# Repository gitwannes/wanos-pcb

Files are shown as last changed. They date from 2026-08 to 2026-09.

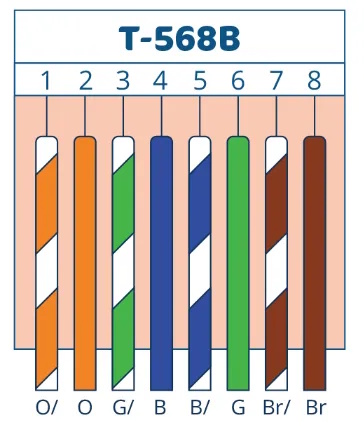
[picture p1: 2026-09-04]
docs/reference/datasheets/rj45-t568b-wiring-colors.jpg

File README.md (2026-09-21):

# wanos-pcb



KiCad design and JLCPCB fabrication for **wanos-pcb-v1** — first-generation WanOS Pi carrier.

**Today:** WanOS runs on **WISC** boards (legacy reference in-repo). **Target:** **wanos-pcb-v1** + updated **wanos**. Code → [gitwannes/wanos](https://github.com/gitwannes/wanos).

---

## Repository layout

```text
wanos-pcb/
├── docs/
│   ├── board-spec.md            # wanos-pcb-v1 electrical spec (canonical)
│   ├── remotepcb.md             # wanos-remote plant module
│   ├── field-wiring.md          # JST pinouts + Cat5
│   ├── gpio-interface.md        # Pi BCM map (R2)
│   ├── external-plant.md        # Off-board SSR + 12 V
│   ├── grounding.md
│   ├── reference/
│   │   ├── datasheets/          # PDF pack (gitignored binaries)
│   │   ├── silkscreen/
│   │   └── wisc-board/
│   └── todo/
├── projects/wanos-board/        # Main Pi carrier
│   ├── wanos-board.kicad_pro
│   ├── components.xlsx          # BOM: column board = main | remote
│   └── …
├── projects/wanos-remote/       # Plant remote (pulse + 1-Wire)
│   ├── wanos-remote.kicad_pro
│   ├── wanos-remote.kicad_sch
│   └── design.yaml
└── README.md
```

---

## Pipeline (summary)

| Step | Id | What |
|---|---|---|
| ~~…~~ | ~~**R / Ops1 / S / Gate-S1**~~ | ~~Requirements + main schematic~~ **Done** **2026-09-21** |
| **1** | **Ops-Remote1** | Operator: clean + check **wanos-remote** schematic |
| **2** | **L1** | Main carrier PCB layout |
| **3** | **Gate-L1** | Layout sign-off |
| **4–5** | **Ops2, J1** | Fab readiness + JLCPCB order |
| **6** | **Ops3** | Receiving inspection |
| **7–8** | **V1a, V1b** | Bring-up / extended software |

Full backlog → [`docs/todo/pipeline.md`](docs/todo/pipeline.md).

---

## Quick links

| Doc | Purpose |
|---|---|
| [`docs/board-spec.md`](docs/board-spec.md) | **wanos-pcb-v1** specification |
| [`docs/remotepcb.md`](docs/remotepcb.md) | **wanos-remote** plant module |
| [`docs/gpio-interface.md`](docs/gpio-interface.md) | Pi BCM + software strategy (**wanos-pcb-v1**) |
| [`docs/gpio-map.md`](docs/gpio-map.md) | WISC production BCM inventory |
| [`docs/external-plant.md`](docs/external-plant.md) | DIN SSR + 12 V plant |
| [`docs/field-wiring.md`](docs/field-wiring.md) | Connector pinouts |
| [`docs/schematic-signoff.md`](docs/schematic-signoff.md) | Gate-S1 record (Done) |
| [`docs/reference/datasheets/README.md`](docs/reference/datasheets/README.md) | Datasheet pack |
| [`docs/kicad-setup.md`](docs/kicad-setup.md) | Konnect + KiCad 10 (**Ops1** Done) |
| [`projects/wanos-board/components.xlsx`](projects/wanos-board/components.xlsx) | BOM / LCSC seed |

---

## Workflow

1. ~~**`kickoff` / S1 / Gate-S1**~~ — **Done** (schematic signed **2026-09-21**).
2. **Ops-Remote1** — operator cleans + checks [`projects/wanos-remote/`](projects/wanos-remote/).
3. **`implement` L1** — main carrier layout (after Gate-S1).
4. **`V1a`** — board + updated **wanos**; cutover from WISC.

**DoD (every phase):** audit all `docs/**/*.md` + this README.

---

## Related repos

| Repo | Role |
|---|---|
| [gitwannes/wanos](https://github.com/gitwannes/wanos) | Runtime (WISC today; wanos-pcb-v1 at **V1a**) |
| [Konnect](https://github.com/mixelpixx/Konnect) | KiCad MCP automation |

---

## License

Source available — personal use OK, no redistribution. See [LICENSE](LICENSE).

Copyright (c) 2026 [Johan Wannes Hofmans](https://github.com/gitwannes). All rights reserved.

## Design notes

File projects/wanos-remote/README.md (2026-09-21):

<!-- --- file: projects/wanos-remote/README.md --- -->

# wanos-remote

Universal plant remote PCB: **4×** opto pulse + **4×** DS18B20 (DS2482-800), Cat5 to main **TCA9548A**.

| Doc | Role |
|---|---|
| [`docs/remotepcb.md`](../../docs/remotepcb.md) | Canonical design locks |
| [`design.yaml`](design.yaml) | Project intent |
| [`components.xlsx`](../wanos-board/components.xlsx) | BOM — filter **`board=remote`** |

## KiCad

- Project: `wanos-remote.kicad_pro`
- Schematic: `wanos-remote.kicad_sch` (A3)
- Symbols: `wanos-remote.kicad_sym` (DS2482-800, TLP281-4)
- Regenerate schematic: `python projects/wanos-remote/_regen_schematic.py`

## Instances

| Board | Mux | Use |
|---|---|---|
| #1 | U5 ch 5 | 4× water YF + 2× pipe temp |
| #2 | U5 ch 6 | 2× kWh S0 + 1× temp |

Same PCB / same I²C straps (`MCP 0x22`, `DS2482 0x18`). Never enable ch 5 and 6 together.

## Status

Schematic **v0.1** — **Ops-Remote1** (operator): clean in KiCad, run ERC, check vs [`docs/remotepcb.md`](../../docs/remotepcb.md). Layout not started (40×60 hold).

Pipeline: [`docs/todo/pipeline.md`](../../docs/todo/pipeline.md) Sequence #1.

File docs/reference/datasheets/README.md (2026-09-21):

<!-- --- file: docs/reference/datasheets/README.md -->

# Datasheet pack — wanos-pcb-v1

Operator reference PDFs for board design, JLCPCB ordering, and external-plant documentation.

**Home:** `docs/reference/datasheets/` (not under `projects/` — PDFs are reference material, not KiCad project outputs).

**Git:** large PDF binaries may be local-only; keep this README as the checklist. Drop PDFs in this folder locally.

**Naming:** all PDF/JPG filenames **lowercase** (ASCII).

---

## Inventory

### On-board ICs and semiconductors

| Done | Part | Filename |
|:---:|---|---|
| [x] | NXP **PCA9554PW** (I/O expander) | `pca9554.pdf` |
| [x] | TI **TCA9548A** (I²C mux) | `tca9548a.pdf` |
| [x] | **PC817A** (12 V opto, U4) | `pc817a.pdf` |
| [x] | **PN2222A** (SSR driver) | `pn2222a.pdf` |
| [x] | **SMBJ12A** (12 V TVS, **D3**) | `smbj12a.pdf` |
| [x] | **PESD5V0S1BA** (water SIG TVS, **D25**–**D28**) | `pesd5v0s1ba.pdf` |
| [x] | **SMBJ5.0A** (water **`+5VA`** TVS, **D29**) | `smbj5.0a.pdf` |
| [x] | **BLM21PG331SN1** (Pi 5 V ferrite) | `blm21pg331sn1.pdf` |

### Connectors

| Done | Part | Filename |
|:---:|---|---|
| [x] | Molex **208658-1052** (HDMI J1, LCSC **C6990958**) | `molex-208658-1052.pdf` |
| [x] | JST **XH** series (B2B/B4B/B5B/B6B-XH-A, 2.50 mm) | `jst-xh-series.pdf` |
| [x] | **KF301** screw terminal (J14 2P) | `kf301.pdf` |
| [x] | 2×20 **40-pin** female header (J40) | `40-female-header.pdf` |
| [x] | Amphenol **54602** RJ45 (KiCad footprint class for **J4**) | `amphenol-54602.pdf` + `amphenol-54602-drawing.pdf` |
| — | TE **5556416-1** (orderable **J4** MPN) | **Not required** — BOM/LCSC is enough; Amphenol **54602** docs are the land-pattern authority for the KiCad fp |

### Field wiring aids

| Done | What | Filename |
|:---:|---|---|
| [x] | T568B colour reference (water Cat5 → **J4**) | `rj45-t568b-wiring-colors.jpg` |

### Plant and external (for `docs/external-plant.md`)

| Done | Part | Filename |
|:---:|---|---|
| [x] | Omron **G3PJ-225B DC12-24** (DIN SSR) | `external/omron-g3pj.pdf` |
| [x] | **SHT3x** (Sensirion — SHT31 plant sensor) | `external/sht3x.pdf` |
| [x] | **YF-B6 / YF-B10** water flow sensor | `external/YF-B6 B10 waterflow-sensor.pdf` |
| [x] | Eastron **SDM72D-M** (kWh pulse meter) | `external/sdm72d-m.pdf` |
| [x] | Sibratec **DDS-1Y-18L** (1-ph kWh, S0-style pulse) | `external/dds-1y-18l.pdf` |
| [x] | Finder **7E.12.8.230.0002** (1-ph kWh, SO DIN 43864) | `external/finder-7e.12.8.230.0002.pdf` |

### Pi power (R2 lock — J41 DNP v1)

| Done | Part | Filename |
|:---:|---|---|
| [x] | **BZX85C5V6** family / **BZT52C5V6** (5 V zener, **D1**) | `bzx85c.pdf` |
| [x] | **1N400x** family (legacy reference; reverse block replaced by **Q6** ideal diode on wanos v1) | `1n400x.pdf` |
| [ ] | USB-C receptacle **J41** (LCSC part from `components.xlsx`) | `usb-c-j41.pdf` — **deferred** (J41 DNP v1) |

---

## Relevance notes (water / J4)

| File | Relevant? | Role |
|---|---|---|
| `pesd5v0s1ba.pdf` | **Yes** | SIG TVS **D25**–**D28** on `water_meters.kicad_sch` |
| `smbj5.0a.pdf` | **Yes** | **`+5VA`** TVS **D29** at **J4** |
| `amphenol-54602.pdf` / `-drawing.pdf` | **Yes** | Land-pattern / outline for KiCad fp `Connector_RJ:RJ45_Amphenol_54602-x08_Horizontal` (proxy for TE **5556416-1**) |
| `rj45-t568b-wiring-colors.jpg` | **Yes** | Operator colour aid for [`field-wiring.md`](../../field-wiring.md) § 2a |
| TE **5556416-1** PDF | **Not needed** | Orderable MPN is locked in BOM/LCSC; Amphenol **54602** already covers the footprint you are using |

---

## Status

**On disk:** water TVS pair (**PESD** + **SMBJ5.0A**), Amphenol **54602** fp refs, T568B colour jpg, and plant kWh PDFs (**SDM72D-M**, **DDS-1Y-18L**, Finder **7E.12**) present. Deferred only: **`usb-c-j41.pdf`** (J41 DNP v1).

---

## Related

- BOM seed: [`projects/wanos-board/components.xlsx`](../../projects/wanos-board/components.xlsx)
- HDMI / e-ink: [`hdmi-spi-eink.md`](../../hdmi-spi-eink.md)
- Components: [`component-selection.md`](../../component-selection.md)
- R2 tracking: [`todo/_archive/phaseR-requirements.md`](../../todo/_archive/phaseR-requirements.md) § R2

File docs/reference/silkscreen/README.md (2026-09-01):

<!-- --- file: docs/reference/silkscreen/README.md -->

# wanos-pcb-v1 — silkscreen reference

Silkscreen typography and artwork for **wanos-pcb-v1**, matching legacy **WISC** boards.

---

## PCB font (same as WISC)

Use **Printed Circuit Board 7** on silkscreen labels (connector names, revision text, short field hints).

| Resource | Link |
|---|---|
| **Font (FontSpace)** | [Printed Circuit Board 7](https://www.fontspace.com/printed-circuit-board-7-font-f15777) |
| Shortcut (Windows) | [`PCBfont.url`](PCBfont.url) |

Install the font on the KiCad workstation so PCB Editor can render the same face as WISC production boards.

**KiCad:** set default silkscreen font to this typeface where practical; minimum text height per [`board-spec.md`](../../board-spec.md) § 8.2 (**≥ 1.0 mm**).

---

## Logo artwork (wanos-pcb-v1)

| File | wanos-pcb-v1 |
|---|---|
| [`Wannes-PCB-logo.png`](Wannes-PCB-logo.png) | **Use** — front silk (from WISC library) |
| [`Wisclogo_small`](../wisc-board/211201%20wisc2-5-3/Wannes-library.pretty/Wisclogo_small.kicad_mod) | **Use** — front + back (WISC parity) |
| `W annes illiams.jpg` / inverted variant | Optional author mark |
| [`Cc-by-nc-sa_icon.svg.png`](Cc-by-nc-sa_icon.svg.png) | **Not used** on wanos-pcb-v1 (WISC reference only; repo [`LICENSE`](../../../LICENSE) is not CC) |

Footprint sources live under [`../wisc-board/211201 wisc2-5-3/Wannes-library.pretty/`](../wisc-board/211201%20wisc2-5-3/Wannes-library.pretty/) — copy **Wannes-PCB-logo** and **Wisclogo_small** into `projects/wanos-board/` at **L1 implement**, do not edit reference KiCad trees.

---

## Related

- [`board-spec.md`](../../board-spec.md) § 8 — fab + silk rules
- [`kicad-setup.md`](../../kicad-setup.md) — tooling
- WISC 2.5.3 production summary → [`../wisc-board/wisc-v5-2-5-3-production.md`](../wisc-board/wisc-v5-2-5-3-production.md)

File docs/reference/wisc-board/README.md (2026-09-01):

<!-- --- file: docs/reference/wisc-board/README.md -->

# WISC board reference

Structured notes and **read-only KiCad** projects for legacy **WISC** hardware. **Current WanOS** runs on WISC in the field — mainly the **2.5.3 I/O carrier** plus the **2.6.4 HDMI board** on the Pi that drives **LCD screens**.

**Read-only rule:** Do not edit KiCad sources here — see [`.cursor/rules/wisc-boards-readonly.mdc`](../../../.cursor/rules/wisc-boards-readonly.mdc). New design work lives in `projects/wanos-board/` (wanos-pcb-v1).

**Target spec:** [`board-spec.md`](../../board-spec.md) · **GPIO:** [`gpio-interface.md`](../../gpio-interface.md) · **Field wiring (wanos):** [`field-wiring.md`](../../field-wiring.md)

---

## Reference boards

| Summary | KiCad tree | Role |
|---|---|---|
| [**wisc-v5-2-5-3-production.md**](wisc-v5-2-5-3-production.md) | [`211201 wisc2-5-3/`](211201%20wisc2-5-3/) | **Main I/O carrier** — SSR, doors, meters, SHT11 |
| [**wisc-v2-6-4-hdmi.md**](wisc-v2-6-4-hdmi.md) | [`220313 wisc2-6-4-HDMI/`](220313%20wisc2-6-4-HDMI/) | **LCD Pi** node (85×56); **4-pin I²C J7** pinout reference for wanos |

Fab exports, cache, history, backups → [`_donotcommit/`](_donotcommit/) (gitignored).

---

## How to use

1. **R2 / V1a** — confirm harness parity vs [`field-wiring.md`](../../field-wiring.md).
2. **S1 / L1 implement** — copy **patterns** (SSR 5-pin, JST silk, debounce), not whole schematics, into `projects/wanos-board/`.
3. **4-pin I²C pinout** — use **2.6.4 J7** only (not 2.5.3 SHT11 DATA/CLOCK headers).

Silkscreen font (WISC + wanos) → [`../silkscreen/README.md`](../silkscreen/README.md).

Migration narrative (planned R2): `docs/cutover-wisc-to-wanos-pcb-v1.md`.

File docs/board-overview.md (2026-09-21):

<!-- --- file: docs/board-overview.md -->

# WanOS PCB — overview

**wanos-pcb-v1** is the first-generation WanOS Raspberry Pi carrier board designed in this repo (KiCad + JLCPCB).

| Hardware | Role |
|---|---|
| **WISC 2.5.3** | Main **field-I/O** carrier — SSR, doors, meters, SHT11 ([`reference/wisc-board/`](reference/wisc-board/)) |
| **WISC 2.6.4 HDMI** | **LCD Pi** node — **powers Pi only** today; legacy e-ink **broken** (HDMI not connected) |
| **wanos-pcb-v1** | **New** integrated carrier — replaces split WISC setup + failed HDMI/e-ink path |

Application logic stays in [gitwannes/wanos](https://github.com/gitwannes/wanos). Operator continues on **WISC** until **wanos** is updated for this board (**V1a**). **R1** + **R2** closed **2026-09-01**.

---

## What wanos-pcb-v1 provides

- Digital inputs (doors, water meters, 2× kWh, buttons) via **PCA9554** expanders
- **SHT31 × 5** via **TCA9548A** mux and Cat5 plant cables (~4–5 m); **J16** LCD on root I²C
- SSR drives (3-phase sauna + IR) via Pi GPIO
- **12 V** rail monitoring (optocoupler → Expander B P6)
- **1×** I²C LCD header (two displays paralleled on **J16**)
- WISC e-ink via HDMI→SPI — legacy path failed in the field; see [`hdmi-spi-eink.md`](hdmi-spi-eink.md)
- Status and activity LEDs

Canonical electrical spec → [`board-spec.md`](board-spec.md).

---

## Documentation map

| Doc | Content |
|---|---|
| [`board-spec.md`](board-spec.md) | Full wanos-pcb-v1 electrical / mechanical spec |
| [`field-wiring.md`](field-wiring.md) | JST pinouts, Cat5, mux channels (**R1**) |
| [`component-selection.md`](component-selection.md) | JLCPCB parts and footprints |
| [`hdmi-spi-eink.md`](hdmi-spi-eink.md) | WISC e-ink HDMI→SPI |
| [`io-expander-map.md`](io-expander-map.md) | PCA9554 + TCA9548 map |
| [`gpio-interface.md`](gpio-interface.md) | Pi BCM map + software strategy (**R2**) — **wanos-pcb-v1** |
| [`gpio-map.md`](gpio-map.md) | WISC production BCM inventory (claimed / free / 1-wire) |
| [`remotepcb.md`](remotepcb.md) | **wanos-remote** — plant pulse + 1-Wire module (Cat5 / U5) |
| [`external-plant.md`](external-plant.md) | Off-board SSR + 12 V plant + kWh inventory |
| [`grounding.md`](grounding.md) | Ground / return scheme |
| [`reference/datasheets/README.md`](reference/datasheets/README.md) | Datasheet pack |
| [`reference/silkscreen/README.md`](reference/silkscreen/README.md) | Silkscreen font + artwork |
| [`reference/wisc-board/`](reference/wisc-board/) | WISC summaries + read-only KiCad |
| [`jlcpcb-ordering.md`](jlcpcb-ordering.md) | Fab export checklist |
| [`kicad-setup.md`](kicad-setup.md) | KiCad 10, Konnect, Cursor MCP |
| [`todo/pipeline.md`](todo/pipeline.md) | Delivery pipeline (**Ops-Remote1** → **L1** → …) |

**V1a close-out (planned):** `docs/installer-one-pager.md`, `docs/cutover-wisc-to-wanos-pcb-v1.md`.

---

| Artifact | Location |
|---|---|
| KiCad project (main carrier) | `projects/wanos-board/` |
| KiCad project (**remote**) | `projects/wanos-remote/` |
| BOM seed (`board` = main \| remote) | `projects/wanos-board/components.xlsx` |
| Fabrication outputs | `projects/wanos-board/fabrication/` |

---

## Out of scope (this repo)

- WanOS Python / YAML (main repo)
- WISC legacy PCB **edits** (read-only under [`reference/wisc-board/`](reference/wisc-board/); see [`.cursor/rules/wisc-boards-readonly.mdc`](../.cursor/rules/wisc-boards-readonly.mdc))
- Enclosure mechanical design (no constraint locked at R2)

---

## License

Source available — personal use OK, no redistribution. See [LICENSE](../LICENSE) and [wanos](https://github.com/gitwannes/wanos).

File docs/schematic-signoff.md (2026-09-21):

<!-- --- file: docs/schematic-signoff.md -->

# Schematic sign-off checklist (Gate-S1)

Operator review of **`projects/wanos-board/`** hierarchical sheets before **L1** layout.

**How:** open each `.kicad_sch` in KiCad (or export PDF), check connectivity, refs, and nets vs [`field-wiring.md`](field-wiring.md) / [`board-spec.md`](board-spec.md). ERC: [`projects/wanos-board/wanos-board-erc.rpt`](../projects/wanos-board/wanos-board-erc.rpt).

| Done | Sheet file | What |
|:---:|---|---|
| [x] | [`pi_power.kicad_sch`](../projects/wanos-board/pi_power.kicad_sch) | **J17** + **J14** screw terminals; 5 V conditioning (**F1** / **Q6** / **D1**), **FB1**, **J40**; **D3** TVS; status **D23** / **D24**; 12 V monitor **U4** → Exp B P6 |
| [x] | [`ssr_drivers.kicad_sch`](../projects/wanos-board/ssr_drivers.kicad_sch) | **Q1–Q5**, **R14–R16**, **C8–C12**, **`SAFETY_BUS`** / **J13**; SSR activity **D19–D22** / **R25–R28** (see [`board-spec.md`](board-spec.md) § 4.1, § 5.3) |
| [x] | [`io_expanders.kicad_sch`](../projects/wanos-board/io_expanders.kicad_sch) | **U1**/**U2**, water **J4**, buttons **J8**; legacy door/kWh stubs pending retire |
| [x] | [`pulse_inputs.kicad_sch`](../projects/wanos-board/pulse_inputs.kicad_sch) | Greenfield **J2**/**J3** reed + **J6**/**J7** SDM72 front-ends |
| [x] | [`hdmi_spi.kicad_sch`](../projects/wanos-board/hdmi_spi.kicad_sch) | **J1** HDMI / e-ink SPI |
| [x] | [`i2c_plant.kicad_sch`](../projects/wanos-board/i2c_plant.kicad_sch) | **U5** TCA9548A, **C6**, **R11** RESET pull-up, **J9–J12**/**J18** SHT31, **J16** LCD (root bus) |
| [x] | [`wanos-board.kicad_sch`](../projects/wanos-board/wanos-board.kicad_sch) | Root hierarchy (no separate **Connectors** / **LEDs** sheets) |

**Signed off:** **2026-09-21** / **Wannes** — Gate-S1 closed; S track archived.

**Note:** After sign-off, retire duplicate **J2/J3/J6/J7** stubs on [`io_expanders.kicad_sch`](../projects/wanos-board/io_expanders.kicad_sch) when cutting over to [`pulse_inputs.kicad_sch`](../projects/wanos-board/pulse_inputs.kicad_sch) (operator tidy — not blocking Gate-S1).

Pipeline: [`docs/todo/_archive/phaseS-schematic.md`](todo/_archive/phaseS-schematic.md) (Done) · next Sequence **Ops-Remote1** → [`docs/todo/pipeline.md`](todo/pipeline.md)

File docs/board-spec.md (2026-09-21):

<!-- --- file: docs/board-spec.md -->

# WanOS PCB — board specification

**Revision:** **wanos-pcb-v1** (first-generation WanOS carrier; replaces ad-hoc / **WISC**-era wiring on a new board — not a spin of the old WISC PCB).

Structured specification for KiCad 10 + Konnect, manufactured via JLCPCB. **Target:** **Raspberry Pi 4** on **85 × 56 mm** outline (WISC 2.6.4 mechanical reference).

**Related:** Overview → [`board-overview.md`](board-overview.md) · Components → [`component-selection.md`](component-selection.md) · Field wiring → [`field-wiring.md`](field-wiring.md) · HDMI→SPI → [`hdmi-spi-eink.md`](hdmi-spi-eink.md) · I/O map → [`io-expander-map.md`](io-expander-map.md) · GPIO contracts → [`gpio-interface.md`](gpio-interface.md) · Silkscreen → [`reference/silkscreen/README.md`](reference/silkscreen/README.md)

**R1 locks:** 2026-09-01 · **R2 locks:** 2026-09-01 — [`todo/_archive/phaseR-requirements.md`](todo/_archive/phaseR-requirements.md) § R2 shipped summary.

---

## 1. System overview

WanOS is a Raspberry-Pi-based home-automation controller for sauna, bathroom, cinema, and water systems.

**wanos-pcb-v1** provides:

- Digital inputs (doors, water meters, kWh meters, buttons) via **PCA9554** expanders
- **SHT31** temperature/humidity (5×) via **TCA9548A** mux + Cat5 plant cables
- SSR control outputs (3-phase sauna + IR)
- **12 V** sauna rail monitoring (optocoupler hard-lock)
- **1×** I²C LCD header (two displays paralleled)
- E-ink display via repurposed HDMI connector (WISC SPI)
- Status and activity LEDs

**Board size:** **85 × 56 mm** (Pi-compatible outline; **not** a HAT stack).

**Software note:** Operator continues **WanOS on WISC** until **wanos** is updated for this board. **One Pi** replaces the former two-Pi WISC split. GPIO / I²C map → [`gpio-interface.md`](gpio-interface.md).

---

## 2. Power architecture

### 2.1 Rails

#### 5 V (stable, independent)

- Powers Raspberry Pi
- Powers logic (PCA9554PW, TCA9548A, LEDs, I²C sensors on local bus)
- Must **remain powered** when sauna safety triggers
- External **5 V** via **J17** screw terminal → input conditioning → **`+5VA`**
- **Pi** fed via **J40** header pins **2 & 4** (header injection; **J41** USB-C **DNP** v1)

#### 12 V (sauna SSR rail)

- Powers SSR opto-inputs
- Cut by external temperature safety
- Must be **monitored** by the PCB
- Loss of 12 V → Pi stays alive → WanOS logs critical event + stops sauna
- Sauna remains **hard-locked** until manual reset via UI/software

### 2.2 12 V monitoring (R1 lock)

Optocoupler (**U4**) on **`pi_power.kicad_sch`** → **Expander B P6** (`EXP_B_P6_12V_MON`).

- 12 V (**`+12V`** at **J14**) → **R32 1k5** → optocoupler LED
- Transistor → pull-up to 3.3 V → **Expander B pin P6**
- Optional RC: 10 kΩ + 100 nF
- Part: **PC817A** class (see [`reference/datasheets/pc817a.pdf`](reference/datasheets/pc817a.pdf))

**Logic:** LOW = 12 V present; HIGH = 12 V missing → hard-lock.

---

## 3. Inputs

### 3.1 Door sensors

- **2×** 2-pin JST (**J2** sauna, **J3** bathroom) — pin 1 GND, pin 2 signal
- Reed switches, 100 nF debounce, **Expander A** P1/P0

### 3.2 Water meters — bathroom 1 and 2

- **Sensor:** **YF-B6 / YF-B10** hall flow meter — OD pulse, supply **5–15 V** ([datasheet](reference/datasheets/external/YF-B6%20B10%20waterflow-sensor.pdf))
- **J4** — TE **5556416-1** RJ45 (LCSC **C86492**); **one Cat5 ~10 m** for all four meters — pinout / colours [`field-wiring.md`](field-wiring.md) § 2a
- **Front-end** on **`water_meters.kicad_sch`**: per channel **PESD5V0S1BA** TVS ([`pesd5v0s1ba.pdf`](reference/datasheets/pesd5v0s1ba.pdf)), **10 kΩ** pull-up to **`+3V3`**, **330 Ω** series, **100 nF** debounce, activity LED **1k0** — **no MOSFET**; **SMBJ5.0A** on **`+5VA`** at **J4**
- **Expander A** P2–P5 (`EXP_A_P2`…`P5`)
- **J5** unused v1

### 3.3 kWh counters (main + aux)

- **PCB:** **2** pulse inputs only — **J6** (main), **J7** (aux); ~**10 m Cat5** each → Expander A **P6** / **P7**
- **Plant inventory** (may include meters **not** wired to wanos): SDM72D-M, DDS-1Y-18L, Finder **7E.12.8.230.0002** — [`external-plant.md`](external-plant.md) § 5a
- **Front-end design reference:** Eastron **SDM72D-M** S0 / passive opto — [`sdm72d-m.pdf`](reference/datasheets/external/sdm72d-m.pdf); needs external DC (**5–27 V** class) — board pull-up on **`+5VA`**, not `+3V3` alone
- **Target front-end (drawn on `pulse_inputs.kicad_sch`):** 10 kΩ pull-up to **`+5VA`**, 330 Ω series, 100 nF debounce, PESD TVS, activity LED **1k0** from **`+5VA`** — [`field-wiring.md`](field-wiring.md) § 2b
- **Other plant meters:** same SO class may be usable on **J6/J7**, but check voltage band and imp/kWh (DDS published **10–30 V** — not a drop-in on **`+5VA`**)
- Retire incomplete **J6**/**J7** stubs on **`io_expanders`** when cutting over

### 3.3a Doors (reed)

- **J2** / **J3** — reed to GND; front-end on **`pulse_inputs.kicad_sch`**: 10 kΩ to **`+3V3`**, 330 Ω, 100 nF, PESD, activity LED — [`field-wiring.md`](field-wiring.md) § 2c

### 3.4 Buttons (sauna LCD)

- **J8** — 4-pin JST (3 buttons + GND); Cat5 UTP harness
- **Expander B** P0–P2; pinout → [`field-wiring.md`](field-wiring.md) § 5

### 3.5 SHT31 sensors (5×)

- Bathroom, cinema, sauna mid, sauna high, spare (**J18** location TBD)
- **TCA9548A** (**U5**) @ **`0x70`** — 8-ch mux; ch **0–4** used, ch **5–7** NC
- **J9–J12**, **J18** — 5× 4-pin JST, WISC **2.6.4 J7** I²C pinout
- **J16** LCD stays on root Pi I²C (not behind the mux)
- **~4–5 m Cat5** per sensor; all modules at I²C **`0x44`**
- **100 kHz** Standard mode; **no PCA9615** on v1
- Detail → [`field-wiring.md`](field-wiring.md) § 7

---

## 4. Outputs

### 4.1 SSR channels (4× field + on-board safety gate)

**External:** 4× **Omron G3PJ-225B** DIN SSRs — coil **+** common **`+12V`**, coil **−** per channel via **J13** pins 2–5 ([`external-plant.md`](external-plant.md)). **No** fifth external SSR.

**On-board drivers** (`ssr_drivers.kicad_sch`):

| Ref | Role | BCM |
|---|---|---:|
| **Q5** | Safety gate — arms field drivers when on | **4** |
| **Q4** | IR coil return | **14** |
| **Q3** | Sauna phase U | **15** |
| **Q2** | Sauna phase V | **17** |
| **Q1** | Sauna phase W | **18** |

**Hardware safety interlock** (not a fifth SSR coil):

- **Q5** (**PN2222A**): emitter **GND**, collector **`SAFETY_BUS`** (shared with **Q1–Q4** emitters).
- **Q1–Q4**: emitters on **`SAFETY_BUS`**; collectors on **`SSR_*`** → **J13** pins 2–5.
- **BCM 4** high → **Q5** on → **`SAFETY_BUS`** pulled toward GND → field GPIOs can sink coil current.
- **BCM 4** low → **`SAFETY_BUS`** floats high via **R16** (10 kΩ to **`+5VA`**) → field drivers cannot energize coils even if GPIO 14/15/17/18 are high.
- **R14** 470 Ω (**GPIO_SSR_SAFETY** → **Q5** base), **R15** 10 kΩ base pulldown to **GND**.
- **No** on-board activity LED on the safety path (§ 5).

**Field channels:** **Pi GPIO** → **R1–R4** 470 Ω → **Q1–Q4** bases; **R5–R8** 10 kΩ base–emitter on each channel.

**J13** — **5-pin** JST vertical (**B5B-XH-A**); pin **1** = **GND** — [`field-wiring.md`](field-wiring.md) § 6.

**Decoupling:** **C8–C12** 100 nF collector–emitter per **Q1–Q5**.

**SSR activity LEDs:** **D19–D22** / **R25–R28** on this sheet (§ 5.3).

12 V SSR opto supply; software PWM ~1–5 Hz on sauna phases.

### 4.2 E-ink (HDMI → SPI)

See [`hdmi-spi-eink.md`](hdmi-spi-eink.md). Panel **+5 V** (HDMI pin **18**) via **F2** 500 mA polyfuse from **`+5VA`**.

### 4.3 LCD (2× modules, 1× header)

- **J16** — single **4-pin** I²C JST; both LCD tails wired in parallel (deployed practice)
- WISC **2.6.4 J7** pinout; distinct backpack I²C addresses required
- **No second LCD header on v1**

### 4.4 Pi power

- **J17** — **KF301-2P** screw terminal: external **5 V** in (+ / GND)
- Conditioning: **F1** 2 A polyfuse (SMD 1206, resettable), **Q6** `AO3401A` ideal diode (reverse block, ~mΩ drop), **D1** `BZT52C5V6` (overvoltage shunt), **C1** 100 µF bulk, **FB1** ferrite → **`+5VA`** / **`+5V-PI`** at **J40**
- **J40** 40-pin header — **`+5V-PI`** on pins **2 & 4** powers Pi (post-**FB1**); remaining pins = GPIO / I²C / SSR / e-ink
- **J41** USB-C — **DNP** v1 (not populated)

---

## 5. Indicator LEDs

**14** visible indicators (2 status + 12 activity). **No** activity LED on the **BCM 4** / **Q5** safety path. **Four** SSR activity LEDs (**IR** + phases **U/V/W**) on **J13** channels.

### 5.1 Status (dim)

On **`pi_power.kicad_sch`**. Resistors: **R29** = **2k0** (**+5VA**); **R30** = **6k8** (**+12V** — matched brightness).

| LED | Indicates |
|---|---|
| 5 V in | **`+5VA`** post-**F1** (PSU + polyfuse OK; self-resets after overcurrent) |
| 12 V | **`+12V`** at **J14** (external PSU input, after field temp safety) |

**D25** dropped — was a duplicate **`+5VA`** indicator (same rail as **D23**).

### 5.2 Field input activity

**Eight** LEDs total, resistors **1k0**, anode on **`+3V3`**, cathode on the logic/input net (lights when input is low).

| Group | Count | LEDs / R | Sheet | Signals |
|---|---:|---|---|---|
| Doors | 2 | D11–D12 / R17–R18 | `io_expanders.kicad_sch` | J2 sauna, J3 bathroom |
| Water B1 / B2 | 4 | D13–D16 / R19–R22 | `water_meters.kicad_sch` | **J4** RJ45 cold + hot ×2 |
| kWh | 2 | D17–D18 / R23–R24 | `io_expanders.kicad_sch` | J6 main, J7 aux |

### 5.3 SSR activity (`ssr_drivers.kicad_sch`)

**Four** LEDs (**D19–D22**), resistors **R25–R28** = **1k0** (target **2k0** when all indicators move to **`+5VA`** — see § 5.1), anode on **`+5VA`**, cathode on **`SSR_*`** (12 V coil-return domain).

| LED | R | Net | Driver |
|---|---|---|---|
| D22 | R28 | `SSR_IR` | **Q4** |
| D21 | R27 | `SSR_PHASE_U` | **Q3** |
| D20 | R26 | `SSR_PHASE_V` | **Q2** |
| D19 | R25 | `SSR_PHASE_W` | **Q1** |

When the driver is off, the LED can see **~7 V reverse** (12 V net vs 5 V rail). Typical 0805 indicators are specced under **5 V** reverse — field risk is **indicator failure only**, not SSR switching.

**Further revisions (optional):** add a **series reverse-blocking diode** (e.g. 1N4148 class, SOD-123) in each SSR activity string **only if** bring-up or field use shows LED degradation or failures. **Not required for v1.**

---

## 6. Electrical design rules

### 6.1 I²C

- **PCA9554PW × 2**, **TCA9548A**, **J16** LCD tap on **local bus**
- Pull-ups: **2k2** on **SCL** and **SDA** only (**R9**, **R10** on **`io_expanders.kicad_sch`**)
- VCC decoupling: **C3**/**C4** (PCA9554 **U1**/**U2**), **C6** (**U5** mux); **R11** 10 kΩ **`~RESET`** pull-up on **U5** — [`io-expander-map.md`](io-expander-map.md) § 6
- **100 kHz**; keep I²C away from SSR/12 V zone

### 6.2 SSR area

- **C8–C12:** 100 nF across collector–emitter of each **Q1–Q5**
- **R16:** 10 kΩ **`+5VA`** → **`SAFETY_BUS`** (field-driver emitter rail)
- Ferrite on Pi 5 V; **SMBJ12A** on 12 V input

### 6.3 Safety

- EN 60335-2-53 context; no mains on PCB
- 12 V monitor fail-safe; hard-lock until manual reset

---

## 7. Functional placement (85 × 56 mm)

| Zone | Content |
|---|---|
| **Left** | Pi **J40**, HDMI **J1**, **J17** 5 V screw |
| **Top** | U1, U2, U5, I²C pull-ups, **J16**, **J9–J12**, **J18**, decoupling |
| **Right** | **J2–J4**, **J6–J8** field inputs, activity LEDs |
| **Bottom** | **J14** 12 V (**pi_power**), **J13** SSR, **Q1–Q5**, SSR activity **D19–D22**, **U4** opto, **D3** TVS |
| **Center** | Routing keep-out; lock HDMI before Freerouting |

Silkscreen font → [`reference/silkscreen/README.md`](reference/silkscreen/README.md).

---

## 8. Manufacturing (JLCPCB)

| Parameter | Value |
|---|---|
| Layers | 2 |
| Size | 85 × 56 mm |
| Thickness | 1.6 mm |
| Finish | ENIG |
| Soldermask | Green |
| Silkscreen | White; **`wanos-pcb-v1.0`** + Wannes logos — [`reference/silkscreen/README.md`](reference/silkscreen/README.md) |
| Min text height | ≥ 1.0 mm |

DRC → [`projects/wanos-board/constraints.md`](../projects/wanos-board/constraints.md).

**JLCPCB assembly (R2):** full **PCBA** — SMD + through-hole (**J40**, JST, **J14**, HDMI **J1**) unless revised at **Ops2/J1**.

---

## 9. Summary

| Doc | Content |
|---|---|
| [`field-wiring.md`](field-wiring.md) | JST pinouts, Cat5, mux channels |
| [`component-selection.md`](component-selection.md) | Parts and footprints |
| [`external-plant.md`](external-plant.md) | Off-board SSR + 12 V plant + kWh inventory |
| [`grounding.md`](grounding.md) | Ground / return scheme |
| [`gpio-interface.md`](gpio-interface.md) | Pi BCM + software strategy |
| [`io-expander-map.md`](io-expander-map.md) | Expander + mux map |
| [`components.xlsx`](../projects/wanos-board/components.xlsx) | BOM seed |

Konnect + KiCad 10 for schematic, layout, DRC, and fab export.

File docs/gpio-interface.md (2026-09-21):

<!-- --- file: docs/gpio-interface.md -->

# wanos-pcb-v1 — GPIO and field interface

**R2 lock (2026-09-01):** full-board **BCM** map for **wanos-pcb-v1** schematic and future WanOS on this PCB.

Field connectors → [`field-wiring.md`](field-wiring.md) · Expander pins → [`io-expander-map.md`](io-expander-map.md) · E-ink HDMI pins → [`hdmi-spi-eink.md`](hdmi-spi-eink.md)

---

## Software strategy

| Phase | WanOS hardware | Notes |
|---|---|---|
| **Today** | **WISC** boards | [wanos `config_hardware.yaml`](https://github.com/gitwannes/wanos/blob/main/config_hardware.yaml) — direct GPIO / SHT11 |
| **Cutover** | **wanos-pcb-v1** | Operator updates **wanos** for expanders, SHT31, HDMI SPI — **all** board functions (**V1a** / main repo) |
| **No adapter** | — | No shim to preserve WISC GPIO map on this PCB |

Historical WISC pin map (reference only) → [`gpio-map.md`](gpio-map.md) (full BCM inventory) · short tables [§ WISC legacy](#wisc-legacy-reference-only).

---

## Pi BCM — wanos-pcb-v1 (locked)

### I²C bus (local)

| Signal | BCM | Device |
|---|---:|---|
| SDA | **2** | U1, U2, U5, **J16** LCD |
| SCL | **3** | |

**Addresses:** U1 **PCA9554** `0x20` · U2 **PCA9554** `0x21` · U5 **TCA9548A** `0x70`

### SSR outputs (Pi GPIO)

| Signal | BCM | Field / notes |
|---|---:|---|
| Safety gate (arms **J13** drivers) | **4** | On-board **Q5** / **`SAFETY_BUS`** — **not** J13 |
| IR relay | **14** | J13 pin **5** |
| Sauna phase U | **15** | J13 pin **4** |
| Sauna phase V | **17** | J13 pin **3** |
| Sauna phase W | **18** | J13 pin **2** |

Software PWM ~1–5 Hz on sauna phases.

### E-ink — HDMI J1 → SPI

HDMI **physical pin** → signal per [`hdmi-spi-eink.md`](hdmi-spi-eink.md). **BCM:**

| SPI function | BCM | HDMI pin | Dir |
|---|---:|---:|---|
| DC | **7** | 4 | out |
| CS | **8** | 1 | out |
| MOSI | **10** | 7 | out |
| SCK | **11** | 10 | out |
| BUSY | **24** | 3 | in |
| RST | **25** | 6 | out |
| HPD | — | 19 | tied **GND** on PCB |

### Expander interrupts

**PCA9554 INT** (U1, U2): **NC** on v1 — poll I²C only.

**U2 unused GPIO (P3, P4, P5, P7):** hardware **NC** on v1. At init, configure these pins as **outputs driven LOW** so they do not float.

---

## Logical I/O (not direct GPIO)

| Function | Implementation |
|---|---|
| Doors, water, 2× kWh | **PCA9554** U1 + **J2–J4**, **J6–J7** (water via **`water_meters`** / **J4** RJ45) |
| Sauna LCD buttons | **PCA9554** U2 **P0–P2** + **J8** |
| 12 V presence / hard-lock | Opto **U4** → **U2 P6** |
| SHT31 × 5 | **TCA9548A** U5 + **J9–J12**, **J18** (ch 0–4, sensor @ `0x44`; ch 5–7 NC) |
| LCD × 2 (paralleled) | **J16** I²C (root bus, not muxed) |

---

## WISC legacy (reference only)

Direct **BCM** on production **WISC** — for migration context, **not** wanos-pcb-v1 wiring.  
**Full claimed / free / 1-wire inventory:** [`gpio-map.md`](gpio-map.md).

### Pulse / digital inputs

| Signal | BCM | WanOS idx |
|---|---:|---:|
| kWh meter | 12 | 11001 |
| Cold water | 6 | 11002 |
| Hot water | 5 | 11003 |
| Sauna door | 27 | 10001 |
| Bathroom door | 22 | 10002 |

### SSR (WISC)

| Signal | BCM |
|---|---:|
| Master safety | 4 |
| IR relay | 14 |
| Sauna phase U | 15 |
| Sauna phase V | 17 |
| Sauna phase W | 18 |

### SHT11 (bit-banged on WISC)

| Location | idx | D | C |
|---|---:|---:|---:|
| Sauna high | 20001 | 11 | 25 |
| Sauna low | 20002 | 7 | 8 |
| Cinema | 20003 | 9 | 10 |
| Bathroom | 20004 | 24 | 23 |

---

## Related

- [`gpio-map.md`](gpio-map.md) — WISC production BCM map (canonical)
- [`external-plant.md`](external-plant.md)
- [`board-spec.md`](board-spec.md)
- Delivery: [`todo/phaseV-verify.md`](todo/phaseV-verify.md) § V1a

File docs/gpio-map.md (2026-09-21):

<!-- --- file: docs/gpio-map.md -->

# WanOS GPIO map (current production — WISC)

**Board:** WISC v5 rev **2.5.3** (main I/O carrier).  
**Software SoT:** [wanos](https://github.com/gitwannes/wanos) root [`config_hardware.yaml`](https://github.com/gitwannes/wanos/blob/main/config_hardware.yaml).  
**This file:** canonical **BCM inventory** (claimed / free / 1-wire notes) for production WanOS on WISC — lived in the wanos repo; home is now **wanos-pcb**.  
**wanos-pcb-v1 (new carrier):** [`gpio-interface.md`](gpio-interface.md) — do not treat this map as the v1 pinout.

BCM numbers below are **Raspberry Pi BCM** (same as `config_hardware.yaml` `pin:` / relay keys).  
Header pin = physical 40-pin header position.

WanOS has **no** 1-wire / DS18B20 driver today. Free-pin notes are for **hardware wiring + dtoverlay** only.

---

## All BCM GPIOs — current usage

```
BCM  Header  Status    Usage                          Notes
---  ------  --------  -----------------------------  ------------------------------------------
  0     27   reserved  -                              do not use (ID_SD HAT EEPROM)
  1     28   reserved  -                              do not use (ID_SC HAT EEPROM)
  2      3   free      -                              unused by WanOS; I2C SDA; header only
  3      5   free      -                              unused by WanOS; I2C SCL; header only
  4      7   used      safety_gpio                    master safety contactor
  5     29   used      water_hot                      idx 11003
  6     31   used      water_cold                     idx 11002
  7     26   used      sht11 sauna_low pin_c          idx 20002
  8     24   used      sht11 sauna_low pin_d          idx 20002
  9     21   used      sht11 cinema pin_d             idx 20003
 10     19   used      sht11 cinema pin_c             idx 20003
 11     23   used      sht11 sauna_high pin_d         idx 20001
 12     32   used      kwh_meter                      idx 11001
 13     33   free      -                              candidate 1wire; header pin 33 only (no JST)
 14      8   used      ir_relais                      -
 15     10   used      sauna_relais_phase_U           3500 W
 16     36   free      -                              candidate 1wire; J3 e-ink D0+ (if J3 free)
 17     11   used      sauna_relais_phase_V           3500 W
 18     12   used      sauna_relais_phase_W           2000 W
 19     35   free      -                              candidate 1wire; header pin 35 only (no JST)
 20     38   free      -                              candidate 1wire; J3 e-ink CEC (if J3 free)
 21     40   free      -                              candidate 1wire; J3 e-ink D1+ (if J3 free)
 22     15   used      door_bathroom1                 idx 10002
 23     16   used      sht11 bathroom1 pin_c          idx 20004
 24     18   used      sht11 bathroom1 pin_d          idx 20004
 25     22   used      sht11 sauna_high pin_c         idx 20001
 26     37   free      -                              candidate 1wire; J3 e-ink SDA (if J3 free)
 27     13   used      door_sauna                     idx 10001
```

---

## Free GPIOs (summary)

```
BCM  Access on WISC 2.5.3              Notes
---  --------------------------------  ------------------------------------------
  2  Pi header pin 3                   unused by WanOS; I2C SDA — keep free if I2C planned
  3  Pi header pin 5                   unused by WanOS; I2C SCL — keep free if I2C planned
 13  Pi header pin 33 only             candidate 1wire; no field connector
 16  J3 e-ink D0+ (or header pin 36)   candidate 1wire; prefer if e-ink cable unused
 19  Pi header pin 35 only             candidate 1wire; no field connector
 20  J3 e-ink CEC (or header pin 38)   candidate 1wire; prefer if e-ink cable unused
 21  J3 e-ink D1+ (or header pin 40)   candidate 1wire; prefer if e-ink cable unused
 26  J3 e-ink SDA (or header pin 37)   candidate 1wire; prefer if e-ink cable unused
```

**Not free:** BCM **4** (safety). Linux default `w1-gpio` uses GPIO **4** — **do not** use the default overlay on this Pi.

---

## 1-wire (DS18B20 etc.)

| Item | Guidance |
|---|---|
| **Default overlay pin** | BCM **4** — **blocked** (safety_gpio) |
| **Recommended** | Pick one free pin above; set overlay explicitly, e.g. `dtoverlay=w1-gpio,gpiopin=16` |
| **Easiest field access** | BCM **16 / 20 / 21 / 26** via **J3** when e-ink is disconnected |
| **Header-only** | BCM **13** or **19** (solder / tap Pi header) |
| **I2C pins** | BCM **2 / 3** work electrically but conflict with any future I2C on this bus — avoid unless intentional |
| **WanOS software** | No 1-wire reader / entity path yet — kernel/`w1` only until a ship adds it |

---

## Related

- Runtime pins: [wanos `config_hardware.yaml`](https://github.com/gitwannes/wanos/blob/main/config_hardware.yaml)
- wanos-pcb-v1 board map: [`gpio-interface.md`](gpio-interface.md)
- WISC KiCad (read-only): [`reference/wisc-board/`](reference/wisc-board/)
- Sauna / IR (software): [wanos `docs/sauna-ir.md`](https://github.com/gitwannes/wanos/blob/main/docs/sauna-ir.md)

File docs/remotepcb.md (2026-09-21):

<!-- --- file: docs/remotepcb.md --- -->

# Remote plant PCB — universal pulse + 1-Wire

**Status:** schematic **v0.1** in [`projects/wanos-remote/`](../projects/wanos-remote/). **Next (operator):** clean schematic pin attachments + run ERC + check vs this doc — pipeline **Ops-Remote1**. **No layout yet.** Main carrier layout (**L1**) follows remote schematic check; main PCB *cutover* changes still after remote bring-up.  
**Role:** universal remote module — **4×** opto pulse inputs + **4×** DS18B20 (1-Wire). Same PCB for water and kWh instances.

Today’s main-board water / kWh wiring → [`field-wiring.md`](field-wiring.md), [`io-expander-map.md`](io-expander-map.md).

---

## 1. Intent

| Item | Spec |
|---|---|
| Channels (PCB) | **4×** universal pulse + **4×** DS18B20 footprints (4 of 8 DS2482 channels brought out) |
| Instances | **2×** identical remotes |
| Remote **#1** | **4×** water flow + **2×** pipe temp (2× temp JST unused) |
| Remote **#2** | **2×** kWh S0 + **1×** temp (2× pulse + 3× temp JST unused) |
| Link | **Cat5 UTP ~6 m** → main **RJ45** (#1 reuses **J4**; #2 = second RJ45 on main later) |
| I²C | **U5** TCA9548A — #1 on **ch 5**, #2 on **ch 6** @ **100 kHz** |
| Power | Main **`+12V`** → Cat5 → remote **VIN** → **AP2204K-3.3** → **3V3**; filtered **`S0_RAIL`** for opto + power LED |
| VIN at remote | Target ≈ **12 V**; **minimum 11.5 V** after cable / PPTC (plant supply may be raised to achieve this) |
| 12 V loss | Remote offline when plant 12 V is down (Pi may still run on 5 V) |
| Field connectors | **4× JST 3-pin** pulse + **4× JST 3-pin** temp; uplink **RJ45** |
| Activity LEDs | **4×** + **1×** SMD button (LEDs lit only while pressed) |
| Power LED | Always on from **`S0_RAIL`** |
| MCP INT | **Not used** — no INT wire; WanOS **polls** when mux channel selected |
| MCP GPIO | **GPA0–GPA3** = pulse ch 1–4; remaining GPIO **no nets** (firmware: outputs LOW) |
| DS2482 IO | **IO0–IO3** → temp J6–J9; **IO4–IO7** **NC** (do not tie to GND) |
| VIN TVS | **SMBJ12A** on remote **VIN→GND** at RJ45 (in addition to main port TVS) |
| KiCad project | [`projects/wanos-remote/`](../projects/wanos-remote/) (create on implement) |
| Bring-up | Remote first on **12 V lab supply**; main PCB changes after |

---

## 2. System block

```
  Pi root I²C (R9/R10 2k2)
       |
       +-- U1 PCA9554 0x20  (doors; water/kWh removed after remotes cut over)
       +-- U2 PCA9554 0x21  (buttons / 12 V mon)
       +-- U5 TCA9548A 0x70
       |      ch 0–4 : SHT31 plant (unchanged)
       |      ch 5   : remote #1 (water)  ---- Cat5 ---- RJ45
       |      ch 6   : remote #2 (kWh)    ---- Cat5 ---- RJ45
       |      ch 7   : NC / spare
       +-- J16 LCD (root, not muxed)

  Main per uplink: +12V (plant) -- PPTC -- SMBJ12A -- Cat5 ---- remote VIN

  Remote PCB (identical hardware both instances):
       VIN (≥11.5 V, nom ~12 V) -- input filter
            |-- AP2204K-3.3 --> +3V3 --> DS2482-800 + MCP23017A + logic
            |-- R_S0 / C_S0 --> S0_RAIL --> R_LED ×4 --> TLP281-4
            |                              --> power LED + series R
       Field JST 3-pin ×4 pulse --> S0_RAIL / SIG / GND
       Field JST 3-pin ×4 temp  --> +3V3 / 1-Wire / GND
       (MCP INT pin: NC on board / no Cat5 pair — poll only)
```

---

## 3. Main PCB changes (after remote)

### 3.1 Connectors

| Jack | Role |
|---|---|
| **J4** (redefined) | Uplink remote **#1** → **U5 SD5/SC5** + **`+12V`** + GND |
| Second RJ45 (designator TBD) | Uplink remote **#2** → **U5 SD6/SC6** + **`+12V`** + GND |

Remove today’s water-meter **J4** function (four SIG + `+5VA` into **U1**).  
Jack class: TE **5556416-1** / Amphenol **54602**-class RJ45 TH, no magnetics, no jack LEDs.  
Do **not** put **`+5VA`** on these uplinks. Pair map → § 5 (no INT).

### 3.2 Remove on-main front-ends (cutover)

- Water: drop `water_meters` parts; **U1** **P2–P5**  
- kWh: drop **J6/J7** front-ends; **U1** **P6/P7** when remote #2 is live  
- Doors (**J2/J3**) stay on main for now unless later remapped  

### 3.3 Port protection (locked)

Per remote RJ45 on main:

| Part | Role | Spec |
|---|---|---|
| **PPTC** | Overcurrent | TECHFUSE **`nSMD050-33V`** (LCSC **C70077**) — **500 mA** hold, **1 A** trip, **33 V** max, 1206, R≈150 mΩ |
| **SMBJ12A** | Port **TVS** | **`+12V`** → GND at jack |

Order: plant **`+12V`** → **PPTC** → jack (TVS at connector).

Remote load ≪ 150 mA; **500 mA** hold avoids nuisance trips; **33 V** rating has margin on 12 V (do **not** reuse typical 6–8 V 1206 PPTCs). Drop ≈ **15 mV** at 100 mA.

### 3.4 No INT landing

MCP23017 **INT** not brought to main. No GPIO / pull-up reserved for remote IRQ.

### 3.5 Rail clamps

Port **SMBJ12A** on each uplink **`+12V`**. Do not conflate with Pi **5 V** clamp (**D1**).

---

## 4. Remote PCB — electrical

### 4.1 I/O

| Direction | Count | Path |
|---|---:|---|
| In | 4 | Universal pulse → **TLP281-4** → **MCP23017A** |
| In | 4 | DS18B20 → **DS2482-800** (4 of 8 ch brought out; populate as needed) |
| Uplink | 1 | I²C + **`+12V`** + GND over Cat5 (**no INT**) |

### 4.2 Power

**Cable:** **`VIN` ≥ 11.5 V**, nominal ~**12 V** = main **`+12V`** after PPTC + Cat5 (raise plant PSU if needed).

**VIN clamp (remote):** **SMBJ12A** **VIN → GND** at RJ45 entry (same class as main port TVS). Does not replace main PPTC/SMBJ; local protection for lab bring-up and cable ESD.

#### 4.2.1 **3V3** — **AP2204K-3.3**

```
VIN (11.5–13 V class) → AP2204K-3.3 → +3V3
```

| Item | Spec |
|---|---|
| Part | **AP2204K-3.3** (SOT-23-5), e.g. **AP2204K-3.3TRG1** |
| Vin | **2.3–24 V** (11.5 V min is fine) |
| Iout | **150 mA** |
| EN | Tie to **VIN** (always on) |
| Cin | **47–100 µF** electrolytic + **100 nF** ceramic |
| Cout | Per datasheet (≥ **2.2 µF** ceramic) + **22–47 µF** bulk; **100 nF** at each IC |

Dissipation at ~50 mA ≈ **0.44 W** — copper under SOT-23-5. Activity LEDs gated so continuous load stays low.

#### 4.2.2 **`S0_RAIL`**

```
VIN → R_S0 (10 Ω) → S0_RAIL →|| C_S0 (10 µF + 100 nF) → GND
                              └→ R_LED ×4 → TLP281-4 anodes
                              └→ power LED + series R
```

| Ref | Value | Role |
|---|---|---|
| **R_S0** | **10 Ω**, 1%, 0.125 W | Soft RC with **C_S0**; limits HF dump into rail |
| **C_S0** | **10 µF** + **100 nF** | Bulk + HF at opto / power LED |

Drop at 4× ~2.3 mA ≈ **0.1 V** across **10 Ω** — fine. Keep **C_S0** and LED returns close to the TLP281-4; star field GND away from digital return.

Used for **R_LED**, pulse JST pin 1 (**VDD** / loop supply), and **power LED**.

#### 4.2.3 No remote 5 V rail

YF-B6 VDD (**5–15 V**) = **`S0_RAIL`** on the pulse JST.

#### 4.2.4 Power LED (always on)

From **`S0_RAIL`** — shows plant loop supply present (tracks opto / meter domain).

| Item | Spec |
|---|---|
| Series R | **4.7 kΩ**–**6.8 kΩ** (brightness class vs main **R30** on `+12V`) |
| Gating | **Not** gated by test button |

### 4.3 ICs and addresses (**locked**)

| IC | Role | I²C addr |
|---|---|---|
| **TLP281-4** | Quad optocoupler | — |
| **DS2482-800** | 1-Wire master | **`0x18`** (AD2/AD1/AD0 = 0) |
| **MCP23017A** | I/O expander | **`0x22`** (A2/A1/A0 strapped; avoid `0x20`/`0x21`) |
| **AP2204K-3.3** | 12 V → **3V3** | — |

Same straps on **both** remotes. Safe because only one of **U5 ch 5 / ch 6** is enabled at a time.  
**Never** enable ch 5 and ch 6 together (same addresses → bus fight).

**MCP23017A:** order **A** die (SOIC-28); avoid unmarked legacy **MCP23017**.  
**INTA/INTB:** **NC**.  
**Address straps for `0x22`:** A2=0, A1=1, A0=0 (hard-tie).  
**GPIO:** **GPA0–GPA3** → `PULSE_CH1`–`PULSE_CH4`; other GPA/GPB pins **no copper nets** (init as outputs LOW in firmware).

**DS2482-800:** AD2/AD1/AD0 = 0 → **`0x18`**. **IO0–IO3** → temp JST data; **IO4–IO7** leave **unconnected** (1-Wire open-drain ports — do **not** tie to GND).

Address formulas (reference): DS2482 `0001 1 [11][10][9]` → `0x18`–`0x1F`; MCP `0100 [17][16][15]` → `0x20`–`0x27`.

### 4.4 I²C

| Item | Spec |
|---|---|
| Speed | **100 kHz** |
| Pull-ups | **2k2** on main **R9/R10** only; **none** on remote |
| Series | **22 Ω** on SDA/SCL at remote |
| Mux | #1 visible on **ch 5**; #2 on **ch 6** |

### 4.5 1-Wire

| Item | Spec |
|---|---|
| Active IO | **IO0–IO3** → J6–J9 data |
| Pull-up | **2k2** to **`+3V3`** on IO0–IO3 at DS2482 |
| Unused IO | **IO4–IO7** **NC** (unconnected — not GND) |
| Power | Powered probes via temp JST **`+3V3`** (not parasite by default) |

### 4.6 Universal pulse (4× around one **TLP281-4**)

Same PCB channel for S0 kWh, YF-B6 / hall OD, and dry contacts. Idle **HIGH**, active **LOW** at MCP. WanOS **polls** GPIO (no INT).

#### 4.6.1 Logic side (per channel)

| Ref | Value | Role |
|---|---|---|
| Opto | **TLP281-4** one ch | Isolation |
| **R_IN** | **470 Ω**, 1%, 0.125 W | Series to MCP |
| **R_PU** | **10 kΩ**, 1%, 0.125 W | Pull-up to **`+3V3`** |
| **C_RC** | **100 nF**, X7R, 50 V | Debounce (optional 220 nF) |
| **D_ESD** | **ESD5B5.0ST5G** (or equiv.) | `PULSE_CHx` → GND |

- Emitter → GND  
- Collector → **R_IN** → **`PULSE_CHx`** → MCP GPIO  
- **`PULSE_CHx`** → **R_PU** → **`+3V3`**; → **C_RC** → GND; → **D_ESD** → GND  

#### 4.6.2 Field side (12 V LED)

| Ref | Value |
|---|---|
| **R_LED** | **4.7 kΩ**, 1%, **0.25 W** from **`S0_RAIL`** to opto LED anode |

≈ **2.3 mA** at 12 V (Vf ≈ 1.2 V); still OK at **11.5 V** VIN / `S0_RAIL`.

| Source | Wiring |
|---|---|
| **S0 kWh** | Cathode → meter S0 out; other terminal → GND / loop return per meter |
| **YF-B6** | JST VDD = **`S0_RAIL`**; cathode → SIG; sensor OD → GND |
| **Dry contact** | Cathode → contact → GND |

#### 4.6.3 Activity LEDs + test button

| Item | Spec |
|---|---|
| LEDs | **4×** SMD activity — sense **`PULSE_CHx`** (active LOW) |
| Button | **1×** SMD tactile — enables activity-LED supply only |
| Series R | **1 kΩ** per activity LED |
| Power LED | From **`S0_RAIL`** — § 4.2.4 |

**Topology:** button closes a shared **anode rail** (`+3V3` → button → LED anodes). Each cathode → **1 kΩ** → **`PULSE_CHx`**. While button open, no activity-LED current.

### 4.7 Connection map

**Pulse JST — 3-pin:**

| Pin | Net |
|---|---|
| 1 | **`S0_RAIL`** (VDD / loop supply) |
| 2 | **SIG** (opto LED cathode) |
| 3 | **GND** |

**Temp JST — 3-pin:**

| Pin | Net |
|---|---|
| 1 | **`+3V3`** |
| 2 | **1-Wire data** |
| 3 | **GND** |

**TLP281-4 (SO16):**

| Ch | LED A / C | Collector / Emitter |
|---|---|---|
| 1 | 1 / 2 | 10 / 9 |
| 2 | 3 / 4 | 12 / 11 |
| 3 | 5 / 6 | 14 / 13 |
| 4 | 7 / 8 | 16 / 15 |

### 4.8 Decoupling / misc

- **100 nF** at each IC VCC; bulk on **3V3** near DS2482 / MCP  
- MCP **INTA/INTB**: **NC** (unused)

---

## 5. Cat5 UTP (~6 m) — pair map (**locked**)

| Pair | Colors (T568B-oriented) | Signal |
|---|---|---|
| **1** | White/Green + Green | **SDA + GND** |
| **2** | White/Orange + Orange | **SCL + GND** |
| **3** | White/Blue + Blue | **`+12V` (VIN) + GND** |
| **4** | White/Brown + Brown | **GND + GND** (ex-INT pair — both to GND; improves return) |

Same map both remotes. **Logical** assignment is colour/pair above; **numeric** RJ45 pin 1–8 depends on the jack footprint’s pad numbering (KiCad `RJ45_Amphenol_54602-x08_Horizontal` / TE **5556416-1**) — lock pad↔net in schematic when the footprint is placed, not before.

---

## 6. Channel map (**locked**)

### 6.1 U5 mux

| U5 ch | Use |
|---|---|
| 0–4 | SHT31 plant |
| **5** | Remote **#1** (water) |
| **6** | Remote **#2** (kWh) |
| 7 | NC / spare |

### 6.2 Remote #1 — water

| Pulse JST | Function | Temp JST | Function |
|---|---|---|---|
| 1 | Bath 1 cold (YF) | 1 | Pipe temp A |
| 2 | Bath 1 hot (YF) | 2 | Pipe temp B |
| 3 | Bath 2 cold (YF) | 3 | **Unused** |
| 4 | Bath 2 hot (YF) | 4 | **Unused** |

### 6.3 Remote #2 — kWh

| Pulse JST | Function | Temp JST | Function |
|---|---|---|---|
| 1 | kWh main (S0) | 1 | Temp probe |
| 2 | kWh aux (S0) | 2 | **Unused** |
| 3 | **Unused** | 3 | **Unused** |
| 4 | **Unused** | 4 | **Unused** |

---

## 7. Physical

| Item | Spec |
|---|---|
| Size | **40 × 60 mm** (**hold** — fit check later) |
| Connectors | **1× RJ45**; **8× JST 3-pin** (4 pulse + 4 temp) |
| Placement | RJ45 short edge; JST opposite / long edge; ICs center |
| Layout | Star / split GND for S0 returns; short I²C; ESD at connectors |

---

## 8. DS18B20 mounting

- Paste between probe and copper sleeve; firm spring contact; clean pipe surface  
- Insulate sleeve + pipe; strain-relieve ~2 m leads  
- Stable flow section — avoid mixing, pumps, tight bends  

---

## 9. Software / WanOS

| Topic | Spec |
|---|---|
| Remote #1 | **U5 ch 5** → MCP **`0x22`** (water) + DS2482 **`0x18`** (2 temps) |
| Remote #2 | **U5 ch 6** → same addresses (kWh + 1 temp) |
| Mux | **Exclusive** select — never ch 5+6 together |
| Counting | **Poll** MCP GPIO; software edges only |
| Schedule | Prefer water poll cadence for edge capture; kWh slow; temps/SHT31 lower priority |
| Idxs | Keep legacy idxs; change hardware backend |

---

## 9a. KiCad / BOM

| Item | Path |
|---|---|
| KiCad project | [`projects/wanos-remote/`](../projects/wanos-remote/) |
| BOM | [`components.xlsx`](../projects/wanos-board/components.xlsx) — `board=remote` |
| Regenerate sch | `python projects/wanos-remote/_regen_schematic.py` |

## 10. Open items

1. **Hold** — **40×60** mechanical fit / layout.  
2. KiCad **ERC cleanup** — attach global labels to IC pins (generator places labels nearby).  
3. RJ45 **pad↔net** verify vs footprint when laying out.  
4. Power LED brightness on bench (R18 **6k8**).  
5. Verify / fill **LCSC** for **DS2482-800** and JST **B3B-XH-A**.  
6. Product docs on main cutover (`field-wiring`, `board-spec`, `io-expander-map`, `gpio-interface`).  
7. Main: second RJ45 + per-port **PPTC/SMBJ12A** when main work starts.  
8. Pipeline: `triage` when scheduled.

---

## 11. Design notes / VIN check

- **11.5 V min at remote VIN:** OK for **AP2204K-3.3**, YF (**5–15 V** on `S0_RAIL`), S0 (**5–27 V**), and opto LED current with **4.7 kΩ**. Raising plant 12 V to compensate Cat5/PPTC drop is fine; keep remote VIN **≤ ~15 V** practical headroom for YF on `S0_RAIL` (YF abs max 15 V — do not crank plant so high that `S0_RAIL` exceeds sensor rating).  
- Opto + single **4.7 kΩ** from **`S0_RAIL`** covers S0, hall OD, and dry contact.  
- Port: **PPTC** + **SMBJ12A**. **`S0_RAIL`:** **10 Ω + 10 µF ‖ 100 nF**.  
- I²C: 100 kHz, pair-with-GND, root 2k2, 22 Ω series; **no INT**.  
- Bring-up: **12 V lab PSU** into remote VIN pins / RJ45 before main respin.

---

## 12. Verbatim locks

**2026-09-21**

- UTP pair map = § 5; remove INT altogether; PPTC **nSMD050-33V** + **SMBJ12A** OK.  
- VIN at remote close to 12 V, **≥ 11.5 V** OK (raise plant 12 V as needed).  
- Addresses **`0x18` + `0x22`** locked both remotes.  
- Mux ch 5 / 6; #1 = 4 water + 2 temp; #2 = 2 kWh + 1 temp.  
- Power LED from **`S0_RAIL`**; bench on **12 V lab supply**; remote board before main PCB.

**2026-09-21 (schematic readiness)**

- MCP **GPA0–GPA3** = pulses; other GPIO no nets / firmware LOW.  
- DS2482 **IO0–IO3** → temps; **IO4–IO7** unconnected (not GND).  
- Project path **`projects/wanos-remote/`**.  
- **SMBJ12A** TVS on remote VIN as well as main.

---

## Related

- [`field-wiring.md`](field-wiring.md)  
- [`io-expander-map.md`](io-expander-map.md)  
- [`gpio-interface.md`](gpio-interface.md)  
- [`board-spec.md`](board-spec.md)  
- [`todo/pipeline.md`](todo/pipeline.md)

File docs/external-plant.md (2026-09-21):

<!-- --- file: docs/external-plant.md -->

# wanos-pcb-v1 — external plant (off-board)

Off-board wiring for sauna **12 V DC plant**, **DIN SSRs**, and independent **temperature safety**. Locked at **R2** (2026-09-01).

**On-board connectors:** [`field-wiring.md`](field-wiring.md) · **Ground returns:** [`grounding.md`](grounding.md) · **Board spec:** [`board-spec.md`](board-spec.md)

**Datasheets:** SSR → [`reference/datasheets/external/omron-g3pj.pdf`](reference/datasheets/external/omron-g3pj.pdf) · kWh meters → § 5a · pack index → [`reference/datasheets/README.md`](reference/datasheets/README.md)

---

## 1. Overview

| Item | Role |
|---|---|
| **12 V PSU** | Sauna SSR **coil** supply (not Pi logic) |
| **Temp safety** | Independent hardware — **cuts 12 V** on overtemperature; **not** controlled by WanOS |
| **wanos PCB** | Monitors 12 V (opto **U4**); drives **4×** SSR coil returns via **J13**; **BCM 4** on-board safety gate (**Q5**) |
| **4× DIN SSR** | Switch **mains** heater / IR loads — **not** on PCB |

---

## 2. External SSR modules

**Part (locked):** **Omron G3PJ-225B DC12-24** × **4** on DIN rail.

| wanos channel | J13 pin | Typical load |
|---|---:|---|
| Sauna phase **W** | 2 | Heater phase W |
| Sauna phase **V** | 3 | Heater phase V |
| Sauna phase **U** | 4 | Heater phase U |
| **IR** relay | 5 | IR / auxiliary heater |

**J13 pin 1** = **GND** (control return). Pinout → [`field-wiring.md`](field-wiring.md) § 6.

### Coil wiring (DC 12 V)

- **Coil +** (all four modules): common **`+12V`** from PCB (same rail as **J14** after field safety).
- **Coil −** (each module): individual return via **J13** pins 2–5 — PCB sinks current through **PN2222A** when the matching Pi GPIO is active.
- Coil rating **12–24 V DC** — site uses **12 V** plant.

### AC load

- Mains connections **only** at SSR **load** terminals — qualified installer; **no mains** on wanos PCB.

### On-board safety gate (BCM 4)

WanOS **arms** the four field SSR drivers by asserting **BCM 4** high. That turns **Q5** on and pulls the shared **`SAFETY_BUS`** (emitters of **Q1–Q4**) toward **GND**, so the field GPIOs can sink coil current when active.

- **R16** (10 kΩ **`+5VA`** → **`SAFETY_BUS`**) holds the bus high when **Q5** is off.
- There is **no** fifth G3PJ module and **no** safety coil net on **J13**.
- Independent **12 V** hard-lock: external temp safety + opto **U4** on **`pi_power`** (§ 3) — separate from **BCM 4** / **Q5**.

---

## 3. 12 V plant — J14

**J14** — **KF301-2P** screw terminal on **`pi_power.kicad_sch`** (with **D3** TVS at entry).

| Pin | Signal |
|----:|---|
| **1** | **`+12V`** — 12 V **after** external temp safety |
| **2** | **GND** — 12 V return |

### Field wiring

```text
PSU (+) ---> [external temp safety - NC] ---> J14-1 (+12V)
PSU (-)  -----------------------------------> J14-2 (GND)
```

When safety opens, **`+12V`** at **J14** falls to **0 V** → opto **U4** on **`pi_power`** → **EXP_B_P6** → WanOS **hard-lock** (Pi / 5 V stay up).

---

## 4. Temperature safety (independent)

- **Not** implemented on wanos PCB.
- Site **over-temperature** device breaks the **12 V positive** path **before** **J14** (series insert).
- WanOS **does not** control this interlock; it only **detects** loss of 12 V.

---

## 5. Harness reuse (migration from WISC)

| Harness | Reuse |
|---|---|
| **SSR J1 → J13** | Reuse if 5-pin JST tail fits (same pinout) |
| **Doors, water, kWh** | Reuse where pinout matches; water is **YF-B6/B10** on **one Cat5** → **J4** RJ45 — [`field-wiring.md`](field-wiring.md) § 2a (not legacy dual 6-pin JST) |
| **SHT11 plant → SHT31** | Re-terminate or replace tails (**SDA/SCL** vs DATA/CLOCK) — [`field-wiring.md`](field-wiring.md) § 7 |
| **Two-Pi WISC** | **One Pi** on wanos-pcb-v1 (I/O + e-ink integrated) |

---

## 5a. kWh meters (plant inventory)

Site may have **more than two** energy meters. **Not all need a pulse run to wanos.** PCB has **two** pulse inputs (**J6** main, **J7** aux) — wiring and software map → [`field-wiring.md`](field-wiring.md) § 2b · [`board-spec.md`](board-spec.md) § 3.3.

This section is **plant reference** (which devices exist / how their S0 ports behave). It does **not** lock which meter is on which JST.

| Part | Role (typical) | Datasheet | Pulse / S0 (from datasheet) | Notes vs wanos **J6/J7** (`+5VA` pull-up) |
|---|---|---|---|---|
| **Eastron SDM72D-M** | 3-ph / multi-param DIN meter (also RS485 Modbus) | [`sdm72d-m.pdf`](reference/datasheets/external/sdm72d-m.pdf) | Configurable pulse; default **1000 imp/kWh**; passive opto needs external DC | **Design reference** for the drawn front-end (docs historically used **5–27 V**, ~**27 mA**, ~**35 ms**). Compatible with **`+5VA`** rail class. |
| **Sibratec DDS-1Y-18L** | 1-ph DIN, LCD, pulse for PLC | [`dds-1y-18l.pdf`](reference/datasheets/external/dds-1y-18l.pdf) | Specs: **2000 /kWh**, width **~90 ms**; PLC use **10–30 V DC**, **~27 mA** (limits also cite max **60 V DC** / **50 mA**); terminals **20/21**; ≤**20 m** without amp | **Do not assume** drop-in on **`+5VA`**: published operating band starts at **10 V**. Faceplate text shows **1000 imp/kWh** while body text says **2000** — confirm on the physical unit before software constants. |
| **Finder 7E.12.8.230.0002** | 1-ph 10(25) A, 2-module, SO open-collector (DIN **43864**) | [`finder-7e.12.8.230.0002.pdf`](reference/datasheets/external/finder-7e.12.8.230.0002.pdf) | External **5–30 V DC**, max **20 mA**; SO **2000 imp/kWh**, pulse **~100 ms** (7E.12 row); cable up to **1000 m** at 30 V / 20 mA | Voltage class **OK** with **`+5VA`**. Imp/kWh and pulse width differ from SDM72 defaults — software must match the wired meter. |

**wanos pulse class:** passive / SO open-collector, polarity-aware, idle open, pulse closes to return — same electrical story as § 2b. **Modbus** on the SDM72 is plant-side only on v1 (no RS485 on the carrier).

---

## 6. Safety assumptions (EN 60335-2-53 context)

Informal hardware assumptions only — **not** a compliance sign-off.

| Topic | Assumption |
|---|---|
| Heater power | External **DIN SSRs**; no mains on wanos PCB |
| Over-temperature | **Independent** device cuts **12 V** off-board |
| WanOS | Logic + monitoring; **hard-lock** when 12 V missing; manual reset via UI |
| Formal CE / product marking | **Operator responsibility** — out of scope for this repo |

---

## 7. Cabinet environment

PCB in **low-voltage control cabinet** (not in hot steam zone). **No** conformal coat on v1. External thermal cutoff remains off-board (§ 4).

---

## Related

- [`grounding.md`](grounding.md)
- [`gpio-interface.md`](gpio-interface.md)
- Legacy production reference → [`reference/wisc-board/`](reference/wisc-board/) (intent / migration only)

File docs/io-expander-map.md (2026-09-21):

<!-- --- file: docs/io-expander-map.md -->

# wanos-pcb-v1 — I/O expander schematic block

Two **PCA9554PW** expanders plus **TCA9548A** I²C mux on the Pi local bus. Ready for KiCad sheet **IO_EXPANDERS** (R1 locked **2026-09-01**).

Field pinouts → [`field-wiring.md`](field-wiring.md).

---

## 1. Common I²C bus (local)

- Nets: `I2C_SCL`, `I2C_SDA` (from Raspberry Pi 40-pin header, BCM3/BCM2)
- Pull-ups: **2k2** to 3.3 V on SCL and SDA (**R9**, **R10**) — sized for 4–5 m Cat5 on mux channels @ 100 kHz
- Devices on local bus:
  - PCA9554PW Expander A (**U1**)
  - PCA9554PW Expander B (**U2**)
  - **TCA9548A** mux (**U5**, address **`0x70`**)
  - **J16** LCD I²C (both modules paralleled on one 4-pin header; root bus, not muxed)

**Not on v1:** PCA9615 differential driver (**U3** omitted).

**KiCad sheet:** [`io_expanders.kicad_sch`](../projects/wanos-board/io_expanders.kicad_sch) — **U1**, **U2**, **J4** water, **J8** buttons, **R9**/**R10**, **C3**/**C4**. Door/kWh **greenfield** front-ends → [`pulse_inputs.kicad_sch`](../projects/wanos-board/pulse_inputs.kicad_sch) (remove legacy **J2/J3/J6/J7** stubs here when adopting). **TCA9548A** (**U5**) + **C6** + **R11** + **J9–J12**/**J18**/**J16** on [`i2c_plant.kicad_sch`](../projects/wanos-board/i2c_plant.kicad_sch).

### PCA9554 address straps (hardware pins — not GPIO)

Address = `0x20 + (A2<<2) + (A1<<1) + A0`. **Direct tie** to **`+3V3`** or **GND** — no address pull resistors on v1.

| IC | I²C addr | Pin 1 (A0) | Pin 2 (A1) | Pin 3 (A2) |
|---|---|---|---|---|
| **U1** | `0x20` | GND | GND | GND |
| **U2** | `0x21` | **`+3V3`** | GND | GND |

| Pin | Both ICs |
|---|---|
| **8** | GND |
| **9** (INT) | **NC** v1 — polled I²C only |
| **16** (VCC) | **`+3V3`** + **100 nF** to GND (**C3** @ U1, **C4** @ U2) |

---

## 2. PCA9554PW — Expander A (meters + doors + kWh)

**Part:** `U1` — PCA9554PW (TSSOP-16) on **`io_expanders.kicad_sch`**  
**Power:** pin **16** → **`+3V3`** (**C3** 100 nF); pin **8** → GND  
**I²C address:** `0x20` (A0–A2 = low — § 1)

| Pin | Net | Field |
|---|---|---|
| P0 | `EXP_A_P0_DOOR_BATH` | Bathroom door (**J3**) |
| P1 | `EXP_A_P1_DOOR_SAUNA` | Sauna door (**J2**) |
| P2 | `EXP_A_P2_WM_B1_COLD` | Bathroom 1 cold (**J4** RJ45) |
| P3 | `EXP_A_P3_WM_B1_HOT` | Bathroom 1 hot (**J4**) |
| P4 | `EXP_A_P4_WM_B2_COLD` | Bathroom 2 cold (**J4**) |
| P5 | `EXP_A_P5_WM_B2_HOT` | Bathroom 2 hot (**J4**) |
| P6 | `EXP_A_P6_KWH_MAIN` | kWh main (**J6**) — S0 pulse (design ref SDM72D-M; plant inventory → [`external-plant.md`](external-plant.md) § 5a); front-end → [`field-wiring.md`](field-wiring.md) § 2b |
| P7 | `EXP_A_P7_KWH_AUX` | kWh aux (**J7**) — same |

**Doors / kWh activity LEDs:** **D11**–**D12**, **D17**–**D18** / **R17**–**R18**, **R23**–**R24**. **kWh target:** full RC + TVS + **`+5VA`** pull-up (§ 2b) — not yet on schematic (today only LED path).

### Water meters (YF-B6/B10)

Canonical: [`field-wiring.md`](field-wiring.md) § 2a.

| Field net | Series | Pull-up | Debounce | TVS | Activity | Expander net |
|---|---|---|---|---|---|---|
| `WM_B1_COLD` | **R41** 330 Ω | **R37** 10k → **`+3V3`** | **C18** 100 nF | **D25** | **D13** / **R19** | `EXP_A_P2_WM_B1_COLD` |
| `WM_B1_HOT` | **R42** 330 Ω | **R38** 10k | **C19** 100 nF | **D26** | **D14** / **R20** | `EXP_A_P3_WM_B1_HOT` |
| `WM_B2_COLD` | **R43** 330 Ω | **R39** 10k | **C20** 100 nF | **D27** | **D15** / **R21** | `EXP_A_P4_WM_B2_COLD` |
| `WM_B2_HOT` | **R44** 330 Ω | **R40** 10k | **C21** 100 nF | **D28** | **D16** / **R22** | `EXP_A_P5_WM_B2_HOT` |

Sensor **VDD** = **`+5VA`** on **J4** (RJ45 pin **4**); **D29** **SMBJ5.0A** clamps **`+5VA`** at the jack. Output is **open-drain** — **no MOSFET**. Idle HIGH, pulse LOW. Cat5 map → [`field-wiring.md`](field-wiring.md) § 2a.

### Door / kWh activity LEDs (this sheet)

| Refs | Value | Nets |
|---|---|---|
| **D11**–**D12**, **R17**–**R18** | 1k0 | **J2** sauna door, **J3** bathroom door |
| **D17**–**D18**, **R23**–**R24** | 1k0 | **J6** kWh main, **J7** kWh aux |

Status LEDs (**D23**/**D24**) on **`pi_power.kicad_sch`**; SSR activity (**D19**–**D22**) on **`ssr_drivers.kicad_sch`**.

---

## 3. PCA9554PW — Expander B (buttons + 12 V monitor)

**Part:** `U2` — PCA9554PW (TSSOP-16) on **`io_expanders.kicad_sch`**  
**Power:** pin **16** → **`+3V3`** (**C4** 100 nF); pin **8** → GND  
**I²C address:** `0x21` (A0 = high, A1–A2 = low — § 1)

| Pin | Net | Field |
|---|---|---|
| P0 | `EXP_B_P0_BTN1` | Sauna LCD button 1 (**J8**) |
| P1 | `EXP_B_P1_BTN2` | Sauna LCD button 2 (**J8**) |
| P2 | `EXP_B_P2_BTN3` | Sauna LCD button 3 (**J8**) |
| P3 | — | **NC** v1 |
| P4 | — | **NC** v1 |
| P5 | — | **NC** v1 |
| P6 | `EXP_B_P6_12V_MON` | **12 V opto monitor (U4)** — safety-critical |
| P7 | — | **NC** v1 |

**Buttons:** Active-low to **GND** when pressed (**J8**). Pull-up **R34**–**R36** (10 kΩ → **`+3V3`**) on **P0**–**P2**.

**Unused GPIO (P3, P4, P5, P7):** hardware **NC** — no nets, no pull resistors. Firmware: configure as **output LOW** at PCA9554 init (see [`gpio-interface.md`](gpio-interface.md)).

### 3.1 Pull-up strategy (why not every pin?)

| Pin group | Pull bias | Why |
|---|---|---|
| **I²C** SCL/SDA | **R9**/**R10** 2k2 | Bus requirement — not GPIO |
| **Exp A** doors / kWh | **Target:** 10k pull-up + RC (§ [`field-wiring.md`](field-wiring.md) 2b for kWh on **`+5VA`**) | Today: LED path only — incomplete for ~10 m Cat5 |
| **Exp A** water P2–P5 | **R37**–**R40** 10k | YF OD → pull to **`+3V3`** (not 5 V) |
| **Exp B** P0–P2 (buttons) | **R34**–**R36** 10 kΩ | Switch shorts to **GND** when pressed |
| **Exp B** P6 (12 V mon) | **R33** on **`pi_power.kicad_sch`** | Opto open-collector output |
| **Exp B** P3–P5, P7 | **NC** — no hardware bias | Unused; firmware drives **LOW** as output |
| Address **A0–A2** | Direct **GND** / **`+3V3`** tie | Strap, not pull resistor |

Do **not** pull YF signal lines to **`+5VA`** into the PCA9554. Do **not** use a MOSFET for YF-B6/B10 (OD already level-safe with 3.3 V pull-up).

---

## 4. 12 V monitor (safety-critical)

**R1 lock:** optocoupler output → **`EXP_B_P6_12V_MON`** only.

- 12 V → **R32** **1k5** → optocoupler LED (**U4** PC817) on **`pi_power.kicad_sch`**
- Transistor → pull-up to 3.3 V → Expander B P6
- Optional RC: 10 kΩ + 100 nF

Logic: **LOW** = 12 V present; **HIGH** = 12 V missing → hard-lock.

---

## 5. SHT31 plant — TCA9548A mux

Five SHT31 modules share I²C address **`0x44`**. **U5** (**TCA9548A**, 8-ch) selects one channel at a time. Channels **5–7** are NC. **J16** LCD stays on the root Pi I²C bus. **`~RESET`** pulled to **`+3V3`** via **R11** 10 kΩ.

| Mux ch | JST | Sensor |
|---:|---|---|
| 0 | **J9** | Bathroom |
| 1 | **J10** | Cinema |
| 2 | **J11** | Sauna mid |
| 3 | **J12** | Sauna high |
| 4 | **J18** | Spare (location TBD) |
| 5–7 | — | NC |

Each used channel: **4-pin JST**, WISC **2.6.4 J7** pinout (GND, SDA, SCL, 3V3) over **~4–5 m Cat5**.

Software: write mux channel select byte to **`0x70`**, then read SHT31 at **`0x44`**.

---

## 6. Decoupling and layout

| Ref | Value | IC | Sheet |
|---|---|---|---|
| **C3** | 100 nF | **U1** VCC | `io_expanders.kicad_sch` |
| **C4** | 100 nF | **U2** VCC | `io_expanders.kicad_sch` |
| **C6** | 100 nF | **U5** VCC | `i2c_plant.kicad_sch` |
| **R11** | 10 kΩ | **U5** `~RESET` → **`+3V3`** | `i2c_plant.kicad_sch` |

One **100 nF** ceramic per digital IC VCC is sufficient; **C5** (duplicate) and **C7** (optional bulk) were dropped. **R11** holds mux RESET inactive (not driven from the Pi on v1).

**Layout:** U1 near **right-edge** field JST inputs; U2 near button + LCD zone; U5 near I²C cluster; SHT31 JSTs grouped on top/right edge.

---

## 7. Net naming (KiCad)

Use the `EXP_A_*` / `EXP_B_*` names in § 2–3. Do not use legacy `EXP_A_P7_KWH_AUX_OR_12V_MON`.

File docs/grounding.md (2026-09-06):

<!-- --- file: docs/grounding.md -->

# wanos-pcb-v1 — grounding and returns

Ground and return scheme for field install. Locked at **R2** (2026-09-01).

**Connectors:** [`field-wiring.md`](field-wiring.md) · **12 V / SSR plant:** [`external-plant.md`](external-plant.md)

---

## 1. Single PCB ground

All of the following tie to **one PCB ground plane** (common **GND**):

- Raspberry Pi **J40** ground pins
- Every field JST **pin 1 GND** (**J2–J3**, **J6–J8**, **J9–J12**, **J18**, **J13** pin 1, **J16**)
- Water **J4** RJ45 GND on pins **2**, **5**, **6** (unshielded jack)
- **J14** pin 2 (12 V return)
- HDMI **J1** shields and repurposed GND pins per [`hdmi-spi-eink.md`](hdmi-spi-eink.md)
- **Q5** emitter (safety gate), opto **U4** return
- **Q1–Q4** emitters on **`SAFETY_BUS`** (not direct **GND** — see § 3)

There is **no** separate “signal ground” vs “power ground” on the PCB for v1.

---

## 2. 12 V DC return

- **J14-2** is the **12 V PSU negative** and PCB **GND**.
- **`+12V`** at **J14-1** is **after** the external temp-safety series insert ([`external-plant.md`](external-plant.md) § 3).
- SSR **coil +** common connects to **`+12V`** on-board; coil **−** returns per channel through **J13** to PCB drivers.

---

## 3. SSR control return

- **J13 pin 1** = **GND** for the 5-pin SSR field harness.
- **J13 pins 2–5** = coil **−** returns; each net is sunk by **Q1–Q4** collectors when the matching Pi GPIO is active **and** the safety gate is armed.
- **`+12V`** (common coil **+**) is on-board from **J14** / plant distribution — not on **J13**.

### Safety bus (`SAFETY_BUS`)

On **`ssr_drivers.kicad_sch`**:

| Node | Connection |
|---|---|
| **Q5** emitter | **GND** |
| **Q5** collector | **`SAFETY_BUS`** |
| **Q1–Q4** emitters | **`SAFETY_BUS`** |
| **R16** | **`+5VA`** → **`SAFETY_BUS`** (10 kΩ pull-up) |

**BCM 4** drives **Q5** (**R14** / **R15** on base). When **Q5** is off, **`SAFETY_BUS`** is high and field drivers cannot pull coil returns low. **BCM 4** is on-board only — not routed to **J13**.

Detail → [`board-spec.md`](board-spec.md) § 4.1 · [`external-plant.md`](external-plant.md) § 2.

---

## 4. Pi and 5 V logic

- Pi powered via **J17** external 5 V → on-board **`+5VA`** → **J40** header pins **2 & 4** (**J41** USB-C **DNP** v1).
- **5 V** and **3.3 V** logic return through Pi header **GND** to PCB plane.
- When **12 V** is cut by temp safety, **5 V** to Pi must **remain** (USB / board supply independent of **`+12V`**).

---

## 5. Field cables

| Cable | Ground practice |
|---|---|
| **JST** doors, kWh, buttons | Pin **1** = GND at PCB |
| **Cat5** water (**J4** RJ45) | GND on pins **2** / **5** / **6**; optional foil → enclosure PE (jack unshielded) |
| **Cat5** SHT31 / buttons | Use designated GND pair; do **not** float shield at both ends |
| **Cat5 shield** (if present) | Bond **board end only** to GND unless install standard says otherwise |

---

## 6. Mains and protective earth

- **AC mains** only at **G3PJ load** terminals — off PCB.
- If the **metal enclosure** is tied to **protective earth (PE)**, bond **PE to PCB GND at one point** near **J14** power entry (installer). WanOS does not sense PE.

---

## 7. Layout / noise

- Keep **J14 / J13 / SSR** zone away from **I²C** ([`board-spec.md`](board-spec.md) § 7).
- **FB1** ferrite on Pi **5 V** path ([`component-selection.md`](component-selection.md)).

---

## Related

- [`external-plant.md`](external-plant.md)
- [`board-spec.md`](board-spec.md) § 2

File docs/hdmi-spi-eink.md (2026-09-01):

<!-- --- file: docs/hdmi-spi-eink.md -->

# wanos-pcb-v1 — HDMI to SPI (WISC e-ink)

The HDMI Type-A connector on **wanos-pcb-v1** is repurposed as a proprietary SPI header for the **WISC** e-ink display (not TMDS video).

**Board context:** [`board-spec.md`](board-spec.md) § 4.2 · **Part:** Molex 208658-1052 (LCSC **C6990958**) → [`component-selection.md`](component-selection.md)

**Pi GPIO (R2 lock):** [`gpio-interface.md`](gpio-interface.md) § E-ink — BCM **7, 8, 10, 11, 24, 25**; HPD (pin 19) → **GND**.

**Legacy WISC reference:** [`reference/wisc-board/wisc-v2-6-4-hdmi.md`](reference/wisc-board/wisc-v2-6-4-hdmi.md)

---

## Legacy WISC / motivation to redesign

**Deployed today (operator, 2026-09-01):** the [**WISC 2.6.4 HDMI board**](reference/wisc-board/wisc-v2-6-4-hdmi.md) is in use on the **Raspberry Pi connected to the LCD screens**. The **HDMI cable is not connected** — the board **only powers that Pi**. **E-ink over HDMI worked in the past** but **does not work any more**; replacing this **HDMI / e-ink** arrangement is **one of the drivers** for **wanos-pcb-v1**.

**wanos-pcb-v1** should treat the legacy HDMI-cable + repurposed-TMDS approach as **failed field history**, not a silent copy target. Lock connector, wiring, and software against verification on the **new** integrated carrier ([`board-spec.md`](board-spec.md) § 4.2).

---

## HDMI to SPI pin mapping

| HDMI pin | Standard HDMI function | Repurposed signal | Engineering rationale |
|---:|---|---|---|
| 10 | TMDS Clock+ | **SCK** | Best-coupled pair → clean edges for SPI clock |
| 12 | TMDS Clock− | **GND (SCK return)** | Tight return path |
| 11 | TMDS Clock Shield | **GND** | Extra ground |
| 7 | TMDS Data0+ | **MOSI (SDI)** | Second-best pair → ideal for MOSI |
| 9 | TMDS Data0− | **GND (MOSI return)** | Tight return path |
| 8 | TMDS Data0 Shield | **GND** | Extra ground |
| 4 | TMDS Data1+ | **DC** | Low-speed |
| 6 | TMDS Data1− | **RST** | Low-speed |
| 5 | TMDS Data1 Shield | **GND** | Ground reference |
| 1 | TMDS Data2+ | **CS** | Low-speed |
| 3 | TMDS Data2− | **BUSY** | Panel status input |
| 2 | TMDS Data2 Shield | **GND** | Ground reference |
| 18 | +5V Power | **VCC (5V)** | Safe for power input |
| 17 | DDC/CEC Ground | **GND** | Power-adjacent ground |
| 13 | CEC | **spare** | Not used v1 |
| 15 | SCL | **spare** | Not used v1 |
| 16 | SDA | **spare** | Not used v1 |
| 14 | Reserved | **spare** | Free |
| 19 | Hot Plug Detect | **GND** | Tied to GND on PCB (R2) |

---

## Engineering notes

- Place **SCK** and **MOSI** on the best TMDS differential pairs for minimal crosstalk and clean edges.
- Convert all “minus” and shield pins to **GND** for stable return paths and reduced EMI.
- DC, RST, CS, BUSY are low-speed control/status signals on lower-quality pairs.
- Use HDMI pin 18 (+5 V) as panel 5 V input only after verifying the WISC board regulator and that the cable has no AC-coupling.
- Keep spare pins for future expansion.

---

## Pi BCM assignment (R2 lock)

| SPI function | BCM GPIO | HDMI pin |
|---|---:|---:|
| **SCK** | 11 | 10 |
| **MOSI** | 10 | 7 |
| **CS** | 8 | 1 |
| **BUSY** | 24 | 3 |
| **RST** | 25 | 6 |
| **DC** | 7 | 4 |

Full table → [`gpio-interface.md`](gpio-interface.md).

---

## Verification requirements (before final release)

1. **Check HDMI cable continuity** — ensure the installed HDMI cable does not include AC-coupling capacitors on TMDS pairs.
2. **Check WISC board conditioning** — ensure the e-ink panel board does not expect TMDS signalling or include series AC coupling.
3. **Confirm voltage domains** — verify WISC logic levels (3.3 V) and that powering via HDMI pin 18 is acceptable.

**Layout:** Lock HDMI/SPI nets before Freerouting ([`board-spec.md`](board-spec.md) § 7.1, § 7.5).

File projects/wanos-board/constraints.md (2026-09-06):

<!-- --- file: projects/wanos-board/constraints.md -->

# PCB / schematic constraints — wanos-pcb-v1

Applies to `projects/wanos-board/`. Canonical spec → [`docs/board-spec.md`](../../docs/board-spec.md). R1 + **R2** locks → [`field-wiring.md`](../../docs/field-wiring.md), [`gpio-interface.md`](../../docs/gpio-interface.md).

---

## Board

- **Revision:** **wanos-pcb-v1.0** (silk)
- **Target Pi:** Raspberry Pi **4** (re-use production unit)
- **2-layer**, **85 × 56 mm**, **1.6 mm**, **ENIG** — outline / **M2.5** holes per WISC **2.6.4** reference
- Pi carrier (not a HAT); mounting **MH1–MH4**

---

## Schematic

- Net names: `EXP_A_*`, `EXP_B_*`, `I2C_SCL`, `I2C_SDA`, `GPIO_SSR_*`, `GPIO_EINK_*` — see [`io-expander-map.md`](../../docs/io-expander-map.md), [`gpio-interface.md`](../../docs/gpio-interface.md)
- SSR outputs: **Pi GPIO** → 470 Ω → PN2222A — **not** expander PWM
- 12 V monitor: **`EXP_B_P6_12V_MON`** (locked)
- PCA9554: **`0x20`** (U1), **`0x21`** (U2); **INT pins NC**
- TCA9548A @ **`0x70`**; five SHT31 plant ports **J9–J12**, **J18** (ch 0–4); **J16** LCD on root I²C
- I²C pull-ups: **2k2** on SCL/SDA only (**R9**, **R10**)
- **No PCA9615** on v1
- **J14** only for 12 V (**J15** dropped)
- **J17** KF301 **5 V** screw in; **J41** USB-C **DNP** v1
- **J40** **+5VA** on pins **2 & 4** (header injection)
- Decoupling: 100 nF per IC; 1 µF bulk near expanders/mux

---

## Footprints

- From [`component-selection.md`](../../docs/component-selection.md) and [`components.xlsx`](components.xlsx)
- SSR **J13**: `JST_XH_B5B-XH-A_1x05_P2.50mm_Vertical` (WISC parity)
- HDMI **J1**: Molex **208658-1052** (LCSC **C6990958**)
- Silkscreen: Wannes logos — **no** CC BY-NC-SA icon ([`reference/silkscreen/README.md`](../../docs/reference/silkscreen/README.md))

---

## Layout zones

[`board-spec.md`](../../docs/board-spec.md) § 7 — Pi left, logic top, field right, SSR/12V bottom.

- Lock HDMI/SPI before Freerouting
- Separate SSR/12V from I²C
- **L2 (pi_power):** **Q6** ideal diode carries **full Pi 5 V current** — wide/short traces **F1 → Q6 → +5VA → FB1** (manual check: [`phaseL-layout.md`](../../docs/todo/phaseL-layout.md) § L2)

---

## Manufacturing

- **JLCPCB:** full **PCBA** including **J40** (R2) — confirm BOM/CPL at **Ops2/J1**

---

## Verification

```powershell
& "C:/Program Files/KiCad/10.0/bin/kicad-cli.exe" sch erc projects/wanos-board/wanos-board.kicad_sch
& "C:/Program Files/KiCad/10.0/bin/kicad-cli.exe" pcb drc projects/wanos-board/wanos-board.kicad_pcb
```

Konnect DRC/ERC also acceptable when documented in phase file.

---

## Safety

- Sauna/IR SSR + 12 V hard-lock nets are **critical**
- No mains on PCB
- Fail-safe 12 V loss detection ([`board-spec.md`](../../docs/board-spec.md) § 2.2)

---

## Tooling

[`docs/kicad-setup.md`](../../docs/kicad-setup.md) — KiCad 10 + Konnect.

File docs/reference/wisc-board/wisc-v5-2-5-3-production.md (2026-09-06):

<!-- --- file: docs/reference/wisc-board/wisc-v5-2-5-3-production.md -->

# WISC v5 — rev 2.5.3 (production)

Summary of the **production WISC** board WanOS runs on today. KiCad sources are **read-only reference** in the repo.

| | |
|---|---|
| **Folder** | [`211201 wisc2-5-3/`](211201%20wisc2-5-3/) |
| **Project** | `wisc-v5.kicad_pro` |
| **Silk revision** | `wv5.0-pv3-d211201` |
| **Date in tree** | 2021-12-01 upload folder name; PCB title block 2012 (legacy) |
| **Status** | **Production** — current WanOS hardware |

**Related:** [`gpio-interface.md`](../../gpio-interface.md) (software pin map) · [`board-spec.md`](../../board-spec.md) (wanos-pcb-v1 target) · Index → [`README.md`](README.md)

---

## 1. Role

- Carrier for Raspberry Pi 4/5-style **40-pin header** (`P1`) — **main WanOS field-I/O** node (SSR, sensors, pulse inputs).
- **Direct Pi GPIO** for pulse inputs, SSR outputs, and **SHT11** bit-banged sensors — no I²C expanders, no SHT31 plant bus, no on-board 12 V opto monitor.
- **E-ink** via dedicated **Molex panel connector** (J3), not HDMI repurposing (see [§ 6 vs wanos-pcb-v1](#6-vs-wanos-pcb-v1)).

**Other Pi in production:** the [**2.6.4 HDMI WISC board**](wisc-v2-6-4-hdmi.md) sits on the **Pi where LCD screens are connected** — today it **only powers that Pi** (HDMI **disconnected**; e-ink **no longer works**). See that summary for deployed context.

Use this board to validate **what WanOS expects today** on the **I/O carrier** (V1a subset). Use [`wisc-v2-6-4-hdmi.md`](wisc-v2-6-4-hdmi.md) for **85×56 mm** outline and historical **HDMI→SPI** wiring.

---

## 2. Mechanical

| Item | Value |
|---|---|
| **Outline (approx.)** | **~74 × 105 mm** (from `Edge.Cuts` in `wisc-v5.kicad_pcb`) |
| **Thickness** | 1.6 mm |
| **Layers** | 2 (F.Cu / B.Cu) |
| **Pi mounting** | 2×20 vertical pin header — board sits as Pi carrier (not HAT stack) |

wanos-pcb-v1 targets **85 × 56 mm** — do **not** assume identical mechanicals.

---

## 3. Power

| Rail / block | Notes |
|---|---|
| **+5 V / +3.3 V** | Pi and logic |
| **+5VA** | Auxiliary 5 V domain (Pi power path) |
| **External 5 V** | J4 (`5V EXT`), 2-pin JST XH |
| **Fuses** | F1 2.5 A, F2 2 A (5×20 mm holders) |
| **Protection** | D3 `1N4002` |
| **Indicators** | Multiple `pwr_Raspi` and `5V_ext` LEDs |

**Not present:** isolated **12 V sauna rail monitor** / optocoupler hard-lock (wanos-pcb-v1 adds this).

---

## 4. Outputs — SSR (Pi GPIO → transistors)

Drive path matches wanos-pcb-v1 intent: **BCM → PN2222A / 2N7000 → external SSR opto inputs**.

| Channel | Schematic label | Driver | Activity LED |
|---|---|---|---|
| Safety | `SSR_safety` | PN2222A (Q7) | D4 |
| IR | `SSR_IR` | PN2222A | D5 |
| Sauna phase 1 | `SSR_S1` | PN2222A | D6 |
| Sauna phase 2 | `SSR_S2` | PN2222A | D7 |
| Sauna phase 3 | `SSR_S3` | PN2222A | D8 |

- Field header **J1** — 5-pin JST XH, silk **SSR**.
- Base resistors **2k2** to SSR nets; status LEDs with **220 Ω** class resistors.

**Software map:** [`gpio-interface.md`](../../gpio-interface.md) — BCM 4 (safety), 14 (IR), 15/17/18 (phases U/V/W).

---

## 5. Inputs and field connectors

### Digital / pulse (direct GPIO)

| JST | Silk / value | Pins | Function |
|---|---|---:|---|
| **J11** | `deur_sauna` | 2 | Sauna door reed |
| **J12** | `deur_badk` | 2 | Bathroom door reed |
| **J5** | `waterflow` | 4 | Bathroom cold + hot pulse meters |
| **J2** | `kWh` | 2 | Main kWh pulse |

- Pull-ups **10k**, debounce **100 nF** (`.1u`) on inputs.
- Pulse activity LEDs **220–330 Ω** (e.g. cold/hot/kWh indicators).

**Software map:** BCM 27/22 (doors), 6/5 (water), 12 (kWh) — [`gpio-interface.md`](../../gpio-interface.md).

**R1 note:** Two **separate** door connectors (J11/J12) — supports fixing wanos BOM vs single-door contradiction.

### SHT11 plant headers (4× 4-pin JST XH)

Bit-banged **SHT11**, not SHT31 / PCA9615.

| JST | Silk | WanOS location (idx) | Typical D/C BCM |
|---|---|---|---:|
| **J10** | `sens-sauna-high` | Sauna high 20001 | 11 / 25 |
| **J9** | `sens-sauna-mid` | Sauna low 20002 | 7 / 8 |
| **J8** | `sens-cinema` | Cinema 20003 | 9 / 10 |
| **J7** | `sens-badk` | Bathroom 20004 | 24 / 23 |

Each header: **4-pin XH** (data, clock, 3V3, GND style plant cable).

---

## 6. vs wanos-pcb-v1

| Feature | This board (2.5.3 prod) | wanos-pcb-v1 target |
|---|---|---|
| Digital inputs | Direct GPIO | **PCA9554** expander A + more channels |
| Doors | 2× 2-pin (J11/J12) | Same count, expander-backed |
| Water meters | 1× bathroom (J5) | **2× bathrooms** + extra pulses |
| kWh | 1× (J2) | **2×** kWh |
| Sauna LCD buttons | None | Expander B + 4-pin JST |
| Temperature | SHT11 × 4 | **SHT31 × 5** + **TCA9548A** mux (no PCA9615 v1); LCD on root I²C |
| 12 V monitor | None | **Optocoupler** → Expander B P6 |
| LCD | None | **2× I²C LCD** JST |
| E-ink | **J3** Molex `1746679-1` | **HDMI Type-A → SPI** ([`hdmi-spi-eink.md`](../../hdmi-spi-eink.md)) |
| USB | **J6** USB-A on board | Not in wanos spec |
| Outline | ~74×105 mm | **85×56 mm** |

---

## 7. Reuse for wanos-pcb-v1 design

**High value**

- BCM / WanOS GPIO map ([`gpio-interface.md`](../../gpio-interface.md)) — verified against schematic net labels.
- SSR transistor + LED indicator blocks and **J1** 5-pin SSR header pattern.
- JST XH field connector choices and **Dutch/short silk labels** (`deuren`, `water`, `kWh`, `sauna 3-2-1`).
- Input conditioning: **10k** pull-up, **100 nF** debounce, **220 Ω** activity LEDs.

**Copy assets (on implement)**

- [`Wannes-library.kicad_sym`](211201%20wisc2-5-3/Wannes-library.kicad_sym) — logos, custom symbols.
- [`Wannes-library.pretty/`](211201%20wisc2-5-3/Wannes-library.pretty/) — logos, **HCPL3700** footprint (unused here but relevant for 12 V monitor), Molex e-ink footprint.

**Use other reference**

- **HDMI e-ink + 85×56 mm** → [`wisc-v2-6-4-hdmi.md`](wisc-v2-6-4-hdmi.md)

---

## 8. Artifacts in repo tree

| Path | Purpose |
|---|---|
| `wisc-v5.kicad_sch` / `.kicad_pcb` / `.kicad_pro` | KiCad sources (read-only) |
| `Wannes-library*` | Custom symbols / footprints |
| `BOM 211206.xlsx`, schema PDF, PCB photos, `water-mosfet-circuit.png` | Supporting reference |
| `gerbers/`, cache, `.history/` | Moved to [`../_donotcommit/`](../_donotcommit/) (not in git) |

---

## 9. Konnect / Cursor

Safe **read-only** operations against this path: `get_project_info`, `open_project`, file-mode `get_board_info`. Do not edit KiCad sources here — see [`.cursor/rules/wisc-boards-readonly.mdc`](../../../.cursor/rules/wisc-boards-readonly.mdc).

Setup: [`kicad-setup.md`](../../kicad-setup.md).

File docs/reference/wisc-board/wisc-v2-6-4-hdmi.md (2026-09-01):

<!-- --- file: docs/reference/wisc-board/wisc-v2-6-4-hdmi.md -->

# WISC v2.6.4 — HDMI e-ink interface board

Summary of the **85 × 56 mm WISC HDMI / e-ink interface** KiCad project. Sources are **read-only reference** in the repo.

| | |
|---|---|
| **Folder** | [`220313 wisc2-6-4-HDMI/`](220313%20wisc2-6-4-HDMI/) |
| **Project** | `wisc2-6-4.kicad_pro` |
| **Title block** | Wisc · rev **2.6.4** · 2022-03-13 · Hofmans |
| **Silk ID** | `220313_wisc2-6-4` |
| **Status** | **In production use** — Pi node with LCD screens (see [§ 1](#1-role-and-deployed-use-today)) |

**Related:** [`hdmi-spi-eink.md`](../../hdmi-spi-eink.md) (wanos-pcb-v1 target) · [`board-spec.md`](../../board-spec.md) · Index → [`README.md`](README.md)

**Verified open in KiCad (2026-09-01):** `open_project` → `ipc_available: true`, board `wisc2-6-4.kicad_pcb` loaded.

---

## 1. Role and deployed use today

### KiCad design role

This is a **compact Pi carrier / interface board** (~**85 × 56 mm**), **not** the full field-I/O WISC in [`wisc-v5-2-5-3-production.md`](wisc-v5-2-5-3-production.md).

It concentrates on:

- **Raspberry Pi 40-pin header** (`P1`)
- **E-ink display** interconnect using an **HDMI symbol** and **Molex `17466791` footprint** (HDMI pin names on pads — cable to WISC e-ink panel)
- **External power** (5 V / 12 V) and **temp-safety** interlock wiring
- **I²C** breakout (`J7`)
- **4-pin link to “board 2”** (`J4` `to-board2`) — power rails to a second board
- **USB-A** (`J6`)

There are **no** SSR drives, door/water/kWh field inputs, or SHT plant headers on this PCB.

### Deployed use (operator, 2026-09-01)

> This **2.6.4 HDMI** board **is used for WanOS today**, on the **Raspberry Pi where the LCD screens are connected**.
>
> The **HDMI cable is not connected** — in current operation this board **only powers the Pi**.
>
> **HDMI was connected in the past** and **e-ink worked**; it **does not work any more**. That failure is **one of the reasons** to replace the entire **HDMI / e-ink** approach on **wanos-pcb-v1**.

WanOS today therefore uses **two WISC hardware roles**:

| Board | Deployed role today |
|---|---|
| [**2.5.3 production**](wisc-v5-2-5-3-production.md) | Main field-I/O carrier (SSR, doors, meters, SHT11, …) |
| **This 2.6.4 HDMI board** | Pi + **LCD** node — **power only**; e-ink path **unused / broken** |

Use this KiCad tree for **85×56 mm mechanical**, historical **HDMI→SPI GPIO** wiring, and **power patterns** — not as proof that the legacy e-ink path still works in the field.

See also [`hdmi-spi-eink.md`](../../hdmi-spi-eink.md) § Legacy WISC / motivation to redesign.

---

## 2. Mechanical

| Item | Value |
|---|---|
| **Outline** | **85 × 56 mm** (Edge.Cuts: 78.548–163.548 mm × 60.820–116.820 mm) |
| **Thickness** | 1.6 mm |
| **Layers** | 2 (F.Cu / B.Cu), paste/mask on both sides |
| **Mounting** | Four mounting holes (`H1`–`H4`) |
| **Pi** | 2×20 vertical header (`P1`) |

Matches **wanos-pcb-v1** target size in [`board-spec.md`](../../board-spec.md).

---

## 3. Connectors

| Ref | Silk / value | JST / type | Function |
|---|---|---|---|
| **P1** | Raspi header | 2×20 pin | Pi 40-pin |
| **J5** | e-ink | `Wannes:17466791` (Molex-style, HDMI pin naming) | WISC e-ink panel (HDMI cable) |
| **J7** | I²C | 4-pin XH | GPIO2 (SDA) / GPIO3 (SCL) + power |
| **J4** | to-board2 | 4-pin XH | See [§ 4](#4-power-and-board2-link) |
| **J1** | 12V ext | 2-pin XH | External 12 V in (`+12VA`) |
| **J2** | temp-safety | 2-pin XH | Sauna temperature safety interlock |
| **J3** | 5V ext | 2-pin XH | External 5 V in |
| **J6** | USB_A | Molex horizontal | USB host port |

Schematic notes: **I²C** = GPIO2 data, GPIO3 clock. **Pi pwr connector** annotation: pins 1,3 = 3V3; 2,4 = 5V.

---

## 4. Power and board2 link

### Rails

| Rail | Notes |
|---|---|
| **+5VA** | Fused 5 V path (F1 **2 A**), `D2` `1N4001`, bulk/decoupling caps |
| **+12VA** | From **J1** `12V ext`; routed to **J4** and e-ink **+5V** pin (HDMI pin 18 → `+5VA` on PCB) |
| **+3V3** | Pi / logic |
| **D1** `BZX85C5V6` | Zener in 5 V input conditioning |

### J4 `to-board2` (4-pin XH)

| Pin | Net | Notes |
|---:|---|---|
| 1 | GND | |
| 2 | +5VA | |
| 3 | *(NC)* | Unconnected on this rev |
| 4 | +12VA | |

Likely **power feed** to a second WISC board (main I/O carrier), not a signal harness.

**J2 `temp-safety`:** 2-pin — external sauna over-temperature safety chain (cuts 12 V path off-board).

---

## 5. E-ink — HDMI footprint, SPI on Pi GPIO

Schematic uses symbol **`Connector:HDMI_A`** with footprint **`Wannes:17466791`** (same physical family as production J3 on 2.5.3, but pads are labeled with **HDMI net names**).

### BCM map (annotated on schematic — use for software)

| SPI function | BCM GPIO | HDMI pad function (on footprint) |
|---|---:|---|
| **CLK** | 11 | CK+ (pad 10) |
| **MOSI** | 10 | D2− (pad 3) |
| **CS** | 8 | D0+ (pad 7) |
| **BUSY** | 24 | D1+ (pad 4) |
| **RST** | 17 | CEC (pad 13) |
| **DC** | 25 | SDA (pad 16) |
| **Panel 5 V** | — | +5V (pad 18) → `+5VA` |

Most other HDMI pads/shields tie to **GND**. **HPD** (pad 19) → GND on this layout.

### vs [`hdmi-spi-eink.md`](../../hdmi-spi-eink.md)

The wanos-pcb-v1 doc maps **HDMI pin numbers → signal names** (TMDS-oriented). This WISC board implements a **concrete BCM assignment** on the Molex/HDMI footprint. Before **R2** lock:

- Reconcile wanos **Molex 208658-1052** target part vs **`17466791`** reference footprint.
- Confirm **CEC → RST** and **SDA → DC** match running WanOS e-ink driver expectations (wanos doc currently lists CEC/SDA as spare/future).
- Lock whether wanos-pcb-v1 follows **this BCM map** or the draft HDMI-pin table.

---

## 6. vs production WISC 2.5.3

| Topic | [2.5.3 production](wisc-v5-2-5-3-production.md) | This board (2.6.4 HDMI) |
|---|---|---|
| **Size** | ~74 × 105 mm | **85 × 56 mm** |
| **Production WanOS today** | Main I/O carrier | **Yes** — Pi with **LCDs**; **Pi power only** (HDMI **disconnected**; e-ink **no longer works**) |
| **SSR, doors, water, kWh, SHT11** | Full carrier | **None** |
| **E-ink** | Molex J3 (no HDMI symbol) | **HDMI symbol + same footprint family**, documented SPI GPIO |
| **12 V monitoring opto** | None | None (temp-safety **J2** only) |
| **I²C header** | None | **J7** |
| **Link to other board** | None | **J4** power to “board2” |

---

## 7. vs wanos-pcb-v1

| wanos-pcb-v1 target | This reference |
|---|---|
| 85 × 56 mm outline | **Match** — use for mechanical R2 |
| HDMI Type-A → SPI e-ink | **Closest WISC SPI wiring reference** — verify BCM + connector part |
| Full field I/O on one board | **Not here** — merge with 2.5.3 I/O patterns + expanders per spec |
| PCA9554 / SHT31 / LCDs | **Not on this PCB** |
| 12 V opto hard-lock | **Not on this PCB** (only temp-safety JST) |
| Single integrated carrier | wanos goal — this was a **split** (interface + board2) experiment |

---

## 8. Reuse for wanos-pcb-v1

**High value**

- **Board outline** and mounting hole placement (85×56).
- **E-ink SPI BCM map** (§ 5) and HDMI-pad → GND treatment on unused pairs.
- **J7** I²C header pattern (GPIO2/3) — relevant to on-board LCD headers in spec.
- **J1/J2/J3** external power + **temp-safety** silk (`to temp.safety`, `12V ext`, `5V ext in`).
- **J4** as evidence of **12 V / 5 V distribution** thinking (wanos integrates on one board).

**Low / do not copy blindly**

- **J4 to-board2** split-board architecture (wanos-pcb-v1 is one carrier).
- **J6 USB-A** (not in wanos spec).
- **`17466791`** footprint without confirming [`component-selection.md`](../../component-selection.md) **208658-1052** equivalence.

---

## 9. Artifacts in repo tree

| Path | Purpose |
|---|---|
| `wisc2-6-4.kicad_sch` / `.kicad_pcb` / `.kicad_pro` | KiCad sources (read-only) |
| `wisc2-6-4-schema.pdf` | Schematic PDF |
| `fp-lib-table` / `sym-lib-table` | Library pointers (`Wannes:` footprints — copy from 2.5.3 tree if needed) |
| `gerbers/`, backups, cache, `.history/` | Moved to [`../_donotcommit/`](../_donotcommit/) (not in git) |

---

## 10. Konnect / Cursor

Read-only inspection OK (`get_project_info`, `open_project`, file-mode reads). Do not edit KiCad sources under this folder. Setup: [`kicad-setup.md`](../../kicad-setup.md).

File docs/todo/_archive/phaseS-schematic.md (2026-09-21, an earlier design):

<!-- --- file: docs/todo/_archive/phaseS-schematic.md -->

# WanOS PCB Phase S — Schematic (+ KiCad project) — ARCHIVED

**Status:** **Done** **2026-09-21** (S1 **2026-09-01** + Gate-S1 operator close).

**Shipped:** [`projects/wanos-board/`](../../../projects/wanos-board/) hierarchical KiCad schematic for **wanos-pcb-v1**.

## Shipped summary

| Id | What | Closed |
|---|---|---|
| **S1** | Project + sheets + ERC **0 errors** | **2026-09-01** |
| **Gate-S1** | Operator schematic sign-off (Wannes) | **2026-09-21** |

**Sheets (as closed):** `Pi_Power`, `IO_Expanders`, `Pulse_Inputs`, `SSR_Drivers`, `HDMI_SPI`, `I2C_Plant` — checklist [`schematic-signoff.md`](../../schematic-signoff.md).

**Notable post-S1 schematic work retained in product docs:** TCA9548A + 5× SHT31; water on **J4** in `io_expanders`; greenfield door/kWh front-ends on `pulse_inputs` (retire legacy stubs on cutover); **C7** dropped; **R11** RESET pull-up.

## Product docs (canonical)

| Topic | Doc |
|---|---|
| Spec | [`board-spec.md`](../../board-spec.md) |
| Field / pulse | [`field-wiring.md`](../../field-wiring.md) |
| Expanders / I²C | [`io-expander-map.md`](../../io-expander-map.md) |
| Sign-off record | [`schematic-signoff.md`](../../schematic-signoff.md) |
| Parts | [`component-selection.md`](../../component-selection.md) |

**Next (main carrier):** **L1** layout — [`phaseL-layout.md`](../phaseL-layout.md).  
**Next (operator, near-term):** clean + check **wanos-remote** schematic — [`pipeline.md`](../pipeline.md) Sequence **Ops-Remote1**.

Pipeline: [`pipeline.md`](../pipeline.md).

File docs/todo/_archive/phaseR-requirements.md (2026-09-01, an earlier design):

<!-- --- file: docs/todo/phaseR-requirements.md -->

# WanOS PCB Phase R — Requirements / architecture

**wanos-pcb-v1** — spec locks, external plant, field wiring, migration reference.

**Status:** **R1 Done** (2026-09-01) · **R2 Done** (2026-09-01).

**Related:** [`board-spec.md`](../board-spec.md) · [`field-wiring.md`](../field-wiring.md) · [`gpio-interface.md`](../gpio-interface.md) · [`external-plant.md`](../external-plant.md) · [`grounding.md`](../grounding.md) · Sequence → [`pipeline.md`](../pipeline.md) (archived).

**DoD convention:** Last DoD = audit & update ALL `docs/**/*.md` (and root README) against shipped artifacts.

---

## Subphases

| Id | What | Status |
|---|---|---|
| **R1** | Resolve spec + BOM contradictions | **Done** (2026-09-01) |
| **R2** | Architecture + external plant + field wiring + mechanical | **Done** (2026-09-01) |

---

## R1 — Shipped summary (2026-09-01)

**Canonical detail:** [`board-spec.md`](../board-spec.md) · [`field-wiring.md`](../field-wiring.md) · [`io-expander-map.md`](../io-expander-map.md).

| Topic | Lock |
|---|---|
| 12 V opto | **Expander B P6** (`EXP_B_P6_12V_MON`) |
| kWh aux | **Expander A P7** |
| Doors | **2× 2-pin** J2, J3 |
| kWh | **2× 2-pin** J6, J7 |
| Buttons | **1× 4-pin** J8; Cat5 → [`field-wiring.md`](../field-wiring.md) § 5 |
| LCD | **1× 4-pin** J16; paralleled; **no 2nd header v1** |
| 4-pin I²C pinout | WISC **2.6.4 J7** |
| SHT31 | **TCA9546A** @ **0x70**; **J9–J12**; **`0x44`**; ~4–5 m Cat5 |
| PCA9615 | **Not used v1** |
| I²C pull-ups | **R9, R10 = 2k2** |
| SSR field | **J13** 5-pin (WISC J1 parity) |
| Silkscreen font | [Printed Circuit Board 7](https://www.fontspace.com/printed-circuit-board-7-font-f15777) |

---

## R2 — Shipped summary (2026-09-01)

**Canonical detail:** [`board-spec.md`](../board-spec.md) · [`gpio-interface.md`](../gpio-interface.md) · [`hdmi-spi-eink.md`](../hdmi-spi-eink.md) · [`external-plant.md`](../external-plant.md) · [`grounding.md`](../grounding.md) · [`design.yaml`](../../projects/wanos-board/design.yaml).

| Topic | Lock |
|---|---|
| Pi | **Pi 4** (re-use production unit) |
| Mechanical | **85×56 mm**, **M2.5** holes — WISC **2.6.4** reference |
| Pi power | **J41** USB-C on PCB |
| 12 V | **J14** only (**J15** dropped); post-safety **+12VA** |
| HDMI J1 | Molex **208658-1052** (LCSC **C6990958**); pinout [`hdmi-spi-eink.md`](../hdmi-spi-eink.md) |
| Pi BCM | [`gpio-interface.md`](../gpio-interface.md) — SSR, I²C, e-ink SPI |
| I²C addr | U1 **`0x20`**, U2 **`0x21`**, U5 **`0x70`** |
| PCA9554 INT | **NC** v1 |
| External SSR | **4×** Omron **G3PJ-225B DC12-24** — [`external-plant.md`](../external-plant.md) |
| Temp safety | Independent; cuts **12 V** off-board |
| Grounding | [`grounding.md`](../grounding.md) |
| Software | **No adapter** — operator updates **wanos** when switching from WISC; **one Pi** |
| Silk | **`wanos-pcb-v1.0`** + Wannes logos; **no** CC BY-NC-SA |
| JLC | Full **PCBA** incl. **J40** |
| Datasheets | [`reference/datasheets/`](../reference/datasheets/README.md) — 12/13; `usb-c-j41.pdf` later |
| Harness | Reuse where pinout matches; SHT11→SHT31 tails re-wire |

### R2 DoD

- [x] [`design.yaml`](../../projects/wanos-board/design.yaml) + [`constraints.md`](../../projects/wanos-board/constraints.md) match locks
- [x] [`gpio-interface.md`](../gpio-interface.md) — locked BCM tables
- [x] [`external-plant.md`](../external-plant.md), [`grounding.md`](../grounding.md) published
- [x] Last DoD: all `docs/**/*.md` + README audited

---

## Info — WISC migration reference

**Home:** [`docs/reference/wisc-board/`](../reference/wisc-board/) — read-only KiCad + summaries. Feeds **V1a** cutover ([`phaseV-verify.md`](phaseV-verify.md)).

---

## Operator requests (verbatim)

**2026-08-31** — new repo; KiCad + JLCPCB; docs/todo structure; wanos-pcb-v1 vs WISC; full triage.

**2026-09-01** — R2 kickoff Q&A; drop **J15**; datasheet pack; close R2.

---

## Out of scope (R track)

- WanOS application **implementation** (main repo — **V1a** / **V1b**)
- CE / formal compliance sign-off unless later triaged

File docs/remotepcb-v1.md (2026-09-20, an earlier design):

<!-- --- file: docs/remotepcb.md --- -->

# Remote plant PCB — water meters + pipe temperatures (draft)

**Status:** design draft — not kicked off / not locked for implement.  
**Source:** consolidated from `remote PCB.txt` and architecture review.  
**Replaces:** cold & hot water pulse path on main **J4** → **U1** (YF-B6/B10). Adds four **DS18B20** pipe temperatures.

Canonical shipped water wiring today → [`field-wiring.md`](field-wiring.md) § 2a, [`io-expander-map.md`](io-expander-map.md) § 2. Working design note in `docs/` until behaviour is locked into the usual product homes on ship.

---

## 1. Intent

| Item | Decision |
|---|---|
| Role | One remote board near the bathrooms: **4× YF-B6** pulses + **4× DS18B20** pipe temps |
| Link to main | Single **Cat5 UTP ~6 m** → main **RJ45** (reuse designator **J4**) |
| I²C path | Main **J4** → **U5** TCA9548A channel **5** (`SD5` / `SC5`) @ **100 kHz** |
| Power | Main **`+5VA`** over Cat5 → remote **AP2112-3.3** for logic; YF-B6 VDD from remote **`+5VA`** |
| Interrupt | MCP23017 **INT** over Cat5 pair 4 → main PCB; **destination pin TBD** |
| Main J4 today | Current water RJ45 + `water_meters` front-end **removed**; label **J4** reused for this uplink |
| Expanders | Four water GPIOs leave **U1**; dropping a **PCA9554PW** is a separate ToDo (not automatic — § 9) |

---

## 2. System block

```
  Pi root I²C (R9/R10 2k2)
       |
       +-- U1 PCA9554 0x20  (doors / kWh; water P2–P5 removed after cutover)
       +-- U2 PCA9554 0x21  (buttons / 12 V mon)
       +-- U5 TCA9548A 0x70
       |      ch 0–4 : SHT31 plant (unchanged)
       |      ch 5   : NEW remote uplink (SD5/SC5) ---- Cat5 ~6 m ---- remote RJ45
       |      ch 6–7 : NC (unless reserved later)
       +-- J16 LCD (root, not muxed)

  Remote PCB:
       +5VA (from cable) -- TVS -- polyfuse(main) -- AP2112-3.3 -- DS2482-800 + MCP23017
       YF-B6 ×4  --> MCP23017 GPIOs (+ RC / TVS / activity LED)
       DS18B20 ×4 --> DS2482-800 1-Wire channels
       INT (OD) --> Cat5 pair 4 --> main (2k2 pull-up) --> TBD GPIO
```

---

## 3. Main PCB changes

### 3.1 Connector **J4** (redefined)

Remove today’s water-meter RJ45 function (four SIG + `+5VA` to YF over one Cat5 into **U1**).

New **J4** = uplink to remote PCB only:

| Net / pin group | Connection |
|---|---|
| **SDA** | **U5** channel **5** data (**`SD5`**) |
| **SCL** | **U5** channel **5** clock (**`SC5`**) |
| **`+5VA`** | Through **polyfuse** (new — see § 3.3) to jack |
| **GND** | Board GND (multiple returns on Cat5 — § 5) |
| **INT** | MCP23017 interrupt from remote; **2k2** pull-up to **`+3V3`** on main; **landing pin TBD** |

Jack: same class as current water **J4** preferred — TE **5556416-1** / Amphenol **54602**-class RJ45 TH, no magnetics, no jack LEDs (align with [`field-wiring.md`](../field-wiring.md) § 2a hardware).

**Pinout:** lock T568B table to match remote (§ 5). Do **not** use the old water SIG pin map.

### 3.2 Remove on-main water front-end

Drop with old **J4** water role:

- `water_meters.kicad_sch` channel parts (**R37–R44**, **C18–C21**, **D25–D29**, activity **D13–D16** / **R19–R22**, etc.)
- **U1** nets **P2–P5** water (`WM_B1_*` / `WM_B2_*`)

Doors (**J2/J3**) and kWh (**J6/J7**) stay on main unless a later remap consolidates expanders (§ 8).
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

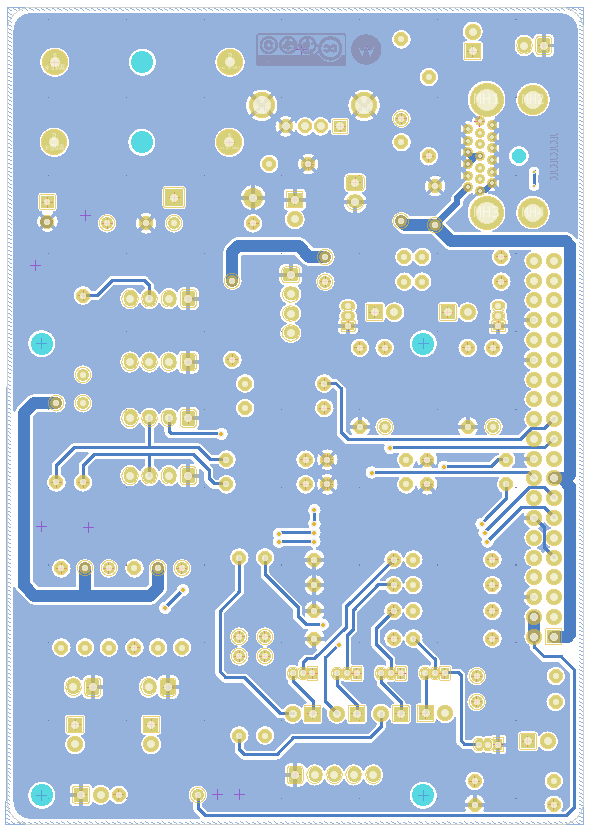
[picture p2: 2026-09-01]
docs/reference/wisc-board/211201 wisc2-5-3/wisc-v5(2-5-3)-211119-PCB-back.png

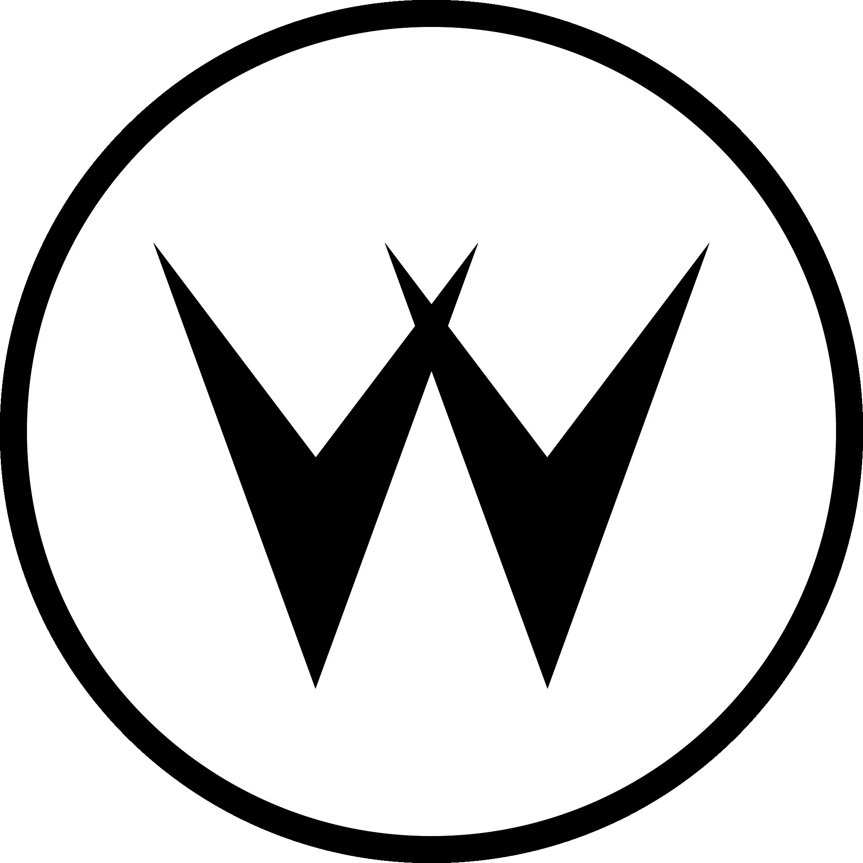
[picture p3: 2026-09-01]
docs/reference/silkscreen/W annes illiams.jpg

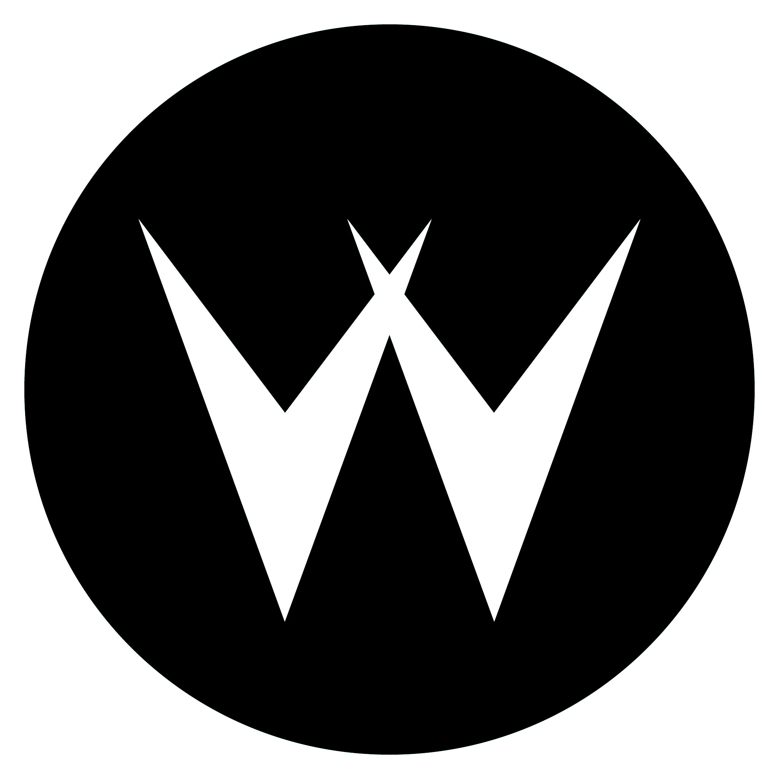
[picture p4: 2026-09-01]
docs/reference/silkscreen/W annes illiams inverted.jpg

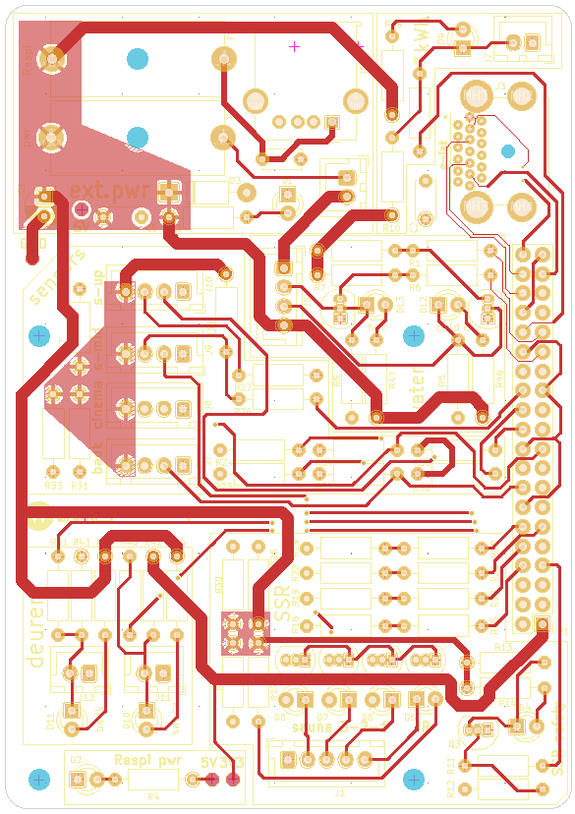
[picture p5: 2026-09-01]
docs/reference/wisc-board/211201 wisc2-5-3/wisc-v5(2-5-3)-211119-PCB-front.png

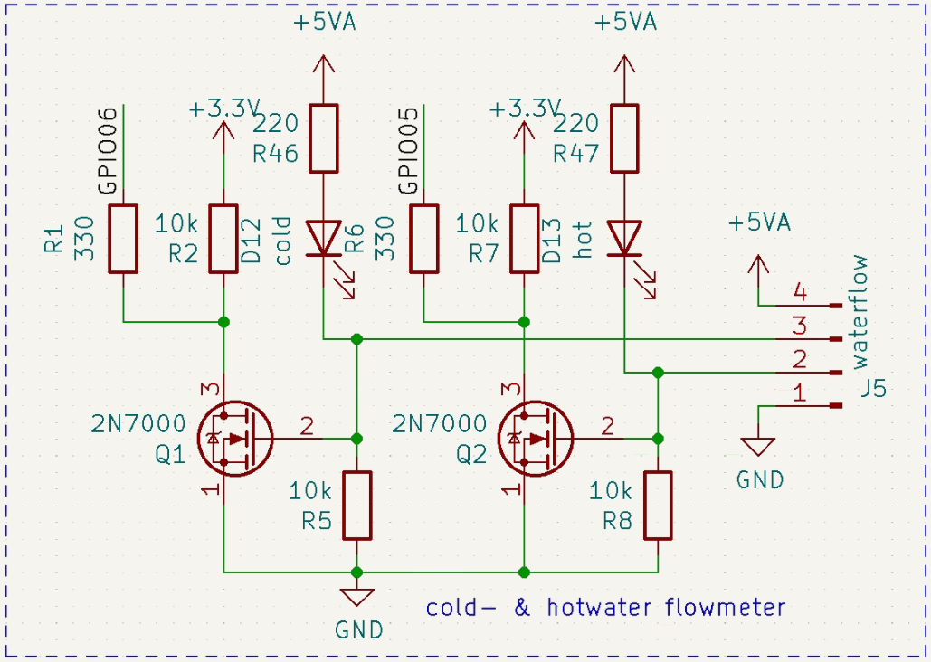
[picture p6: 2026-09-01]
docs/reference/wisc-board/211201 wisc2-5-3/water-mosfet-circuit.png

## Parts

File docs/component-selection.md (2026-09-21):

<!-- --- file: docs/component-selection.md -->

# wanos-pcb-v1 — component selection (JLCPCB-compatible)

Verified JLCPCB-compatible parts for **wanos-pcb-v1**, aligned with [`board-spec.md`](board-spec.md) (R1 locks **2026-09-01**).

**BOM seed:** [`projects/wanos-board/components.xlsx`](../projects/wanos-board/components.xlsx) (LCSC column — validate stock at **J1**).

**Field connectors:** designators and pinouts → [`field-wiring.md`](field-wiring.md).

---

## 1. JST XH connectors (2.50 mm pitch)

| MPN pattern | Pins | wanos use |
|---|---:|---|
| **B2B-XH-A** | 2 | Doors **J2–J3**, kWh **J6–J7** |
| **B4B-XH-A** | 4 | Buttons **J8**, SHT31 **J9–J12**/**J18**, LCD **J16** |
| **B5B-XH-A** | 5 | SSR **J13** (vertical) |
| ~~B6B-XH-A~~ | 6 | **Not used v1** (water was 2×6 JST; now **J4** RJ45) |

**Water field connector:**

| Part | Ref | Notes |
|---|---|---|
| **Amphenol / TE modjack class** | **J4** | TE **5556416-1** (LCSC **C86492**) — TH, **no LED**, no magnetics; footprint `Connector_RJ:RJ45_Amphenol_54602-x08_Horizontal` — fp refs [`amphenol-54602.pdf`](reference/datasheets/amphenol-54602.pdf) / [`amphenol-54602-drawing.pdf`](reference/datasheets/amphenol-54602-drawing.pdf) |

**KiCad footprints (JST vertical):**

```text
Connector_JST:JST_XH_B2B-XH-A_1x02_P2.50mm_Vertical
Connector_JST:JST_XH_B4B-XH-A_1x04_P2.50mm_Vertical
Connector_JST:JST_XH_B5B-XH-A_1x05_P2.50mm_Vertical
```

---

## 2. Screw terminals (12 V)

- **KF301-2P** — **J14** (12 V in) and **J17** (5 V in); both on **`pi_power.kicad_sch`**

Footprint: `TerminalBlock_Phoenix_MKDS-2-5.08_1x02`.

---

## 3. HDMI (e-ink SPI)

- **Molex 208658-1052** — **J1** (LCSC **C6990958**) — `Connector_HDMI:HDMI_Molex_208658-1052`

Pin mapping → [`hdmi-spi-eink.md`](hdmi-spi-eink.md).

---

## 4. I²C ICs

| Part | Ref | Role |
|---|---|---|
| **PCA9554PW** × 2 | U1, U2 | 8-bit expanders |
| **TCA9548A** | U5 | 8-ch I²C mux @ **0x70** (SHT31 @ **0x44** on ch 0–4) |
| ~~PCA9615DP~~ | — | **Not used v1** |

Footprints: `Package_SO:TSSOP-16_4.4x5mm_P0.65mm` (9554); `Package_SO:TSSOP-24_4.4x7.8mm_P0.65mm` (9548).

Net map → [`io-expander-map.md`](io-expander-map.md).

---

## 5. Other active parts

| Part | Ref | Role |
|---|---|---|
| **PN2222A-TA** × 5 | Q1–Q5 | SSR field drivers + safety gate **Q5** (SOT-23) |
| **PC817A** SMD | U4 | 12 V opto |
| **SMBJ12A** | D3 | 12 V TVS (SMD SMB) — [`smbj12a.pdf`](reference/datasheets/smbj12a.pdf) |
| **PESD5V0S1BA** × 4 | D25–D28 | Water SIG TVS SOD-323 (**`water_meters.kicad_sch`**, ~10 m Cat5) — [`pesd5v0s1ba.pdf`](reference/datasheets/pesd5v0s1ba.pdf) |
| **SMBJ5.0A** | D29 | Water **`+5VA`** TVS at **J4** (SMD SMB) — [`smbj5.0a.pdf`](reference/datasheets/smbj5.0a.pdf) |
| **BZT52C5V6** | D1 | 5 V overvoltage clamp (SMD SOD-123, shunt to GND) — family ref [`bzx85c.pdf`](reference/datasheets/bzx85c.pdf) |
| **AO3401A** | Q6 | 5 V ideal diode / reverse block (P-FET SOT-23, gate tied to drain) |
| **RVT1A101M0605** | C1 | +5VA bulk 100 µF 10 V (SMD 6.3×5.4 mm) |
| **BLM21PG331SN1** | FB1 | Pi 5 V ferrite |
| **SMD1206P200TF** | F1 | 5 V input polyfuse 2 A hold (resettable, 1206, LCSC C545216) |
| **500 mA polyfuse** | F2 | HDMI panel 5 V (1206, LCSC C369233) |

---

## 6. Passives (R1 locks)

| Ref | Value | Role |
|---|---|---|
| **R9**, **R10** | **2k2** | I²C SCL/SDA pull-ups on **`io_expanders.kicad_sch`** (4–5 m Cat5 @ 100 kHz) |
| **C3**, **C4** | 100 nF | PCA9554 VCC decoupling (**U1**, **U2** on **`io_expanders.kicad_sch`**) |
| **C6** | 100 nF | TCA9548A VCC decoupling (**U5** on **`i2c_plant.kicad_sch`**) |
| **R11** | 10 kΩ | TCA9548A **`~RESET`** pull-up to **`+3V3`** (**`i2c_plant.kicad_sch`**) |
| **R34**–**R36** | 10 kΩ | Exp B button **P0–P2** pull-ups (**`io_expanders.kicad_sch`**) |
| **R37**–**R40** | 10 kΩ | Water YF OD pull-ups → **`+3V3`** (**`water_meters.kicad_sch`**) |
| **R41**–**R44** | **330 Ω** | Water series field → expander (**`water_meters.kicad_sch`**) |
| **C18**–**C21** | 100 nF | Water debounce (**`water_meters.kicad_sch`**) |
| **D25**–**D28** | PESD5V0S1BA | Water SIG TVS (**`water_meters.kicad_sch`**) |
| **D29** | SMBJ5.0A | Water **`+5VA`** TVS at **J4** |
| R1–R4 | 470 Ω | SSR field base (**Q1–Q4**) |
| R5–R8 | 10 kΩ | SSR field base pulldown (base → emitter / **`SAFETY_BUS`**) |
| **R14** | 470 Ω | **Q5** base (**GPIO_SSR_SAFETY**) |
| **R15** | 10 kΩ | **Q5** base pulldown → **GND** |
| **R16** | 10 kΩ | **`SAFETY_BUS`** pull-up → **`+5VA`** |
| C8–C12 | 100 nF | SSR driver decoupling (C–E per **Q1–Q5**) |
| R17–R18, R23–R24 | **1k0** | Door / kWh activity LEDs (**`io_expanders.kicad_sch`**) |
| R19–R22 | **1k0** | Water activity LEDs (**`water_meters.kicad_sch`**) |
| R25–R28 | **1k0** | SSR activity LEDs (**`ssr_drivers.kicad_sch`**, **`+5VA`** → **`SSR_*`**) |
| R29 | **2k0** | Status LED (**+5VA**) |
| R30 | **6k8** | Status LED (**+12V**) |
| R32 | **1k5** | Opto LED |
| R33 + C17 | 10k + 100 nF | Opto RC (optional) |

**Not populated v1:** **R11–R13** (PCA9615 segment removed).

---

## 7. BOM summary

| Function | Part | Connector / ref |
|---|---|---|
| HDMI / e-ink | Molex 208658-1052 | J1 |
| Doors | JST XH 2-pin × 2 | J2, J3 |
| Water | RJ45 8P8C | **J4** — YF-B6/B10 ×4, Cat5 ~10 m, **`+5VA`** |
| kWh | JST XH 2-pin × 2 | J6, J7 |
| Buttons | JST XH 4-pin | J8 |
| SHT31 plant | JST XH 4-pin × 5 | J9–J12, J18 |
| SSR | JST XH **5-pin** vertical | J13 |
| 12 V | KF301 2P | J14 |
| LCD | JST XH 4-pin × 1 | J16 (root I²C, not muxed) |
| Expanders | PCA9554PW × 2 | U1, U2 |
| I²C mux | TCA9548A | U5 |
| SSR drivers | PN2222A × 5 | Q1–Q5 |
| 12 V monitor | PC817A | U4 |
| Pi header | 2×20 | J40 |
| 5 V in | KF301 2P | **J17** |
| ~~Pi USB-C~~ | — | **J41 DNP v1** |

**External (not assembled):** LCD modules, SHT31 sensor boards, external DIN SSRs.

---

## 7b. wanos-remote (plant module)

Canonical design → [`remotepcb.md`](remotepcb.md). KiCad → [`projects/wanos-remote/`](../projects/wanos-remote/). BOM rows in [`components.xlsx`](../projects/wanos-board/components.xlsx) with **`board=remote`**.

| Part | Role |
|---|---|
| TE **5556416-1** / LCSC **C86492** | Uplink RJ45 (same class as main water jack) |
| **B3B-XH-A** | 3-pin pulse + temp JST |
| **TLP281-4** | Quad opto |
| **MCP23017A** | I/O expander `@ 0x22` |
| **DS2482-800** | 1-Wire master `@ 0x18` (LCSC TBD) |
| **AP2204K-3.3** | VIN → 3V3 |
| **SMBJ12A** | VIN TVS on remote |

**Datasheets:** [`reference/datasheets/README.md`](reference/datasheets/README.md) — water TVS + Amphenol **54602** fp refs on disk; `usb-c-j41.pdf` deferred (J41 DNP v1).

Validate LCSC stock before **J1**.

---

## 8. Silkscreen

Font: [Printed Circuit Board 7](https://www.fontspace.com/printed-circuit-board-7-font-f15777) — see [`reference/silkscreen/README.md`](reference/silkscreen/README.md).

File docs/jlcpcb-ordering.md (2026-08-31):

<!-- --- file: docs/jlcpcb-ordering.md -->

# JLCPCB ordering checklist

How to produce and upload fabrication files for the WanOS board. Exact filenames follow the KiCad project name once **S1/L1** create `wanos-board.kicad_pro`.

**BOM seed:** [`projects/wanos-board/components.xlsx`](../projects/wanos-board/components.xlsx) · **Template:** [`fabrication/JLCPCB_BOM_Template.xls`](../projects/wanos-board/fabrication/JLCPCB_BOM_Template.xls)

---

## Before export

- [ ] Schematic **ERC** clean (or documented waivers in phase file)
- [ ] PCB **DRC** clean (or documented waivers)
- [ ] Board thickness, copper weight, and surface finish locked in phase **J1**
- [ ] All LCSC C-numbers assigned for SMT parts (if using JLC assembly)

---

## Generate from KiCad

Use **Fabrication Outputs** (KiCad 8+) or `kicad-cli`:

```powershell
# Example — adjust paths after project exists
$cli = "C:/Program Files/KiCad/10.0/bin/kicad-cli.exe"
$proj = "projects/wanos-board/wanos-board"

& $cli pcb export gerbers --output "projects/wanos-board/fabrication/" "$proj.kicad_pcb"
& $cli pcb export drill --format gerber --output "projects/wanos-board/fabrication/" "$proj.kicad_pcb"
& $cli pcb export pos --format csv --units mm --side front --output "projects/wanos-board/fabrication/" "$proj.kicad_pcb"
& $cli sch export bom --output "projects/wanos-board/fabrication/bom.csv" "$proj.kicad_sch"
```

Copy outputs into `projects/wanos-board/fabrication/` (see [`fabrication/README.md`](../projects/wanos-board/fabrication/README.md)).

---

## Upload bundle

| JLCPCB step | Files |
|---|---|
| **Gerber** | Zip all `.gbr` / `.gbrjob` + drill (`.drl` or embedded) |
| **PCB order** | Layer count, dimensions, qty, color, surface finish |
| **SMT assembly** (optional) | `bom.csv` + centroid `.csv` / `.pos`; confirm LCSC parts |
| **Stencil** (if hand-soldering SMT) | Paste gerber or order stencil separately |

Recommended zip layout:

```text
wanos-board-gerbers.zip
  wanos-board-F_Cu.gbr
  wanos-board-B_Cu.gbr
  ...
  wanos-board.drl
```

---

## Default fab notes (confirm at J1)

| Parameter | Starter default | Lock at |
|---|---|---|
| Layers | 2 | J1 |
| PCB thickness | 1.6 mm | J1 |
| Copper | 1 oz | J1 |
| Surface finish | HASL (lead-free) or ENIG | J1 |
| Min track / space | Match `constraints.md` | L1 |

---

## After order

- Record JLCPCB order id + date in phase **J1** when shipped
- On receipt, run phase **V1** bring-up before closing **J1**

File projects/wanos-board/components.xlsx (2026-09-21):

Designator | type | Quantity | Value | Footprint | MPN | LCSC | Category | Comment | Voltage | Package | MountType | board
C1 | capacitor | 1 | 100u | Capacitor_SMD:CP_Elec_6.3x5.4mm | RVT1A101M0605 | C72472 | Capacitor | +5VA bulk electrolytic; place at D1/D2/F1 conditioning output | 10V | 6.3x5.4 | SMT | main
C10 | capacitor | 1 | 100n | Capacitor_SMD:C_0805_2012Metric | CL10B104KB8NNNC | C14663 | Capacitor | SSR driver snubber/decouple; place at Q3 (SSR phase U) | 12V | 0805 | SMT | main
C11 | capacitor | 1 | 100n | Capacitor_SMD:C_0805_2012Metric | CL10B104KB8NNNC | C14663 | Capacitor | SSR driver snubber/decouple; place at Q4 (SSR IR) | 12V | 0805 | SMT | main
C12 | capacitor | 1 | 100n | Capacitor_SMD:C_0805_2012Metric | CL10B104KB8NNNC | C14663 | Capacitor | SSR driver snubber/decouple; place at Q5 (SSR safety) | 12V | 0805 | SMT | main
C17 | capacitor | 1 | 100n | Capacitor_SMD:C_0805_2012Metric | CL10B104KB8NNNC | C14663 | Capacitor | Opto RC filter; place at U4 with R33 | 12V | 0805 | SMT | main
C2 | capacitor | 1 | 100n | Capacitor_SMD:C_0805_2012Metric | CL10B104KB8NNNC | C14663 | Capacitor | +5VA HF bypass; place with C1 at +5VA node | 5V | 0805 | SMT | main
C3 | capacitor | 1 | 100n | Capacitor_SMD:C_0805_2012Metric | CL10B104KB8NNNC | C14663 | Capacitor | U1 (PCA9554) VCC decouple; place at U1 pin 16 | 3.3V | 0805 | SMT | main
C4 | capacitor | 1 | 100n | Capacitor_SMD:C_0805_2012Metric | CL10B104KB8NNNC | C14663 | Capacitor | U2 (PCA9554) VCC decouple; place at U2 pin 16 | 3.3V | 0805 | SMT | main
C5 | capacitor | 1 | 100n | Capacitor_SMD:C_0805_2012Metric | CL10B104KB8NNNC | C14663 | Capacitor | U2 VCC (verify vs C4 at layout); schematic at U2 row | 3.3V | 0805 | SMT | main
C6 | capacitor | 1 | 100n | Capacitor_SMD:C_0805_2012Metric | CL10B104KB8NNNC | C14663 | Capacitor | U5 (TCA9546A) VCC decouple; place at U5 pin 16 | 3.3V | 0805 | SMT | main
C7 | capacitor | 1 | 1u | Capacitor_SMD:C_0805_2012Metric | CL10A105KB8NNNC | C15849 | Capacitor | U5 bulk; place at U5 with C6 | 3.3V | 0805 | SMT | main
C8 | capacitor | 1 | 100n | Capacitor_SMD:C_0805_2012Metric | CL10B104KB8NNNC | C14663 | Capacitor | SSR driver snubber/decouple; place at Q1 (SSR phase W) | 12V | 0805 | SMT | main
C9 | capacitor | 1 | 100n | Capacitor_SMD:C_0805_2012Metric | CL10B104KB8NNNC | C14663 | Capacitor | SSR driver snubber/decouple; place at Q2 (SSR phase V) | 12V | 0805 | SMT | main
D1 | diode | 1 | BZT52C5V6 | Diode_SMD:D_SOD-123 | BZT52C5V6 | C173406 | Protection | 5 V zener conditioning (SMD; 500mW) | 5.6V | SOD-123 | SMT | main
D11 | diode | 1 | LED | LED_SMD:LED_0603 | 19-217/R6C-AL1M2QY/3T | C2297 | LED | Activity door sauna J2; with R17; place at U1/field-input zone | 3.3V | 0603 | SMT | main
D12 | diode | 1 | LED | LED_SMD:LED_0603 | 19-217/R6C-AL1M2QY/3T | C2297 | LED | Activity door bathroom J3; with R18 | 3.3V | 0603 | SMT | main
D13 | diode | 1 | LED | LED_SMD:LED_0603 | 19-217/R6C-AL1M2QY/3T | C2297 | LED | Activity water B1 cold J4; with R19 | 3.3V | 0603 | SMT | main
D14 | diode | 1 | LED | LED_SMD:LED_0603 | 19-217/R6C-AL1M2QY/3T | C2297 | LED | Activity water B1 hot J4; with R20 | 3.3V | 0603 | SMT | main
D15 | diode | 1 | LED | LED_SMD:LED_0603 | 19-217/R6C-AL1M2QY/3T | C2297 | LED | Activity water B2 cold J5; with R21 | 3.3V | 0603 | SMT | main
D16 | diode | 1 | LED | LED_SMD:LED_0603 | 19-217/R6C-AL1M2QY/3T | C2297 | LED | Activity water B2 hot J5; with R22 | 3.3V | 0603 | SMT | main
D17 | diode | 1 | LED | LED_SMD:LED_0603 | 19-217/R6C-AL1M2QY/3T | C2297 | LED | Activity kWh main J6; with R23 | 3.3V | 0603 | SMT | main
D18 | diode | 1 | LED | LED_SMD:LED_0603 | 19-217/R6C-AL1M2QY/3T | C2297 | LED | Activity kWh aux J7; with R24 | 3.3V | 0603 | SMT | main
D19 | diode | 1 | LED | LED_SMD:LED_0603 | 19-217/R6C-AL1M2QY/3T | C2297 | LED | Activity SSR phase W / Q1; with R25; bottom SSR zone | 3.3V | 0603 | SMT | main
D3 | diode | 1 | SMBJ12A | Diode_SMD:D_SMB | SMBJ12A | C353398 | Protection | 12 V TVS (+12VA / GND at 12 V entry) | 12V | SMB | SMT | main
D20 | diode | 1 | LED | LED_SMD:LED_0603 | 19-217/R6C-AL1M2QY/3T | C2297 | LED | Activity SSR phase V / Q2; with R26 | 3.3V | 0603 | SMT | main
D21 | diode | 1 | LED | LED_SMD:LED_0603 | 19-217/R6C-AL1M2QY/3T | C2297 | LED | Activity SSR phase U / Q3; with R27 | 3.3V | 0603 | SMT | main
D22 | diode | 1 | LED | LED_SMD:LED_0603 | 19-217/R6C-AL1M2QY/3T | C2297 | LED | Activity SSR IR / Q4; with R28 | 3.3V | 0603 | SMT | main
D23 | diode | 1 | LED | LED_SMD:LED_0603 | 19-217/R6C-AL1M2QY/3T | C2297 | LED | Status 5V in (+5VA post-F1); with R29 2k0; Pi power zone | 5V | 0603 | SMT | main
D24 | diode | 1 | LED | LED_SMD:LED_0603 | 19-217/R6C-AL1M2QY/3T | C2297 | LED | Status 12V (+12VA J14); with R30 6k8; bottom power zone | 12V | 0603 | SMT | main
D25 | diode | 1 | LED | LED_SMD:LED_0603 | 19-217/R6C-AL1M2QY/3T | C2297 | LED | Status 5V Pi (+5VA J40); with R31 2k0; near J40 | 5V | 0603 | SMT | main
F1 | polyfuse | 1 | 2A | Fuse:Fuse_1206_3216Metric | SMD1206P200TF | C545216 | Protection | 5V input polyfuse 2A hold | 5V | 1206 | SMT | main
F2 | fuse | 1 | 500mA | Fuse:Fuse_1206-3216Metric | 500mA | C369233 | Protection | HDMI pin18 polyfuse | 5V | 1206 | SMT | main
FB1 | ferrite | 1 | BLM21PG331SN1 | Inductor_SMD:L_0805 | BLM21PG331SN1 | C85832 | Ferrite | Pi 5V filter | 5V | 0805 | SMT | main
J1 | connector | 1 | HDMI Molex 208658-1052 | Connector_HDMI:HDMI_Molex_208658-1052 | 208658-1052 | C6990958 | Connector | E-ink SPI HDMI | 5V | SMT | SMT | main
J10 | connector | 1 | JST XH 4-pin | Connector_JST:JST_XH_B4B-XH-A_1x04_P2.50mm_Vertical | B4B-XH-A | C158016 | Connector | SHT31 cinema mux ch1 | 3.3V | TH | TH | main
J11 | connector | 1 | JST XH 4-pin | Connector_JST:JST_XH_B4B-XH-A_1x04_P2.50mm_Vertical | B4B-XH-A | C158016 | Connector | SHT31 sauna mid mux ch2 | 3.3V | TH | TH | main
J12 | connector | 1 | JST XH 4-pin | Connector_JST:JST_XH_B4B-XH-A_1x04_P2.50mm_Vertical | B4B-XH-A | C158016 | Connector | SHT31 sauna high mux ch3 | 3.3V | TH | TH | main
J13 | connector | 1 | JST XH 5-pin | Connector_JST:JST_XH_B5B-XH-A_1x05_P2.50mm_Vertical | B5B-XH-A | C158018 | Connector | SSR field WISC parity | 12V | TH | TH | main
J14 | connector | 1 | KF301-2P | TerminalBlock_Phoenix_MKDS-2-5.08_1x02_P5.08mm | KF301-2P | C39545 | Connector | 12V input | 12V | TH | TH | main
J16 | connector | 1 | JST XH 4-pin | Connector_JST:JST_XH_B4B-XH-A_1x04_P2.50mm_Vertical | B4B-XH-A | C158016 | Connector | LCD I2C both paralleled | 3.3V | TH | TH | main
J17 | connector | 1 | KF301-2P | TerminalBlock_Phoenix:TerminalBlock_MKDS-2-5.08_1x02_P5.08mm | KF301-2P | C474892 | Connector | 5V screw input | 5V | TH | TH | main
J2 | connector | 1 | JST XH 2-pin | Connector_JST:JST_XH_B2B-XH-A_1x02_P2.50mm_Vertical | B2B-XH-A | C158012 | Connector | Door sauna | 3.3V | TH | TH | main
J3 | connector | 1 | JST XH 2-pin | Connector_JST:JST_XH_B2B-XH-A_1x02_P2.50mm_Vertical | B2B-XH-A | C158012 | Connector | Door bathroom | 3.3V | TH | TH | main
J4 | connector | 1 | JST XH 6-pin | Connector_JST:JST_XH_B6B-XH-A_1x06_P2.50mm_Vertical | B6B-XH-A | C158014 | Connector | Water meters B1 | 3.3V | TH | TH | main
J40 | connector | 1 | 40-pin header | Connector_PinHeader_2.54mm:PinHeader_2x20_P2.54mm_Vertical | PHA2-20 |  | Connector | Raspberry Pi | 5V | TH | TH | main
J41 | connector | 1 | DNP | DNP | HRO-TYPE-C-31-M-12 | C165948 | DNP v1 - Pi fed via J40 header 5V | Optional Pi power | 5V | SMT | SMT | main
J5 | connector | 1 | JST XH 6-pin | Connector_JST:JST_XH_B6B-XH-A_1x06_P2.50mm_Vertical | B6B-XH-A | C158014 | Connector | Water meters B2 | 3.3V | TH | TH | main
J6 | connector | 1 | JST XH 2-pin | Connector_JST:JST_XH_B2B-XH-A_1x02_P2.50mm_Vertical | B2B-XH-A | C158012 | Connector | kWh main | 3.3V | TH | TH | main
J7 | connector | 1 | JST XH 2-pin | Connector_JST:JST_XH_B2B-XH-A_1x02_P2.50mm_Vertical | B2B-XH-A | C158012 | Connector | kWh aux | 3.3V | TH | TH | main
J8 | connector | 1 | JST XH 4-pin | Connector_JST:JST_XH_B4B-XH-A_1x04_P2.50mm_Vertical | B4B-XH-A | C158016 | Connector | Sauna LCD buttons Cat5 | 3.3V | TH | TH | main
J9 | connector | 1 | JST XH 4-pin | Connector_JST:JST_XH_B4B-XH-A_1x04_P2.50mm_Vertical | B4B-XH-A | C158016 | Connector | SHT31 bathroom mux ch0 | 3.3V | TH | TH | main
MH1-MH4 | mountinghole | 4 | MountingHole | MountingHole:MountingHole_3.2mm | MH3.2 |  | Mechanical | Mounting |  | NPTH | TH | main
Q1 | transistor | 1 | PN2222A | Package_TO_SOT_SMD:SOT-23 | PN2222A-TA | C2150 | Transistor | SSR driver | 12V | SOT-23 | SMT | main
Q2 | transistor | 1 | PN2222A | Package_TO_SOT_SMD:SOT-23 | PN2222A-TA | C2150 | Transistor | SSR driver | 12V | SOT-23 | SMT | main
Q3 | transistor | 1 | PN2222A | Package_TO_SOT_SMD:SOT-23 | PN2222A-TA | C2150 | Transistor | SSR driver | 12V | SOT-23 | SMT | main
Q4 | transistor | 1 | PN2222A | Package_TO_SOT_SMD:SOT-23 | PN2222A-TA | C2150 | Transistor | SSR driver | 12V | SOT-23 | SMT | main
Q5 | transistor | 1 | PN2222A-TA | Package_TO_SOT_SMD:SOT-23 | PN2222A-TA | C181091 | Transistor | SSR master safety BCM4 | 12V | SOT-23 | SMT | main
R1 | resistor | 1 | 470R | Resistor_SMD:R_0603 | 0603WAF4700T5E |  | Resistor | Q1 SSR base; place at Q1 | 3.3V | 0603 | SMT | main
R10 | resistor | 1 | 2k2 | Resistor_SMD:R_0603 | 0603WAF2201T5E |  | Resistor | I2C SDA pull-up | 3.3V | 0603 | SMT | main
R14 | resistor | 1 | 470R | Resistor_SMD:R_0603 | 0603WAF4700T5E |  | Resistor | Q5 SSR safety base; place at Q5 | 3.3V | 0603 | SMT | main
R15 | resistor | 1 | 10k | Resistor_SMD:R_0603 | 0603WAF1002T5E |  | Resistor | Q5 SSR safety pulldown; place at Q5 | 3.3V | 0603 | SMT | main
R17 | resistor | 1 | 1k0 | Resistor_SMD:R_0603 | 0603WAF1001T5E |  | Resistor | D11 activity LED; place at D11 | 3.3V | 0603 | SMT | main
R18 | resistor | 1 | 1k0 | Resistor_SMD:R_0603 | 0603WAF1001T5E |  | Resistor | D12 activity LED; place at D12 | 3.3V | 0603 | SMT | main
R19 | resistor | 1 | 1k0 | Resistor_SMD:R_0603 | 0603WAF1001T5E |  | Resistor | D13 activity LED; place at D13 | 3.3V | 0603 | SMT | main
R2 | resistor | 1 | 470R | Resistor_SMD:R_0603 | 0603WAF4700T5E |  | Resistor | Q2 SSR base; place at Q2 | 3.3V | 0603 | SMT | main
R20 | resistor | 1 | 1k0 | Resistor_SMD:R_0603 | 0603WAF1001T5E |  | Resistor | D14 activity LED; place at D14 | 3.3V | 0603 | SMT | main
R21 | resistor | 1 | 1k0 | Resistor_SMD:R_0603 | 0603WAF1001T5E |  | Resistor | D15 activity LED; place at D15 | 3.3V | 0603 | SMT | main
R22 | resistor | 1 | 1k0 | Resistor_SMD:R_0603 | 0603WAF1001T5E |  | Resistor | D16 activity LED; place at D16 | 3.3V | 0603 | SMT | main
R23 | resistor | 1 | 1k0 | Resistor_SMD:R_0603 | 0603WAF1001T5E |  | Resistor | D17 activity LED; place at D17 | 3.3V | 0603 | SMT | main
R24 | resistor | 1 | 1k0 | Resistor_SMD:R_0603 | 0603WAF1001T5E |  | Resistor | D18 activity LED; place at D18 | 3.3V | 0603 | SMT | main
R25 | resistor | 1 | 1k0 | Resistor_SMD:R_0603 | 0603WAF1001T5E |  | Resistor | D19 activity LED; place at D19 | 3.3V | 0603 | SMT | main
R26 | resistor | 1 | 1k0 | Resistor_SMD:R_0603 | 0603WAF1001T5E |  | Resistor | D20 activity LED; place at D20 | 3.3V | 0603 | SMT | main
R27 | resistor | 1 | 1k0 | Resistor_SMD:R_0603 | 0603WAF1001T5E |  | Resistor | D21 activity LED; place at D21 | 3.3V | 0603 | SMT | main
R28 | resistor | 1 | 1k0 | Resistor_SMD:R_0603 | 0603WAF1001T5E |  | Resistor | D22 activity LED; place at D22 | 3.3V | 0603 | SMT | main
R29 | resistor | 1 | 2k0 | Resistor_SMD:R_0603 | 0603WAF2001T5E |  | Resistor | D23 status 5V in; place at D23 | 5V | 0603 | SMT | main
R3 | resistor | 1 | 470R | Resistor_SMD:R_0603 | 0603WAF4700T5E |  | Resistor | Q3 SSR base; place at Q3 | 3.3V | 0603 | SMT | main
R30 | resistor | 1 | 6k8 | Resistor_SMD:R_0603 | 0603WAF6801T5E |  | Resistor | D24 status 12V; place at D24 | 12V | 0603 | SMT | main
R31 | resistor | 1 | 2k0 | Resistor_SMD:R_0603 | 0603WAF2001T5E |  | Resistor | D25 status 5V Pi; place at D25 | 5V | 0603 | SMT | main
R32 | resistor | 1 | 1k5 | Resistor_SMD:R_0603 | 0603WAF2001T5E |  | Resistor | Opto LED | 12V | 0603 | SMT | main
R33 | resistor | 1 | 10k | Resistor_SMD:R_0603 | 0603WAF1002T5E |  | Resistor | Opto RC filter | 12V | 0603 | SMT | main
R34 | resistor | 1 | 10k | Resistor_SMD:R_0603 | 0603WAF1002T5E |  | Resistor | EXP_B P3 pull-up | 3.3V | 0603 | SMT | main
R35 | resistor | 1 | 10k | Resistor_SMD:R_0603 | 0603WAF1002T5E |  | Resistor | EXP_B P4 pull-up | 3.3V | 0603 | SMT | main
R36 | resistor | 1 | 10k | Resistor_SMD:R_0603 | 0603WAF1002T5E |  | Resistor | EXP_B P5 pull-up | 3.3V | 0603 | SMT | main
R4 | resistor | 1 | 470R | Resistor_SMD:R_0603 | 0603WAF4700T5E |  | Resistor | Q4 SSR base; place at Q4 | 3.3V | 0603 | SMT | main
R5 | resistor | 1 | 10k | Resistor_SMD:R_0603 | 0603WAF1002T5E |  | Resistor | Q1 SSR pulldown; place at Q1 | 3.3V | 0603 | SMT | main
R6 | resistor | 1 | 10k | Resistor_SMD:R_0603 | 0603WAF1002T5E |  | Resistor | Q2 SSR pulldown; place at Q2 | 3.3V | 0603 | SMT | main
R7 | resistor | 1 | 10k | Resistor_SMD:R_0603 | 0603WAF1002T5E |  | Resistor | Q3 SSR pulldown; place at Q3 | 3.3V | 0603 | SMT | main
R8 | resistor | 1 | 10k | Resistor_SMD:R_0603 | 0603WAF1002T5E |  | Resistor | Q4 SSR pulldown; place at Q4 | 3.3V | 0603 | SMT | main
R9 | resistor | 1 | 2k2 | Resistor_SMD:R_0603 | 0603WAF2201T5E |  | Resistor | I2C SCL pull-up | 3.3V | 0603 | SMT | main
TP1 | testpoint | 1 | TestPad | TestPoint:TestPoint_Pad_SMD | TP_SMD |  | TestPoint | Debug +3V3; layout L1 (not on schematic yet) | 3.3V | SMD | SMT | main
TP10 | testpoint | 1 | TestPad | TestPoint:TestPoint_Pad_SMD | TP_SMD |  | TestPoint | Debug spare; layout L1 | 3.3V | SMD | SMT | main
TP2 | testpoint | 1 | TestPad | TestPoint:TestPoint_Pad_SMD | TP_SMD |  | TestPoint | Debug GND; layout L1 |  | SMD | SMT | main
TP3 | testpoint | 1 | TestPad | TestPoint:TestPoint_Pad_SMD | TP_SMD |  | TestPoint | Debug +5VA; layout L1 | 5V | SMD | SMT | main
TP4 | testpoint | 1 | TestPad | TestPoint:TestPoint_Pad_SMD | TP_SMD |  | TestPoint | Debug +12VA; layout L1 | 12V | SMD | SMT | main
TP5 | testpoint | 1 | TestPad | TestPoint:TestPoint_Pad_SMD | TP_SMD |  | TestPoint | Debug I2C_SCL; layout L1 | 3.3V | SMD | SMT | main
TP6 | testpoint | 1 | TestPad | TestPoint:TestPoint_Pad_SMD | TP_SMD |  | TestPoint | Debug I2C_SDA; layout L1 | 3.3V | SMD | SMT | main
TP7 | testpoint | 1 | TestPad | TestPoint:TestPoint_Pad_SMD | TP_SMD |  | TestPoint | Debug spare; layout L1 | 3.3V | SMD | SMT | main
TP8 | testpoint | 1 | TestPad | TestPoint:TestPoint_Pad_SMD | TP_SMD |  | TestPoint | Debug spare; layout L1 | 3.3V | SMD | SMT | main
TP9 | testpoint | 1 | TestPad | TestPoint:TestPoint_Pad_SMD | TP_SMD |  | TestPoint | Debug spare; layout L1 | 3.3V | SMD | SMT | main
U1 | IC | 1 | PCA9554PW | Package_SO:TSSOP-16_4.4x5mm_P0.65mm | PCA9554PW | C112612 | IC | I/O Expander A | 3.3V | TSSOP-16 | SMT | main
U2 | IC | 1 | PCA9554PW | Package_SO:TSSOP-16_4.4x5mm_P0.65mm | PCA9554PW | C112612 | IC | I/O Expander B | 3.3V | TSSOP-16 | SMT | main
U4 | IC | 1 | PC817 SMD | Optocoupler_SO-4 | PC817X | C106900 | Optocoupler | 12V presence | 12V | SO-4 | SMT | main
U5 | IC | 1 | TCA9546A | Package_SO:TSSOP-16_4.4x5mm_P0.65mm | TCA9546APWR | C133008 | IC | I2C mux 4ch SHT31 | 3.3V | TSSOP-16 | SMT | main
Q6 | transistor | 1 | AO3401A | Package_TO_SOT_SMD:SOT-23 | AO3401A | C15127 | Transistor | 5V ideal diode (P-FET) | 5V | SOT-23 | SMT | main
J1 | connector | 1 | RJ45 | Connector_RJ:RJ45_Amphenol_54602-x08_Horizontal | 5556416-1 | C86492 | Connector | Uplink Cat5 to main U5 mux; TE no-LED no-magnetics; pair map remotepcb.md §5 |  | RJ45 | TH | remote
J2 | connector | 1 | JST XH 3-pin | Connector_JST:JST_XH_B3B-XH-A_1x03_P2.50mm_Vertical | B3B-XH-A | C157925 | Connector | Universal pulse pulse ch1; pin1 S0_RAIL, pin2 SIG, pin3 GND | 12V | XH-3 | TH | remote
J3 | connector | 1 | JST XH 3-pin | Connector_JST:JST_XH_B3B-XH-A_1x03_P2.50mm_Vertical | B3B-XH-A | C157925 | Connector | Universal pulse pulse ch2; pin1 S0_RAIL, pin2 SIG, pin3 GND | 12V | XH-3 | TH | remote
J4 | connector | 1 | JST XH 3-pin | Connector_JST:JST_XH_B3B-XH-A_1x03_P2.50mm_Vertical | B3B-XH-A | C157925 | Connector | Universal pulse pulse ch3; pin1 S0_RAIL, pin2 SIG, pin3 GND | 12V | XH-3 | TH | remote
J5 | connector | 1 | JST XH 3-pin | Connector_JST:JST_XH_B3B-XH-A_1x03_P2.50mm_Vertical | B3B-XH-A | C157925 | Connector | Universal pulse pulse ch4; pin1 S0_RAIL, pin2 SIG, pin3 GND | 12V | XH-3 | TH | remote
J6 | connector | 1 | JST XH 3-pin | Connector_JST:JST_XH_B3B-XH-A_1x03_P2.50mm_Vertical | B3B-XH-A | C157925 | Connector | DS18B20 temp ch1; pin1 +3V3, pin2 1-Wire, pin3 GND | 3.3V | XH-3 | TH | remote
J7 | connector | 1 | JST XH 3-pin | Connector_JST:JST_XH_B3B-XH-A_1x03_P2.50mm_Vertical | B3B-XH-A | C157925 | Connector | DS18B20 temp ch2; pin1 +3V3, pin2 1-Wire, pin3 GND | 3.3V | XH-3 | TH | remote
J8 | connector | 1 | JST XH 3-pin | Connector_JST:JST_XH_B3B-XH-A_1x03_P2.50mm_Vertical | B3B-XH-A | C157925 | Connector | DS18B20 temp ch3; pin1 +3V3, pin2 1-Wire, pin3 GND | 3.3V | XH-3 | TH | remote
J9 | connector | 1 | JST XH 3-pin | Connector_JST:JST_XH_B3B-XH-A_1x03_P2.50mm_Vertical | B3B-XH-A | C157925 | Connector | DS18B20 temp ch4; pin1 +3V3, pin2 1-Wire, pin3 GND | 3.3V | XH-3 | TH | remote
U1 | IC | 1 | TLP281-4 | Package_SO:SOIC-16_3.9x9.9mm_P1.27mm | TLP281-4(GB-TP,J) | C20525 | Optocoupler | Quad opto field pulse isolation |  | SOIC-16 | SMT | remote
U2 | IC | 1 | DS2482-800 | Package_SO:TSSOP-16_4.4x5mm_P0.65mm | DS2482-800+ |  | IC | 8-ch 1-Wire master I2C 0x18 (AD tied low); LCSC TBD - verify stock | 3.3V | TSSOP-16 | SMT | remote
U3 | IC | 1 | MCP23017A | Package_SO:SOIC-28_7.5x17.9mm_P1.27mm | MCP23017A-E/SO | C112159 | IC | I/O expander I2C 0x22; INT NC; A die required | 3.3V | SOIC-28 | SMT | remote
U4 | IC | 1 | AP2204K-3.3 | Package_TO_SOT_SMD:SOT-23-5 | AP2204K-3.3TRG1 | C82942 | IC | LDO VIN(~12V)->3V3; EN to VIN | 3.3V | SOT-23-5 | SMT | remote
SW1 | switch | 1 | SPST tactile | Button_Switch_SMD:SW_SPST_PTS645 | PTS645S43SMTR92LFS | C139215 | Switch | Gates activity-LED anode rail only | 3.3V | SMD | SMT | remote
R1 | resistor | 1 | 470R | Resistor_SMD:R_0603_1608Metric | 0603WAF4700T5E | C23179 | Resistor | R_IN pulse ch1 opto collector to MCP | 3.3V | 0603 | SMT | remote
R2 | resistor | 1 | 470R | Resistor_SMD:R_0603_1608Metric | 0603WAF4700T5E | C23179 | Resistor | R_IN pulse ch2 opto collector to MCP | 3.3V | 0603 | SMT | remote
R3 | resistor | 1 | 470R | Resistor_SMD:R_0603_1608Metric | 0603WAF4700T5E | C23179 | Resistor | R_IN pulse ch3 opto collector to MCP | 3.3V | 0603 | SMT | remote
R4 | resistor | 1 | 470R | Resistor_SMD:R_0603_1608Metric | 0603WAF4700T5E | C23179 | Resistor | R_IN pulse ch4 opto collector to MCP | 3.3V | 0603 | SMT | remote
R5 | resistor | 1 | 10k | Resistor_SMD:R_0603_1608Metric | 0603WAF1002T5E | C22962 | Resistor | R_PU PULSE_CH1 to +3V3 | 3.3V | 0603 | SMT | remote
R6 | resistor | 1 | 10k | Resistor_SMD:R_0603_1608Metric | 0603WAF1002T5E | C22962 | Resistor | R_PU PULSE_CH2 to +3V3 | 3.3V | 0603 | SMT | remote
R7 | resistor | 1 | 10k | Resistor_SMD:R_0603_1608Metric | 0603WAF1002T5E | C22962 | Resistor | R_PU PULSE_CH3 to +3V3 | 3.3V | 0603 | SMT | remote
R8 | resistor | 1 | 10k | Resistor_SMD:R_0603_1608Metric | 0603WAF1002T5E | C22962 | Resistor | R_PU PULSE_CH4 to +3V3 | 3.3V | 0603 | SMT | remote
R9 | resistor | 1 | 4k7 | Resistor_SMD:R_0603_1608Metric | 0603WAF4701T5E | C23162 | Resistor | R_LED S0_RAIL to TLP281 ch1 anode (~2.3mA @12V) | 12V | 0603 | SMT | remote
R10 | resistor | 1 | 4k7 | Resistor_SMD:R_0603_1608Metric | 0603WAF4701T5E | C23162 | Resistor | R_LED S0_RAIL to TLP281 ch2 anode (~2.3mA @12V) | 12V | 0603 | SMT | remote
R11 | resistor | 1 | 4k7 | Resistor_SMD:R_0603_1608Metric | 0603WAF4701T5E | C23162 | Resistor | R_LED S0_RAIL to TLP281 ch3 anode (~2.3mA @12V) | 12V | 0603 | SMT | remote
R12 | resistor | 1 | 4k7 | Resistor_SMD:R_0603_1608Metric | 0603WAF4701T5E | C23162 | Resistor | R_LED S0_RAIL to TLP281 ch4 anode (~2.3mA @12V) | 12V | 0603 | SMT | remote
R13 | resistor | 1 | 1k0 | Resistor_SMD:R_0603_1608Metric | 0603WAF1001T5E | C21190 | Resistor | Activity LED series ch1 | 3.3V | 0603 | SMT | remote
R14 | resistor | 1 | 1k0 | Resistor_SMD:R_0603_1608Metric | 0603WAF1001T5E | C21190 | Resistor | Activity LED series ch2 | 3.3V | 0603 | SMT | remote
R15 | resistor | 1 | 1k0 | Resistor_SMD:R_0603_1608Metric | 0603WAF1001T5E | C21190 | Resistor | Activity LED series ch3 | 3.3V | 0603 | SMT | remote
R16 | resistor | 1 | 1k0 | Resistor_SMD:R_0603_1608Metric | 0603WAF1001T5E | C21190 | Resistor | Activity LED series ch4 | 3.3V | 0603 | SMT | remote
R17 | resistor | 1 | 10R | Resistor_SMD:R_0603_1608Metric | 0603WAF100JT5E | C25804 | Resistor | R_S0 VIN to S0_RAIL | 12V | 0603 | SMT | remote
R18 | resistor | 1 | 6k8 | Resistor_SMD:R_0603_1608Metric | 0603WAF6801T5E | C23216 | Resistor | Power LED series from S0_RAIL (match main R30 class) | 12V | 0603 | SMT | remote
R19 | resistor | 1 | 22R | Resistor_SMD:R_0603_1608Metric | 0603WAF220JT5E | C23206 | Resistor | I2C SDA series at remote | 3.3V | 0603 | SMT | remote
R20 | resistor | 1 | 22R | Resistor_SMD:R_0603_1608Metric | 0603WAF220JT5E | C23206 | Resistor | I2C SCL series at remote | 3.3V | 0603 | SMT | remote
R21 | resistor | 1 | 2k2 | Resistor_SMD:R_0603_1608Metric | 0603WAF2201T5E | C22940 | Resistor | 1-Wire pull-up ch1 to +3V3 at DS2482 | 3.3V | 0603 | SMT | remote
R22 | resistor | 1 | 2k2 | Resistor_SMD:R_0603_1608Metric | 0603WAF2201T5E | C22940 | Resistor | 1-Wire pull-up ch2 to +3V3 at DS2482 | 3.3V | 0603 | SMT | remote
R23 | resistor | 1 | 2k2 | Resistor_SMD:R_0603_1608Metric | 0603WAF2201T5E | C22940 | Resistor | 1-Wire pull-up ch3 to +3V3 at DS2482 | 3.3V | 0603 | SMT | remote
R24 | resistor | 1 | 2k2 | Resistor_SMD:R_0603_1608Metric | 0603WAF2201T5E | C22940 | Resistor | 1-Wire pull-up ch4 to +3V3 at DS2482 | 3.3V | 0603 | SMT | remote
C1 | capacitor | 1 | 100n | Capacitor_SMD:C_0805_2012Metric | CL10B104KB8NNNC | C14663 | Capacitor | C_RC debounce PULSE_CH1 | 3.3V | 0805 | SMT | remote
C2 | capacitor | 1 | 100n | Capacitor_SMD:C_0805_2012Metric | CL10B104KB8NNNC | C14663 | Capacitor | C_RC debounce PULSE_CH2 | 3.3V | 0805 | SMT | remote
C3 | capacitor | 1 | 100n | Capacitor_SMD:C_0805_2012Metric | CL10B104KB8NNNC | C14663 | Capacitor | C_RC debounce PULSE_CH3 | 3.3V | 0805 | SMT | remote
C4 | capacitor | 1 | 100n | Capacitor_SMD:C_0805_2012Metric | CL10B104KB8NNNC | C14663 | Capacitor | C_RC debounce PULSE_CH4 | 3.3V | 0805 | SMT | remote
C5 | capacitor | 1 | 10u | Capacitor_SMD:C_0805_2012Metric | CL10A106KA8NNNC | C15850 | Capacitor | C_S0 bulk on S0_RAIL (prefer >=25V rating) | 12V | 0805 | SMT | remote
C6 | capacitor | 1 | 100n | Capacitor_SMD:C_0805_2012Metric | CL10B104KB8NNNC | C14663 | Capacitor | C_S0 HF on S0_RAIL | 12V | 0805 | SMT | remote
C7 | capacitor | 1 | 100u | Capacitor_SMD:CP_Elec_6.3x5.4mm | RVT1C101M0605 | C72473 | Capacitor | LDO Cin electrolytic on VIN (16V class) | 12V | 6.3x5.4 | SMT | remote
C8 | capacitor | 1 | 100n | Capacitor_SMD:C_0805_2012Metric | CL10B104KB8NNNC | C14663 | Capacitor | LDO Cin ceramic on VIN | 12V | 0805 | SMT | remote
C9 | capacitor | 1 | 47u | Capacitor_SMD:C_0805_2012Metric | CL10A476MQ8NNNC | C15907 | Capacitor | 3V3 bulk near LDO out / IC cluster | 3.3V | 0805 | SMT | remote
C10 | capacitor | 1 | 10u | Capacitor_SMD:C_0805_2012Metric | CL10A106KA8NNNC | C15850 | Capacitor | 3V3 bulk near DS2482/MCP cluster | 3.3V | 0805 | SMT | remote
C11 | capacitor | 1 | 100n | Capacitor_SMD:C_0805_2012Metric | CL10B104KB8NNNC | C14663 | Capacitor | Decouple U2 DS2482 VCC | 3.3V | 0805 | SMT | remote
C12 | capacitor | 1 | 100n | Capacitor_SMD:C_0805_2012Metric | CL10B104KB8NNNC | C14663 | Capacitor | Decouple U3 MCP23017A VCC | 3.3V | 0805 | SMT | remote
C13 | capacitor | 1 | 100n | Capacitor_SMD:C_0805_2012Metric | CL10B104KB8NNNC | C14663 | Capacitor | Decouple U4 AP2204 output / local | 3.3V | 0805 | SMT | remote
C14 | capacitor | 1 | 100n | Capacitor_SMD:C_0805_2012Metric | CL10B104KB8NNNC | C14663 | Capacitor | Decouple logic HF near opto/MCP | 3.3V | 0805 | SMT | remote
D1 | diode | 1 | ESD5B5.0ST5G | Diode_SMD:D_SOD-323 | ESD5B5.0ST5G | C2927587 | Protection | ESD PULSE_CH1 to GND (logic side) | 5V | SOD-323 | SMT | remote
D2 | diode | 1 | ESD5B5.0ST5G | Diode_SMD:D_SOD-323 | ESD5B5.0ST5G | C2927587 | Protection | ESD PULSE_CH2 to GND (logic side) | 5V | SOD-323 | SMT | remote
D3 | diode | 1 | ESD5B5.0ST5G | Diode_SMD:D_SOD-323 | ESD5B5.0ST5G | C2927587 | Protection | ESD PULSE_CH3 to GND (logic side) | 5V | SOD-323 | SMT | remote
D4 | diode | 1 | ESD5B5.0ST5G | Diode_SMD:D_SOD-323 | ESD5B5.0ST5G | C2927587 | Protection | ESD PULSE_CH4 to GND (logic side) | 5V | SOD-323 | SMT | remote
D5 | diode | 1 | LED | LED_SMD:LED_0603_1608Metric | 19-217/R6C-AL1M2QY/3T | C2297 | LED | Activity pulse ch1; gated by SW1 | 3.3V | 0603 | SMT | remote
D6 | diode | 1 | LED | LED_SMD:LED_0603_1608Metric | 19-217/R6C-AL1M2QY/3T | C2297 | LED | Activity pulse ch2; gated by SW1 | 3.3V | 0603 | SMT | remote
D7 | diode | 1 | LED | LED_SMD:LED_0603_1608Metric | 19-217/R6C-AL1M2QY/3T | C2297 | LED | Activity pulse ch3; gated by SW1 | 3.3V | 0603 | SMT | remote
D8 | diode | 1 | LED | LED_SMD:LED_0603_1608Metric | 19-217/R6C-AL1M2QY/3T | C2297 | LED | Activity pulse ch4; gated by SW1 | 3.3V | 0603 | SMT | remote
D9 | diode | 1 | LED | LED_SMD:LED_0603_1608Metric | 19-217/R6C-AL1M2QY/3T | C2297 | LED | Power present on S0_RAIL; always on with R18 | 12V | 0603 | SMT | remote
MH1 | mountinghole | 1 | MountingHole | MountingHole:MountingHole_3.2mm_M3 | MH3.2 |  | Mechanical | Mounting hole; copper clearance |  | 3.2mm | TH | remote
MH2 | mountinghole | 1 | MountingHole | MountingHole:MountingHole_3.2mm_M3 | MH3.2 |  | Mechanical | Mounting hole; copper clearance |  | 3.2mm | TH | remote
MH3 | mountinghole | 1 | MountingHole | MountingHole:MountingHole_3.2mm_M3 | MH3.2 |  | Mechanical | Mounting hole; copper clearance |  | 3.2mm | TH | remote
MH4 | mountinghole | 1 | MountingHole | MountingHole:MountingHole_3.2mm_M3 | MH3.2 |  | Mechanical | Mounting hole; copper clearance |  | 3.2mm | TH | remote
D10 | diode | 1 | SMBJ12A | Diode_SMD:D_SMB | SMBJ12A | C353398 | Protection | VIN to GND TVS at remote RJ45 | 12V | SMB | SMT | remote
C15 | capacitor | 1 | 2u2 | Capacitor_SMD:C_0805_2012Metric | CL10A225KA8NNNC | C15808 | Capacitor | LDO VOUT ceramic >=2.2uF | 3.3V | 0805 | SMT | remote

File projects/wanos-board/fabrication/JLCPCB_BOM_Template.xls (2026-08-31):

Comment | Designator | Footprint | JLCPCB Part#(optional)
100uF | C1 | CASE-B_3528 | C16133
100nF | C2, C9, C10 | 0603 | C14663
300KΩ | R4, R7 | 0603 | C23024
15KΩ | R5, R6 | 0603_R | C22809
100KΩ | R1, R3 | 0603_R | C25803
10uF | C3-5 | 1206_C | C13585
100Ω | R2 | 0603_R | C22775
1N4148WS | D1 | SOD-323 | C2128
LM358DR2G | U1 | SOIC-8_150mil | C7950
HT7550-1 | VR1 | SOT-89(SOT-89-3) | C16106

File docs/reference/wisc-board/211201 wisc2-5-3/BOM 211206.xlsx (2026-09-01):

ref | value5 | # | type | value8 | needed | ordered
C1 | 10u | 1 | C | C/10u | 1 | 15
C2 | .1u | 2 | C | C/100n | 3 | 30
C3 | .1u | 3 | C
C5 | .1u | 5 | C
D1 | 5V_ext | 1 | D
D2 | pwr_Raspi | 2 | D
D3 | 1N4002 | 3 | D
D4 | SSR_safety | 4 | D
D5 | SSR_IR | 5 | D
D6 | SSR_S1 | 6 | D
D7 | SSR_S2 | 7 | D
D8 | SSR_S3 | 8 | D
D9 | pwr_Raspi | 9 | D
D10 | pwr_Raspi | 10 | D
D11 | pwr_Raspi | 11 | D
D12 | cold | 12 | D
D13 | hot | 13 | D
F1 | 2.5A | 1 | F
F2 | 2A | 2 | F
J2 | kWh | 2 | J | con2 | 4 | 40
J4 | 5V EXT | 4 | J | 2
J3 | e-ink | 3 | J | HDMI
J11 | deur_sauna | 11 | J | 2
J12 | deur_badk | 12 | J | 2
J6 | USB_A | 6 | J | USB
J5 | waterflow | 5 | J | con4 | 5 | 40
J7 | sens-badk | 7 | J | 4
J8 | sens-cinema | 8 | J | 4
J9 | sens-sauna-mid | 9 | J | 4
J10 | sens-sauna-high | 10 | J | 4
J1 | SSR | 1 | J | con5 | 1 | 10
P1 | Raspi header | 1 | P
Q1 | 2N7000 | 1 | Q | 2N7000 | 2 | 20
Q2 | 2N7000 | 2 | Q
Q3 | PN2222A | 3 | Q | PN2222A | 5 | replaced with 2N3904, 50 stuks
Q4 | PN2222A | 4 | Q
Q5 | PN2222A | 5 | Q
Q6 | PN2222A | 6 | Q
Q7 | PN2222A | 7 | Q
R2 | 10k | 2 | R | R/10k | 17 | 100
R5 | 10k | 5 | R
R7 | 10k | 7 | R
R8 | 10k | 8 | R
R10 | 10k | 10 | R
R12 | 10k | 12 | R
R13 | 10k | 13 | R
R16 | 10k | 16 | R
R19 | 10k | 19 | R
R22 | 10k | 22 | R
R29 | 10k | 29 | R
R32 | 10k | 32 | R
R34 | 10k | 34 | R
R36 | 10k | 36 | R
R38 | 10k | 38 | R
R42 | 10k | 42 | R
R43 | 10k | 43 | R
R3 | 220 | 3 | R | R/220 | 12 | 100
R4 | 220 | 4 | R
R14 | 220 | 14 | R
R17 | 220 | 17 | R
R20 | 220 | 20 | R
R25 | 220 | 25 | R
R30 | 220 | 30 | R
R39 | 220 | 39 | R
R44 | 220 | 44 | R
R45 | 220 | 45 | R
R46 | 220 | 46 | R
R47 | 220 | 47 | R
R31 | 2k2 | 31 | R | R/2k2 | 4 | 100
R33 | 2k2 | 33 | R
R35 | 2k2 | 35 | R
R37 | 2k2 | 37 | R
R1 | 330 | 1 | R | R/330 | 9 | 100
R6 | 330 | 6 | R
R9 | 330 | 9 | R
R23 | 330 | 23 | R
R24 | 330 | 24 | R
R26 | 330 | 26 | R
R27 | 330 | 27 | R
R40 | 330 | 40 | R
R41 | 330 | 41 | R
R11 | 470 | 11 | R | R/470 | 5 | 100
R15 | 470 | 15 | R
R18 | 470 | 18 | R
R21 | 470 | 21 | R
R28 | 470 | 28 | R
 |  | #VALUE!
 |  | #VALUE!
 |  | #VALUE!
 |  | #VALUE!
 |  | #VALUE!
 |  | #VALUE!
 |  | #VALUE!
 |  | #VALUE!
 |  | #VALUE!
 |  | #VALUE!
 |  | #VALUE!
 |  | #VALUE!
 |  | #VALUE!
 |  | #VALUE!
 |  | #VALUE!
 |  | #VALUE!
 |  | #VALUE!
 |  | #VALUE!
 |  | #VALUE!
 |  | #VALUE!
 |  | #VALUE!
 |  | #VALUE!
 |  | #VALUE!
 |  | #VALUE!
 |  | #VALUE!
 |  | #VALUE!
 |  | #VALUE!
 |  | #VALUE!
 |  | #VALUE!
 |  | #VALUE!
 |  | #VALUE!
 |  | #VALUE!
 |  | #VALUE!
 |  | #VALUE!
 |  | #VALUE!

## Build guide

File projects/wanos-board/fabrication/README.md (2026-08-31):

<!-- --- file: projects/wanos-board/fabrication/README.md -->

# Fabrication outputs

Generated Gerber, drill, BOM, and centroid files for JLCPCB live here.

**Do not hand-edit** Gerbers — regenerate from KiCad per [`docs/jlcpcb-ordering.md`](../../../docs/jlcpcb-ordering.md).

| File pattern | Purpose |
|---|---|
| `*.gbr` / `*.gbrjob` | Copper, mask, silk, outline |
| `*.drl` | Drill hits |
| `bom.csv` | Bill of materials |
| `*.pos` / `*-pos.csv` | SMT centroid (CPL) |
| `wanos-board-gerbers.zip` | Upload bundle for PCB fab |

Binary outputs are gitignored; commit this README and any export scripts once **J1** defines the repeatable flow.

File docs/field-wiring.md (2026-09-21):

<!-- --- file: docs/field-wiring.md -->

# wanos-pcb-v1 — field wiring and JST pinouts

Locked **R1** (2026-09-01) + **R2** (2026-09-01). Canonical electrical behaviour → [`board-spec.md`](board-spec.md). Connector designators → [`projects/wanos-board/components.xlsx`](../projects/wanos-board/components.xlsx).

**WISC reference pinout for all 4-pin I²C JST:** WISC **2.6.4** board **J7** (not 2.5.3 SHT11 DATA/CLOCK headers).

**KiCad schematic sheets:** **J14** + **J17** + **J40** → **`pi_power.kicad_sch`**. Field expanders + water **J4** → **`io_expanders.kicad_sch`**. Door + kWh front-ends (greenfield) → **`pulse_inputs.kicad_sch`** (**Pulse_Inputs**; retire duplicate **J2/J3/J6/J7** stubs on IO_Expanders when adopting). **J13** → **`ssr_drivers.kicad_sch`**. **J9–J12**, **J18**, **J16** → **`i2c_plant.kicad_sch`**. **J1** → **`hdmi_spi.kicad_sch`**.

---

## 1. Standard 4-pin I²C JST (XH)

Used on **J9–J12**, **J18** (SHT31 plant) and **J16** (LCD).

| Pin | Signal | Notes |
|---:|---|---|
| **1** | **GND** | Common return |
| **2** | **SDA** | Pi I²C data (BCM2) on local bus |
| **3** | **SCL** | Pi I²C clock (BCM3) on local bus |
| **4** | **+3V3** | Sensor / LCD module supply |

Verified from WISC `wisc2-6-4.kicad_pcb` **J7** pad nets.

---

## 2. Standard 2-pin pulse / door JST

Used on **J2–J3** (doors), **J6–J7** (kWh). Matches WISC 2.5.3 production practice.

| Pin | Signal |
|---:|---|
| **1** | **GND** |
| **2** | **Pulse / reed signal** (to expander input, 10k pull-up on PCB) |

---

## 2a. Water meters — J4 (RJ45) + YF-B6/B10 over Cat5 (~10 m)

**Sensor:** YF-B6 / YF-B10 hall flow meter — datasheet [`reference/datasheets/external/YF-B6 B10 waterflow-sensor.pdf`](reference/datasheets/external/YF-B6%20B10%20waterflow-sensor.pdf).

| Spec | Value |
|---|---|
| Supply | **DC 5–15 V** (min **4.5 V**) → board **`+5VA`** |
| Output | **Open-drain** (requires pull-up) — yellow wire |
| Wires (sensor) | Red **VDD**, black **GND**, yellow **SIG** |
| Rate | \(F = 6.6 \times Q\) (L/min) → ~7–200 Hz |
| Field cable | **One Cat5/Cat5e UTP** (~**10 m**) → board **J4** RJ45 (8P8C) |

**No MOSFET / opto** on v1 — OD + pull-up to **`+3V3`** is level-safe into PCA9554.

**On-board front-end** (sheet **`water_meters.kicad_sch`**), per SIG channel:

| Element | Value | Role |
|---|---|---|
| **TVS** | **PESD5V0S1BA** (**D25**–**D28**) | ESD / surge clamp SIG → **GND** (long Cat5) — [`pesd5v0s1ba.pdf`](reference/datasheets/pesd5v0s1ba.pdf) |
| **Rpu** | **10 kΩ** → **`+3V3`** | Idle HIGH |
| **Rs** | **330 Ω** | Series field → expander |
| **Cd** | **100 nF** | Debounce / EMI (\(\tau \approx 1\,\text{ms}\)) |
| **Rled + D** | **1k0** + LED | Activity (lights on pulse / SIG low) |

Plus **D29** **SMBJ5.0A** across **`+5VA`** → **GND** at **J4** (sensor supply clamp) — [`smbj5.0a.pdf`](reference/datasheets/smbj5.0a.pdf).

**J4** — TE Connectivity **5556416-1** (LCSC **C86492**): RJ45 8P8C **TH**, **no LED**, **no magnetics**, unshielded. Schematic uses `Connector_Generic:Conn_01x08` + footprint **`Connector_RJ:RJ45_Amphenol_54602-x08_Horizontal`** (Amphenol **54602** land-pattern class — [`amphenol-54602.pdf`](reference/datasheets/amphenol-54602.pdf), [`amphenol-54602-drawing.pdf`](reference/datasheets/amphenol-54602-drawing.pdf)). JLC assembly: **wave soldering**.

Optional Cat5 foil/drain: bond at enclosure / PE (jack has no SH tabs) — [`grounding.md`](grounding.md).

### Cat5 wiring (T568B) — recommended

Colour cheat-sheet: [`reference/datasheets/rj45-t568b-wiring-colors.jpg`](reference/datasheets/rj45-t568b-wiring-colors.jpg).

| J4 pin | T568B wire | Pair | Net | Field / sensor |
|---:|---|---|---|---|
| **1** | White/Orange | 2 | `WM_B1_COLD` | Bath 1 cold yellow |
| **2** | Orange | 2 | **GND** | Bath 1 cold black (pair return) |
| **3** | White/Green | 3 | `WM_B1_HOT` | Bath 1 hot yellow |
| **6** | Green | 3 | **GND** | Bath 1 hot black (pair return) |
| **4** | Blue | 1 | **`+5VA`** | All reds (VDD) |
| **5** | White/Blue | 1 | **GND** | Extra / common black return |
| **7** | White/Brown | 4 | `WM_B2_COLD` | Bath 2 cold yellow |
| **8** | Brown | 4 | `WM_B2_HOT` | Bath 2 hot yellow |

**Bath 2 blacks:** splice to any **GND** conductor (pins **2** / **5** / **6**). **Bath 2** cold+hot share pair 4 (OK at ~7–200 Hz); do not leave unused pair conductors floating at the board end — they are already assigned.

**Shielded Cat5 (optional):** jack is **unshielded** — bond foil/drain to enclosure **PE** / chassis at **board end only** (not both ends).

| Net | Expander |
|---|---|
| `WM_B1_COLD` / `WM_B1_HOT` | **U1** P2 / P3 |
| `WM_B2_COLD` / `WM_B2_HOT` | **U1** P4 / P5 |

**J5** is **unused** on v1 (former second water JST — collapsed into **J4**).

---

## 2b. kWh meters — J6 / J7 (S0 pulse, ~10 m Cat5)

**PCB:** two channels only (**J6** / **J7**). Site may have additional DIN kWh meters that stay display-only or use another controller — full inventory + pulse specs → [`external-plant.md`](external-plant.md) § 5a.

**Front-end design reference:** Eastron **SDM72D-M** — [`sdm72d-m.pdf`](reference/datasheets/external/sdm72d-m.pdf). Other plant meters (DDS-1Y-18L, Finder **7E.12.8.230.0002**) share the SO / passive-pulse idea but **not** the same V / imp/kWh numbers.

**Pulse output (SDM72 manual class):** passive **opto / transistor**, polarity-dependent, needs external **5–27 V DC**, max **~27 mA**. Default **1000 imp/kWh**, pulse width **~35 ms** (fixed at that constant). Idle open; pulse closes to the meter’s pulse return.

**Board connectors:** **J6** (main) / **J7** (aux) — 2-pin JST, pin **1 = GND**, pin **2 = SIG** → Expander A **P6** / **P7**.

**Cable:** ~**10 m Cat5** (one pair SIG+GND per meter is enough; spare pairs unused or tied GND at PCB end).

### Target on-board front-end (wanos greenfield — per channel)

Same idea as water YF channels, but pull-up on **`+5VA`** because the SDM72 pulse rail is specified **≥ 5 V** (do **not** use only `+3V3` pull-up).

```
  +5VA ---- Rpu 10k ----+---- Jx pin2 (SIG) ---- field Cat5 ---- SDM72 pulse (+)
                        |                              |
                        +---- Rled 1k0 ----|>|----+     SDM72 pulse (-) ---- Jx pin1 (GND)
                        |                   LED  |
                        |                        +---- (LED cathode toward SIG so LED
                        |                              lights on pulse LOW)
                        |
                        +---- Rs 330 ----+---- EXP_A_Px (U1 P6/P7)
                        |                |
                       TVS              Cd 100n
                    PESD5V0S1BA           |
                        |                |
                       GND              GND
```

| Ref | Value | Role |
|---|---|---|
| **R51** / **R54** | **10 kΩ** to **`+5VA`** | Idle HIGH; feeds meter opto (~0.5 mA when closed, ≪ 27 mA) |
| **R52** / **R55** | **330 Ω** | Series into PCA9554 (cable / ESD) |
| **C24** / **C25** | **100 nF** | Debounce / EMI at expander pin |
| **D34** / **D36** | **PESD5V0S1BA** | SIG clamp at board |
| **R53**/**R56** + **D35**/**D37** | **1k0** from **`+5VA`** | Activity; lights when SIG is pulled LOW |

**Logic:** idle **HIGH** (~5 V on expander pin — PCA9554 I/O abs-max allows this with VCC = 3.3 V); pulse **LOW**; software counts falling edges / polls.

**Polarity:** respect meter pulse **+ / −** marking on the JST (SIG = +, GND = −).

**Schematic:** [`pulse_inputs.kicad_sch`](../projects/wanos-board/pulse_inputs.kicad_sch) — **J6**/**J7** with **R51**–**R56**, **C24**/**C25**, **D34**–**D37**. Until old stubs on **`io_expanders`** are removed, expect duplicate designators.

---

## 2c. Doors — J2 / J3 (reed contacts)

**Plant:** reed switches (dry contact to **GND** when active). ~field cable (treat like pulse inputs for EMI).

**Board:** **J2** sauna → Exp A **P1**; **J3** bathroom → Exp A **P0**.

### Target / drawn front-end (same sheet as kWh)

Pull-up on **`+3V3`** (reed needs no 5 V rail):

| Ref | Value | Role |
|---|---|---|
| **R45**/**R48** | **10 kΩ** → **`+3V3`** | Idle HIGH |
| **R46**/**R49** | **330 Ω** | Series into PCA9554 |
| **C22**/**C23** | **100 nF** | Debounce / EMI at expander (`τ` with 10k ≈ **1 ms** — suitable for reed) |
| **D30**/**D32** | **PESD5V0S1BA** | SIG TVS |
| **R47**/**R50** + LED | **1k0** from **`+3V3`** | Activity on pulse/contact **LOW** |

**Schematic:** [`pulse_inputs.kicad_sch`](../projects/wanos-board/pulse_inputs.kicad_sch) — **J2**/**J3**. Retire LED-only stubs on **`io_expanders`** when adopting.

---

## 3. Connector map (J designators)

| Ref | Pins | Function | Cable notes |
|---|---:|---|---|
| **J1** | HDMI | E-ink SPI | See [`hdmi-spi-eink.md`](hdmi-spi-eink.md) |
| **J2** | 2 | Door sauna | |
| **J3** | 2 | Door bathroom | |
| **J4** | 8 (RJ45) | Water meters B1+B2 | Cat5 ~10 m — § 2a |
| **J5** | — | **Unused v1** | Former water JST; collapsed into **J4** |
| **J6** | 2 | kWh main | |
| **J7** | 2 | kWh aux | Full-board feature |
| **J8** | 4 | Sauna LCD buttons | Cat5 UTP — § 5 |
| **J9** | 4 | SHT31 bathroom | Mux **ch 0**, Cat5 ~4–5 m |
| **J10** | 4 | SHT31 cinema | Mux **ch 1** |
| **J11** | 4 | SHT31 sauna mid | Mux **ch 2** |
| **J12** | 4 | SHT31 sauna high | Mux **ch 3** |
| **J13** | 5 | SSR field | § 6 |
| **J14** | 2 | 12 V in (KF301) — **`+12V`** + GND · schematic: **`pi_power`** | § 9 |
| **J16** | 4 | LCD I²C (both screens) | § 4 |
| **J17** | 2 | **5 V screw in** (KF301) — external PSU + / GND · schematic: **`pi_power`** | § 10 |
| **J40** | 40 | Pi header | |
| **J41** | — | USB-C | **DNP v1** |

---

## 4. LCD — one 4-pin header (J16)

Both LCD modules share **one** JST: tails are wired **in parallel** at the harness (same as deployed WISC/LCD practice).

- **Pinout:** § 1 (4-pin I²C).
- **Addresses:** each LCD backpack must use a **different I²C address** (typical jumper: `0x27` vs `0x3F`).
- **v1:** single **J16** only — no second LCD header.

---

## 5. Sauna buttons — Cat5 UTP to J8 (4-pin)

Board: expander inputs with pull-up; button shorts to **GND** when pressed.

**J8 (pin 1 = square pad):**

| J8 pin | Signal | Cat5 (T568B) | Button end |
|---:|---|---|---|
| **1** | **GND** | Brown + Brown/white (tie together) | Common return |
| **2** | **BTN1** | Orange/white | Switch to GND |
| **3** | **BTN2** | Green/white | Switch to GND |
| **4** | **BTN3** | Blue/white | Switch to GND |

Leave Orange, Green, Blue solids unconnected (or tie to GND at PCB end only).

---

## 6. SSR — J13 (5-pin field header)

**Connector:** **B5B-XH-A 1×05** vertical on **`ssr_drivers.kicad_sch`**.

| Pin | Signal | wanos channel |
|---:|---|---|
| **1** | **GND** | Control return |
| **2** | `SSR_PHASE_W` | Sauna phase W |
| **3** | `SSR_PHASE_V` | Sauna phase V |
| **4** | `SSR_PHASE_U` | Sauna phase U |
| **5** | `SSR_IR` | IR relay |

**Safety gate:** **BCM 4** → on-board **Q5** / **`SAFETY_BUS`** — **not** on this header. See [`board-spec.md`](board-spec.md) § 4.1.

**Harness reuse:** a legacy 5-pin SSR tail may plug in if its pinout matches this table ([`external-plant.md`](external-plant.md) § 5).

---

## 9. 12 V input — J14 (KF301-2P)

Schematic: **`pi_power.kicad_sch`** (with **D3** SMBJ12A TVS at entry).

| Pin | Signal |
|----:|---|
| **1** | **`+12V`** — after external temp safety |
| **2** | **GND** |

Detail → [`external-plant.md`](external-plant.md) § 3.

---

## 10. 5 V input — J17 (KF301-2P)

Schematic: **`pi_power.kicad_sch`**.

| Pin | Signal |
|----:|---|
| **1** | **+5V** — external PSU positive (before on-board conditioning) |
| **2** | **GND** |

On-board chain: **F1** 2 A polyfuse (resettable) → **Q6** ideal diode → **D1** overvoltage clamp → **`+5VA`** → **FB1** → **`+5V-PI`** → **J40** pins **2 & 4** (Pi header 5 V injection).

**J41** USB-C is **not populated** on v1.

---

## 7. SHT31 plant — Cat5 per sensor

- **5×** separate Cat5 runs (~**4–5 m** each), one **4-pin JST** per sensor (**J9–J12**, **J18**).
- **TCA9548A** (U5) on PCB @ I²C **`0x70`** — 8-ch mux; select channel, then poll SHT31 at **`0x44`** (all modules use default address). Channels **5–6** reserved for **wanos-remote** ([`remotepcb.md`](remotepcb.md)); ch **7** NC until used.
- **J16** LCD remains on the root Pi I²C bus (not behind the mux).
- **No PCA9615** on v1 — direct I²C through mux per channel.
- **Pull-ups:** **2k2** on main `I2C_SCL` / `I2C_SDA` only (**R9**, **R10**) — sized for ~5 m Cat5 @ 100 kHz.

**Migration from WISC SHT11:** old 4-pin plant headers used pin 2 = **CLOCK**, pin 3 = **DATA**. I²C uses pin 2 = **SDA**, pin 3 = **SCL** — re-pin at the board end or replace tails.

| Mux ch | JST | Location |
|---:|---|---|
| 0 | J9 | Bathroom |
| 1 | J10 | Cinema |
| 2 | J11 | Sauna mid |
| 3 | J12 | Sauna high |
| 4 | J18 | Spare (location TBD) |
| 5–7 | — | NC |

---

## 8. I²C pull-ups (R1 lock)

| Ref | Value | Net |
|---|---|---|
| **R9** | **2k2** | `I2C_SCL` → 3.3 V |
| **R10** | **2k2** | `I2C_SDA` → 3.3 V |

Do not populate extra pull-up pairs on the same segment. Disable Pi internal I²C pull-ups when relying on board resistors.

---

## Related

- [`io-expander-map.md`](io-expander-map.md) — expander pin map
- [`gpio-interface.md`](gpio-interface.md) — software views
- WISC summaries → [`reference/wisc-board/`](reference/wisc-board/)
- External plant → [`external-plant.md`](external-plant.md) · Grounding → [`grounding.md`](grounding.md)

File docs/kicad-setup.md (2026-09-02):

<!-- --- file: docs/kicad-setup.md -->

# KiCad setup — wanos-pcb-v1

Local toolchain for `projects/wanos-board/`. Primary automation path: **KiCad 10 + Konnect + Cursor MCP**.

Upstream Konnect docs: [github.com/mixelpixx/Konnect](https://github.com/mixelpixx/Konnect) (do not copy README into this repo).

Optional reference: local `kicad-cursor` repo if present on your machine.

**WISC reference boards** (read-only in repo): [`reference/wisc-board/`](reference/wisc-board/) — Konnect can inspect them; do not edit KiCad sources there.

---

## Requirements

| Tool | Purpose |
|---|---|
| **KiCad 10** | Schematic + PCB editor |
| **Konnect** (PCM plugin) | MCP tools: schematic, PCB, DRC, JLC search, fab export |
| **Cursor** | Agent + MCP client |
| **kicad-cli** | ERC/DRC batch, Gerber export (also used by Konnect) |

**Not required for Konnect:** Python, Node.js, SWIG.

---

## End-to-end checklist (verified on Windows)

Work through in order. **Ops1** closed **2026-09-01** when steps 1–8 pass (verified on WISC `wisc2-6-4` reference — `open_project` → `ipc_available: true` with KiCad PCB Editor open).

| Step | Action | Pass criterion |
|---:|---|---|
| 1 | Install Konnect via PCM (§ 1) | **PCB Editor → Tools → External Plugins → Konnect** exists |
| 2 | Enable KiCad API (§ 2) | Preferences shows **Listening at ipc://…** |
| 3 | Open a `.kicad_pcb` in **PCB Editor** (§ 3) | Board visible in layout — not Project Manager only |
| 4 | Configure Cursor MCP (§ 4) | **Customize → MCPs → konnect** = Connected |
| 5 | Wire IPC socket to Konnect (§ 5) | `KICAD_API_SOCKET` in `.cursor/mcp.json` **or** Konnect settings saved |
| 6 | Reload Cursor | `Ctrl+Shift+P` → **Developer: Reload Window** |
| 7 | Keep KiCad running with board open | Same KiCad session as step 2–3 |
| 8 | Agent test: **`open_project`** (§ 6) | `ipc_available: true`, `kicad_ui_running: true` |

---

## 1. Install Konnect

1. Download `konnect-pcm-v<version>-windows.zip` from [Konnect Releases](https://github.com/mixelpixx/Konnect/releases).
2. KiCad 10 → **Tools → Plugin and Content Manager → Install from File**.
3. Restart KiCad.
4. Open any project → open **PCB Editor** (double-click the `.kicad_pcb` or use the PCB icon).
5. Verify: **PCB Editor → Tools → External Plugins → Konnect**.

**Note:** Plugin and Content Manager (**Installed** tab) only shows that Konnect is installed. It does **not** configure IPC or MCP — that is separate (§ 4–5).

Binary path (typical):

```text
C:\Users\<YOU>\Documents\KiCad\10.0\3rdparty\plugins\com_github_mixelpixx_konnect\bin\konnect.exe
```

Konnect plugin directory (Python launcher + optional `settings.json`):

```text
C:\Users\<YOU>\Documents\KiCad\10.0\3rdparty\plugins\com_github_mixelpixx_konnect\
```

---

## 2. Enable KiCad IPC API server

1. **KiCad → Preferences → Plugins** (KiCad API section).
2. Check **Enable KiCad API**.
3. **Python interpreter:** use **Detect Automatically** (typical: `C:\Program Files\KiCad\10.0\bin\pythonw.exe`, Python 3.11.x).
4. Click **OK**. If the API was off at launch, **restart KiCad** once.
5. Re-open **Preferences → Plugins** and confirm the status line:

```text
Listening at ipc://C:\Users\<YOU>\AppData\Local\Temp\kicad\api.sock
```

That full `ipc://…` string is the IPC address. Copy it for § 5.

### Windows: no `api.sock` file in Explorer?

Normal. On Windows, KiCad’s IPC uses an **NNG named pipe**, not a regular disk file. The `%TEMP%\kicad\` folder may exist while **`api.sock` is absent** in Explorer or `Test-Path`. Trust the **Listening at …** line in Preferences, not file existence.

If the listening line is **missing** after restart: enable the checkbox again, restart KiCad, then open **PCB Editor** with a board loaded (§ 3).

---

## 3. Open the board in PCB Editor (required for live IPC)

KiCad 10 runs as one **`kicad.exe`** process — you will not see separate `pcbnew` / `eeschema` processes.

For Konnect **live** PCB tools and `open_project`:

1. Open the project (Project Manager is fine to start).
2. **Open PCB Editor** — load the `.kicad_pcb` (e.g. reference `docs/reference/wisc-board/211201 wisc2-5-3/wisc-v5.kicad_pcb`).
3. Leave **PCB Editor** open while using Cursor Agent.

**Project Manager alone is not enough** for `open_project` to list an open board.

**External Plugins → Konnect** is available from **PCB Editor → Tools** (and schematic editor when open). Use it for Konnect **settings** (IPC socket path, optional Start Server from KiCad). Cursor uses its own `konnect.exe` via MCP (§ 4) — you do not need **Start Server** in KiCad for Cursor Agent.

---

## 4. Cursor MCP (Konnect) — JSON only

On current Cursor builds, **+ New** under **Customize → MCPs** opens (or creates) a JSON file — there is **no separate stdio form**.

### Steps

1. Open **Customize** → **MCPs** tab.
2. Click **+ New** → choose **wanos-pcb** (workspace) or **User** (global).
3. Cursor opens **`.cursor/mcp.json`** (workspace) or **`%USERPROFILE%\.cursor\mcp.json`** (user).
4. Paste the block in § 5 (includes IPC env var).
5. **Save** the JSON file.
6. **Customize → MCPs** should list **konnect** with **Connected** / green status after reload (step 6 of checklist).

**Command Palette:** `Ctrl+Shift+P` → **Open MCPs** jumps to the same tab.

### Workspace config (this repo)

File: [`.cursor/mcp.json`](../.cursor/mcp.json)

Use doubled backslashes (`\\`) in JSON on Windows. Replace `<YOU>` with your Windows user name.

---

## 5. Wire Konnect to KiCad IPC

Two hops must both work:

| Layer | What you see | Meaning |
|---|---|---|
| **Cursor → Konnect** | MCPs → **konnect Connected** | `konnect.exe` runs over stdio |
| **Konnect → KiCad** | `open_project` → **`ipc_available: true`** | Konnect knows the socket path **and** KiCad IPC is up |

**MCP Connected ≠ KiCad IPC connected.**

Cursor-launched Konnect does **not** receive `KICAD_API_SOCKET` from KiCad automatically (that env var is set when KiCad launches **plugins**, not when Cursor spawns `konnect.exe`).

### Option A — `.cursor/mcp.json` (recommended for Cursor)

Add `env.KICAD_API_SOCKET` with the **exact** address from Preferences (§ 2):

```json
{
  "mcpServers": {
    "konnect": {
      "command": "C:\\Users\\<YOU>\\Documents\\KiCad\\10.0\\3rdparty\\plugins\\com_github_mixelpixx_konnect\\bin\\konnect.exe",
      "env": {
        "KICAD_API_SOCKET": "ipc://C:\\Users\\<YOU>\\AppData\\Local\\Temp\\kicad\\api.sock"
      }
    }
  }
}
```

After editing: **Developer: Reload Window**. KiCad must stay running; if you restart KiCad, re-check the listening line — the path can change per session.

### Option B — Konnect settings dialog (KiCad UI)

1. **PCB Editor → Tools → External Plugins → Konnect**.
2. **Advanced → IPC Socket:** paste the same `ipc://…` address.
3. **Save** → creates:

```text
...\com_github_mixelpixx_konnect\settings.json
```

Example keys: `ipc_socket_path`, `kicad_cli`, `transport`, `log_level`.

Option A alone is enough for Cursor. Option B helps when starting Konnect from KiCad.

**Not configured in:** Plugin and Content Manager (install only).

### 5.1 — kicad-cli path (ERC/DRC from Agent)

KiCad installs `kicad-cli.exe` under `Program Files` — it is **not** on PATH by default. The **MCP** `konnect.exe` (Cursor) reads **`%APPDATA%\konnect\config.json`**, not the KiCad plugin `settings.json`.

**Fix (pick one):**

1. **Konnect user config (recommended)** — ask the agent to set `kicad_cli`, or edit:

```json
{
  "kicad_cli": "C:/Program Files/KiCad/10.0/bin/kicad-cli.exe"
}
```

in `%APPDATA%\konnect\config.json` (merge with existing keys). **Reload Cursor** after edit.

2. **System PATH** — add `C:\Program Files\KiCad\10.0\bin` to user or system PATH; restart Cursor.

3. **KiCad plugin settings** — `…\3rdparty\plugins\com_github_mixelpixx_konnect\settings.json` already has `kicad_cli` for Konnect started **from KiCad**; the MCP server in `.cursor/mcp.json` uses the Roaming config above.

**Verify:**

```powershell
& "C:/Program Files/KiCad/10.0/bin/kicad-cli.exe" --version
& "C:/Program Files/KiCad/10.0/bin/kicad-cli.exe" sch erc projects/wanos-board/wanos-board.kicad_sch
```

---

## 6. Verify in Agent chat

With KiCad running, **PCB Editor** open, MCP connected, and IPC env set:

### `open_project` (IPC smoke test)

Ask the agent to run **`open_project`**. Expected:

```json
{
  "kicad_ui_running": true,
  "ipc_available": true,
  "ipc_address": "ipc://C:\\Users\\<YOU>\\AppData\\Local\\Temp\\kicad\\api.sock",
  "open_board_count": 1,
  "open_boards": ["...\\something.kicad_pcb"]
}
```

Optional: pass a project path to check a specific board is open:

```text
open_project on docs/reference/wisc-board/211201 wisc2-5-3/wisc-v5.kicad_pro
```

→ `requested_open: true` when that PCB is the one loaded in PCB Editor.

### Other checks

- **List Konnect toolsets** — expect ~20 toolsets / 200+ tools after `list_toolboxes`.
- **`get_project_info`** — works on `.kicad_pro` paths without IPC (file read).
- **Live PCB edits / save via IPC** — require § 2–3 + § 5.

**File-only mode:** schematic file edits and some reads work **without** IPC. Live PCB undo integration and open-board checks **require** IPC.

---

## 7. Troubleshooting

| Symptom | Likely cause | Fix |
|---|---|---|
| MCP **Connected** but `ipc_available: false` | Konnect has no socket path | Add § 5 Option A or B; reload Cursor |
| `ipc_address: ""` | Same | Same |
| `open_board_count: 0` | PCB Editor not open or no board loaded | Open `.kicad_pcb` in layout (§ 3) |
| No **Listening at …** in Preferences | API off or KiCad started before enable | Restart KiCad; re-check § 2 |
| `api.sock` missing in `%TEMP%\kicad\` | Windows named pipe (§ 2) | Ignore; use Preferences line |
| Konnect not in Agent tools | MCP not loaded | Reload Cursor; check `.cursor/mcp.json` syntax |
| `settings.json` missing | Never saved Konnect dialog | Normal if using Option A only |
| `run_erc` / `Failed to spawn kicad-cli` | MCP Konnect cannot find CLI on PATH | Set `kicad_cli` in `%APPDATA%\\konnect\\config.json` (see § 5.1) **or** add KiCad `bin` to system PATH; reload Cursor |

Enable tracing (optional): KiCad env `KICAD_ENABLE_TRACE=1`, `WXTRACE=KICAD_API` — see [KiCad IPC docs](https://dev-docs.kicad.org/en/apis-and-binding/ipc-api/for-addon-developers/index.html).

---

## 8. Project layout

```text
projects/wanos-board/
  design.yaml
  constraints.md
  bom-targets.yaml
  components.xlsx          # BOM seed (LCSC)
  wanos-board.kicad_*      # Created at S1
  fabrication/
    JLCPCB_BOM_Template.xls
```

Datasheet PDFs → [`reference/datasheets/`](reference/datasheets/README.md) (lowercase filenames; gitignored).

Product spec → [`board-spec.md`](board-spec.md). WISC reference summaries → [`reference/wisc-board/`](reference/wisc-board/).

---

## 9. Verification commands (kicad-cli)

```powershell
$cli = "C:/Program Files/KiCad/10.0/bin/kicad-cli.exe"
$sch = "projects/wanos-board/wanos-board.kicad_sch"
$pcb = "projects/wanos-board/wanos-board.kicad_pcb"

& $cli sch erc $sch
& $cli pcb drc $pcb
```

Do not close **S1** / **L1** until ERC/DRC pass or waivers are in the phase file.

---

## 10. Notes

| Topic | Note |
|---|---|
| PCB tools | KiCad open + board in **PCB Editor** (IPC) |
| Schematic tools | Konnect can edit `.kicad_sch` without KiCad open |
| WISC reference | Read-only under `docs/reference/wisc-board/` — see [`.cursor/rules/wisc-boards-readonly.mdc`](../.cursor/rules/wisc-boards-readonly.mdc) |
| Freerouting | Konnect Specctra pipeline — lock HDMI nets first ([`hdmi-spi-eink.md`](hdmi-spi-eink.md)) |
| LCSC parts | Validate `components.xlsx` C-numbers at **J1** |
| MCP UI | **+ New** opening JSON only is expected — edit `.cursor/mcp.json` |
| Pipeline | **kickoff** before design locks; **implement** before KiCad edits on wanos-pcb-v1 |

| Pipeline | **Ops1** Done **2026-09-01** — [`todo/pipeline.md`](todo/pipeline.md) |

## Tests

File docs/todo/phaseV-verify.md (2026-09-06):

<!-- --- file: docs/todo/phaseV-verify.md -->

# WanOS PCB Phase V — Verification / bring-up

Bench validation, migration, and future full-board software integration.

**Status:** **V1a** open after **Ops3**; **V1b** hold.

**Related:** [`gpio-interface.md`](../gpio-interface.md) · [`hdmi-spi-eink.md`](../hdmi-spi-eink.md) · [`field-wiring.md`](../field-wiring.md) (R2) · [wanos](https://github.com/gitwannes/wanos) · Sequence → [`pipeline.md`](pipeline.md).

**DoD convention:** Last DoD = audit & update ALL `docs/**/*.md` (and root README) against shipped artifacts.

---

## Subphases

| Id | What | Status |
|---|---|---|
| **V1a** | wanos-pcb-v1 + **updated WanOS** (full board map) | **open** (after Ops3) |
| **V1b** | Full board + **future WanOS code** | **hold** |

---

## Ops3 — Receiving + first-article inspection (Sequence #10)

**Prereq:** **J1** boards shipped.

- [ ] Package intact; board rev matches order (`wanos-pcb-v1`)
- [ ] Measure outline ~85×56 mm; mounting holes
- [ ] Visual: solder, connector orientation, no swarf
- [ ] Spot-check critical footprints (J1 HDMI, J40, U4 opto, Q1–Q4)
- [ ] **Do not apply power** until **V1a** checklist started

Record results here (date).

---

## V1a — wanos-pcb-v1 bring-up

### Context

- Production: **WanOS + WISC** today.
- **V1a:** first power-on and field test of **wanos-pcb-v1** with **wanos** updated for expanders, SHT31, and HDMI SPI ([`gpio-interface.md`](../gpio-interface.md)). **No** WISC GPIO adapter.
- **HDMI→SPI:** physical verification ([`hdmi-spi-eink.md`](../hdmi-spi-eink.md)) before relying on e-ink.

### Prereqs

- **Ops3** passed
- **R2** closed — [`external-plant.md`](../external-plant.md), [`grounding.md`](../grounding.md), [`field-wiring.md`](../field-wiring.md)
- **wanos** branch / release with wanos-pcb-v1 drivers (main repo)

### Paper test checklist

| Step | Check |
|---|---|
| 1 | Visual + continuity (GND, no shorts on Pi 5V / J41) |
| 2 | Pi boot from **J41**; board seated; no smoke |
| 3 | SSR outputs idle before WanOS arms GPIO |
| 4 | 12 V at **J14** → opto / expander P6; **12 V removed** → hard-lock in WanOS |
| 5 | Expander inputs: doors, water, kWh (per wanos config) |
| 6 | SHT31 via mux **J9–J12**, **J18** |
| 7 | Sauna buttons **J8** |
| 8 | One SSR channel toggle (bench — safe load) |
| 9 | E-ink via **J1** HDMI after cable/panel verification |
| 10 | Log errata / bodges below |

### Deliverables (docs, not code)

- [ ] **`docs/installer-one-pager.md`** — field connections; external SSR; no mains on PCB
- [ ] **Errata log** (this section) — green wires, part subs
- [ ] Operator **go/no-go** to replace WISC in production

### V1a DoD

- [ ] Checklist complete; results recorded
- [ ] Cutover runbook draft updated (§ below)
- [ ] Last DoD: all `docs/**/*.md` + README audited

---

## Cutover runbook (pipeline Manual)

**Target doc:** `docs/cutover-wisc-to-wanos-pcb-v1.md` (create at V1a close-out).

| Section | Content |
|---|---|
| Preconditions | V1a go, backup WISC board, WanOS version pinned |
| Downtime window | Operator defines |
| Steps | Power down → swap board → rewire per field-wiring → smoke test |
| Rollback | Reinstall WISC; restore prior wiring |
| Future | Full board features when **V1b** WanOS ships |

---

## V1b — Full wanos-pcb-v1 + future WanOS (hold)

**Blocked on WanOS software** in [gitwannes/wanos](https://github.com/gitwannes/wanos) (version **TBD**).

### WanOS code scope (main repo — not implemented here)

| Area | Work |
|---|---|
| I²C expanders | Driver for PCA9554 A/B — pulse, door, button inputs |
| SHT31 plant | TCA9548A mux + **J9–J12**, **J18**; replace SHT11 bit-bang where deployed |
| Extra I/O | Bathroom 2 meters, 2× kWh, on-board I²C LCDs |
| 12 V hard-lock | Integrate expander opto net with sauna safety state machine |
| `config_hardware.yaml` | New schema for expander map vs raw BCM |

Triage future WanOS work in **wanos** pipeline when commanded — pointer only here.

### V1b DoD (stub)

- [ ] Full [`board-spec.md`](../board-spec.md) feature checklist on bench
- [ ] WanOS release noted with version id
- [ ] Last DoD: all `docs/**/*.md` + README audited

---

## Out of scope

- WanOS **implementation** in this repo (**V1b** = main repo)
- WISC board repair

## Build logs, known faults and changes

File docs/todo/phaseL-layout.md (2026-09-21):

<!-- --- file: docs/todo/phaseL-layout.md -->

# WanOS PCB Phase L — Layout

PCB layout for **wanos-pcb-v1** (85 × 56 mm). DRC clean before **Gate-L1** and **Ops2**.

**Status:** **L1** open — **Gate-S1** Done **2026-09-21**; near-term Sequence leads with operator **Ops-Remote1** (wanos-remote), then **L1**.

**Related:** [`board-spec.md`](../board-spec.md) § 7 · [`constraints.md`](../../projects/wanos-board/constraints.md) · Sequence → [`pipeline.md`](pipeline.md).

**DoD convention:** Last DoD = audit & update ALL `docs/**/*.md` (and root README) against shipped artifacts.

---

## Subphases

| Id | What | Status |
|---|---|---|
| **L1** | Placement, routing, DRC, silkscreen | **open** (after Gate-S1) |
| **L2** | Pi-power high-current layout (manual) | **open** (during / after L1) |

---

## L2 — Pi-power high-current layout (manual)

**From schematic (pi_power):** **Q6** `AO3401A` is the 5 V ideal diode — **full Pi load** flows **F1 → Q6 → +5VA → FB1 → J40**.

### Operator manual check (before Gate-L1)

- [ ] **Q6 trace width / copper** sized for **≥ 3 A** peak (Pi 4 + peripherals), short path **F1 → Q6 → +5VA**
- [ ] **F1 → Q6** and **Q6 → bulk (`C1`) / `FB1`** kept tight; avoid thin necks or long detours
- [ ] **Thermal:** Q6 `Rds(on)` × I² — verify pad/via strategy if the FET runs warm under load
- [ ] **Silk / assy note** near **Q6** optional: “5 V ideal diode — high current”

**Agent reminder:** flag **L2** whenever routing pi-power or reviewing layout DRC.

---

## L1 — Layout

### Prereqs

- **Gate-S1** closed (**2026-09-21**)
- Footprints assigned in schematic

### KiCad deliverables (implement phase)

| Task | Notes |
|---|---|
| `wanos-board.kicad_pcb` | Board outline 85×56 mm; MH1–MH4 |
| Zone placement | [`board-spec.md`](../board-spec.md) § 7 — Pi left, logic top, field right, SSR bottom |
| Route | Lock **HDMI/SPI** first; Freerouting/Konnect for other nets |
| DRC | Rules per [`board-spec.md`](../board-spec.md) § 8.2 |
| 3D | Pi header + HDMI clearance check |
| **Silkscreen** | Label all JST (J2=…); **`wanos-pcb-v1`** + rev; pin-1 marks; polarity |

### Layout checklist

- [ ] **L2:** **Q6** carries full Pi current — see [§ L2](#l2--pi-power-high-current-layout-manual)
- [ ] SSR / 12 V area isolated from I²C ([`board-spec.md`](../board-spec.md) § 6)
- [ ] Decoupling at each PCA9554 / TCA9548A
- [ ] Test pads TP1–TP10 accessible
- [ ] Copper pour / grounding per [`grounding.md`](../grounding.md)
- [ ] Assembly drawing notes for hand-solder TH parts (JST, terminals, J40)

### L1 DoD

- [ ] DRC pass or waivers documented
- [ ] Silkscreen reviewed for installer clarity
- [ ] Ready for **Gate-L1** (Sequence #7)
- [ ] Last DoD: all `docs/**/*.md` + README audited

---

## Gate-L1 — Operator layout sign-off

**Pipeline Sequence #7**. **Prereq:** L1 DRC clean.

- [ ] Operator reviews layout PDF + 3D — zones, connector access, silk labels
- [ ] Sign-off recorded here before **Ops2** / **J1**

---

## Out of scope

- Fab order (**J1**)
- Power-on test (**V1a**)

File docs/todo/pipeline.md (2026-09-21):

<!-- --- file: docs/todo/pipeline.md -->

# WanOS PCB — Implementation pipeline

Ordered backlog + closed history. Specs / DoD / locks live in the lettered phase files — not here.

**Last updated:** 2026-09-21 (Gate-S1 Done; S archived; Ops-Remote1 next)

---

## How to use

| Band | Meaning |
|---|---|
| **Done** | Closed (shipped or cancelled) — archive only |
| **Sequence** | All open work, in order. Status: **open** \| **coding** \| **hold** |
| **Ops** | Operator / fab / non-lettered leftovers |

**Status:** `open` = eligible · `coding` = actively being implemented right now · `hold` = parked (prereq, assess-only, or pause).

**Size:** `low` · `mid` · `high` (delivery weight, not calendar days).

**Detail files:**

| Letter | Affinity | File |
|---|---|---|
| **R** | Requirements / architecture | [`_archive/phaseR-requirements.md`](_archive/phaseR-requirements.md) (Done) |
| **S** | Schematic (+ KiCad project) | [`_archive/phaseS-schematic.md`](_archive/phaseS-schematic.md) (Done) |
| **L** | Layout | [`phaseL-layout.md`](phaseL-layout.md) |
| **J** | JLCPCB fabrication pack | [`phaseJ-jlcpcb.md`](phaseJ-jlcpcb.md) |
| **V** | Verification / bring-up | [`phaseV-verify.md`](phaseV-verify.md) |

**Product reference** → `docs/` outside `todo/` — [`board-spec.md`](../board-spec.md) (**wanos-pcb-v1**); remote → [`remotepcb.md`](../remotepcb.md).

**DoD (every phase):** Last step = audit & update all `docs/**/*.md` (+ root README) against shipped artifacts.

When a phase finishes: Sequence → **Done**; trim Sequence only. Fully Done letter tracks → `docs/todo/_archive/`.

---

## Done

| Phase | Notes |
|---|---|
| **Triage** | Input docs promoted **2026-08-31** |
| **Triage** | Full backlog (gates, ops, KiCad, migration) **2026-08-31** |
| **R1** | Spec + BOM contradictions locked **2026-09-01** |
| **R2** | Architecture + plant + BCM locked **2026-09-01** — [`_archive/phaseR-requirements.md`](_archive/phaseR-requirements.md) |
| **Ops1** | Konnect + KiCad 10 + Cursor **2026-09-01** — [`kicad-setup.md`](../kicad-setup.md) |
| **S1** | KiCad schematic **wanos-pcb-v1** ERC **0 errors** **2026-09-01** |
| **Gate-S1** | Operator schematic sign-off (Wannes) **2026-09-21** — [`schematic-signoff.md`](../schematic-signoff.md); S track → [`_archive/phaseS-schematic.md`](_archive/phaseS-schematic.md) |

---

## Sequence

All open items. **Detail** = phase file / Manual section.

```text
#   Status Size Id            What                                               Detail
──  ────── ──── ───────────── ────────────────────────────────────────────────── ──────────────────────────
1   open   mid  Ops-Remote1   Operator: clean wanos-remote schematic + check     pipeline Manual § Ops-Remote1
2   open   high L1            PCB layout 85x56 mm (DRC clean)                    phaseL § L1
3   open   low  Gate-L1       Operator layout sign-off + silkscreen review       pipeline Manual § Gate-L1
4   open   mid  Ops2          Pre-J1 fab readiness (assembly split, qty, stencil) pipeline Manual § Ops2
5   open   mid  J1            JLCPCB export + order + LCSC validate              phaseJ § J1
6   open   low  Ops3          Receiving + first-article inspection               pipeline Manual § Ops3
7   open   mid  V1a           Bring-up: wanos-pcb-v1 + updated WanOS             phaseV § V1a
8   hold   mid  V1b           Full board + future WanOS code                     phaseV § V1b
```

Near-term: **Ops-Remote1** (operator) → **L1** (main carrier) → gates → **J1** → **V1a**. Production WanOS stays on **WISC** until operator cuts over.

---

## Manual checks

### Ops-Remote1 — clean + check remote schematic (Sequence #1)

**Verbatim (2026-09-21):** next item on to-do list is for me/operator to clean the remote-PCB schematic, then to check that remote board

| Step | What |
|---|---|
| 1 | Open [`projects/wanos-remote/`](../../projects/wanos-remote/) in KiCad |
| 2 | Clean schematic (pin attachments, labels, layout on sheet) |
| 3 | Run ERC; fix or waive with notes |
| 4 | Check board vs [`remotepcb.md`](../remotepcb.md) locks |

**Canonical:** [`remotepcb.md`](../remotepcb.md) · project README [`projects/wanos-remote/README.md`](../../projects/wanos-remote/README.md).

### Reference & migration (info)

| Item | Status | Notes |
|---|---|---|
| **Info — WISC board reference upload** | Done | KiCad under [`reference/wisc-board/`](../reference/wisc-board/) |
| **Info — WISC site photos / as-built** | open | Photos of WISC install, SSR cabinet, 12 V safety wiring |
| **WanOS on WISC (production)** | open | [wanos](https://github.com/gitwannes/wanos); not blocked by this repo |
| **Future WanOS ↔ full board (code)** | hold | Main repo expanders / SHT31 — **V1b** |
| **Cutover runbook** | open | [`phaseV-verify.md`](phaseV-verify.md) § Cutover |

### Requirements & docs

| Item | Status | Notes |
|---|---|---|
| **External SSR + 12 V plant model** | Done | [`external-plant.md`](../external-plant.md) |
| **Field harness pinouts** | Done | [`field-wiring.md`](../field-wiring.md) |
| **Grounding / return scheme** | Done | [`grounding.md`](../grounding.md) |
| **Datasheet pack** | open | [`reference/datasheets/`](../reference/datasheets/README.md); `usb-c-j41.pdf` deferred |
| **EN 60335-2-53 assumptions** | hold | Formal safety case = operator |
| **CE / product marking** | hold | Only if scoped later |

### Design gates

| Item | Status | Notes |
|---|---|---|
| **Gate-S1 — schematic sign-off** | **Done** **2026-09-21** | [`schematic-signoff.md`](../schematic-signoff.md) |
| **Gate-L1 — layout sign-off** | open | After **L1** |
| **L2 — Q6 Pi high-current routing** | open | [`phaseL-layout.md`](phaseL-layout.md) § L2 |
| **HDMI→SPI physical verification** | open | Before **V1a** e-ink test |
| **Silkscreen / assembly drawing** | open | **L1** / **Ops2** |

### Tooling (Ops1)

| Item | Status | Notes |
|---|---|---|
| **Ops1 — Konnect + KiCad + Cursor** | **Done** | [`kicad-setup.md`](../kicad-setup.md) |

### Fab & order (Ops2 / J1)

| Item | Status | Notes |
|---|---|---|
| **Ops2 — pre-J1 fab readiness** | open | Sequence |
| **LCSC stock validation** | hold | At **J1** |
| **Prototype revision ID** | open | e.g. `wanos-pcb-v1.0` on silk |
| **Spare parts bag** | open | After first order |

### Receive & bring-up (Ops3 / V1)

| Item | Status | Notes |
|---|---|---|
| **Ops3 — receiving inspection** | open | Sequence |
| **V1a paper test checklist** | open | [`phaseV-verify.md`](phaseV-verify.md) |
| **12 V loss / hard-lock test** | open | **V1a** |
| **Errata log** | open | **V1a** |
| **Installer / electrician one-pager** | open | **V1a** close-out |

---

## Changelog

| Date | Change |
|---|---|
| 2026-08-31 | Full triage: Sequence gates Ops2/3, Manual backlog |
| 2026-09-01 | R1/R2/Ops1/S1 Done; R → `_archive/` |
| 2026-09-21 | Gate-S1 Done (Wannes); S → `_archive/`; Sequence **Ops-Remote1** then **L1** |

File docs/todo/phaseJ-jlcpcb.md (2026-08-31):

<!-- --- file: docs/todo/phaseJ-jlcpcb.md -->

# WanOS PCB Phase J — JLCPCB fabrication pack

Gerber, drill, BOM, CPL, and order for **wanos-pcb-v1**.

**Status:** **J1** open — blocked on **Ops2**.

**Related:** [`jlcpcb-ordering.md`](../jlcpcb-ordering.md) · [`component-selection.md`](../component-selection.md) · [`projects/wanos-board/components.xlsx`](../../projects/wanos-board/components.xlsx) · [`fabrication/JLCPCB_BOM_Template.xls`](../../projects/wanos-board/fabrication/JLCPCB_BOM_Template.xls) · Sequence → [`pipeline.md`](pipeline.md).

**DoD convention:** Last DoD = audit & update ALL `docs/**/*.md` (and root README) against shipped artifacts.

---

## Subphases

| Id | What | Status |
|---|---|---|
| **J1** | Export, validate LCSC, place order | **open** (after Ops2) |

---

## Ops2 — Pre-J1 fab readiness (Sequence #8)

**Prereq:** **Gate-L1** closed. Detail in pipeline Manual § Ops2.

### Decisions (lock before export)

| Topic | Options / notes |
|---|---|
| Prototype qty | Record in order notes |
| Board ID | `wanos-pcb-v1.0` (or operator lock) on silk + JLC comment |
| SMT assembly | Which refs JLC assembles vs bench hand-solder (J40, JST, terminals) |
| Stencil | Required for SMT prototype? |
| Stackup | 2-layer 1.6 mm ENIG per [`board-spec.md`](../board-spec.md) § 8 |

### Ops2 DoD

- [ ] Assembly split documented in this section
- [ ] Operator go to proceed to **J1** export

---

## J1 — Fabrication pack

### Prereqs

- **Ops2** closed

### KiCad / Konnect export (implement phase)

| Output | Tool |
|---|---|
| Gerber + drill zip | Konnect fab pipeline and/or `kicad-cli pcb export gerbers` |
| `bom.csv` | Konnect / `kicad-cli sch export bom` — LCSC column |
| Centroid CPL | Konnect / `kicad-cli pcb export pos` |
| Optional PDF | Assembly + schematic for bench |

Destination: `projects/wanos-board/fabrication/`

### LCSC validation

- [ ] Every SMT line in `components.xlsx` — C-number in stock at JLC
- [ ] Substitutes noted if any part obsolete

### J1 DoD

- [ ] Gerber zip spot-checked (Gerber viewer)
- [ ] JLCPCB order placed — record order id, qty, date here
- [ ] **Spare parts bag** list (pipeline Manual) if applicable
- [ ] Ready for **Ops3** receiving
- [ ] Last DoD: all `docs/**/*.md` + README audited

---

## Out of scope

- Board power-on (**V1a** — after **Ops3**)

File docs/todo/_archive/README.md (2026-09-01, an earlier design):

<!-- --- file: docs/todo/_archive/README.md -->

# Pipeline archive

Closed phase detail files (`phaseX-*.md`) moved here when a track is **Done**.

Active backlog → [`../pipeline.md`](../pipeline.md). Product reference → `docs/` outside `todo/`.

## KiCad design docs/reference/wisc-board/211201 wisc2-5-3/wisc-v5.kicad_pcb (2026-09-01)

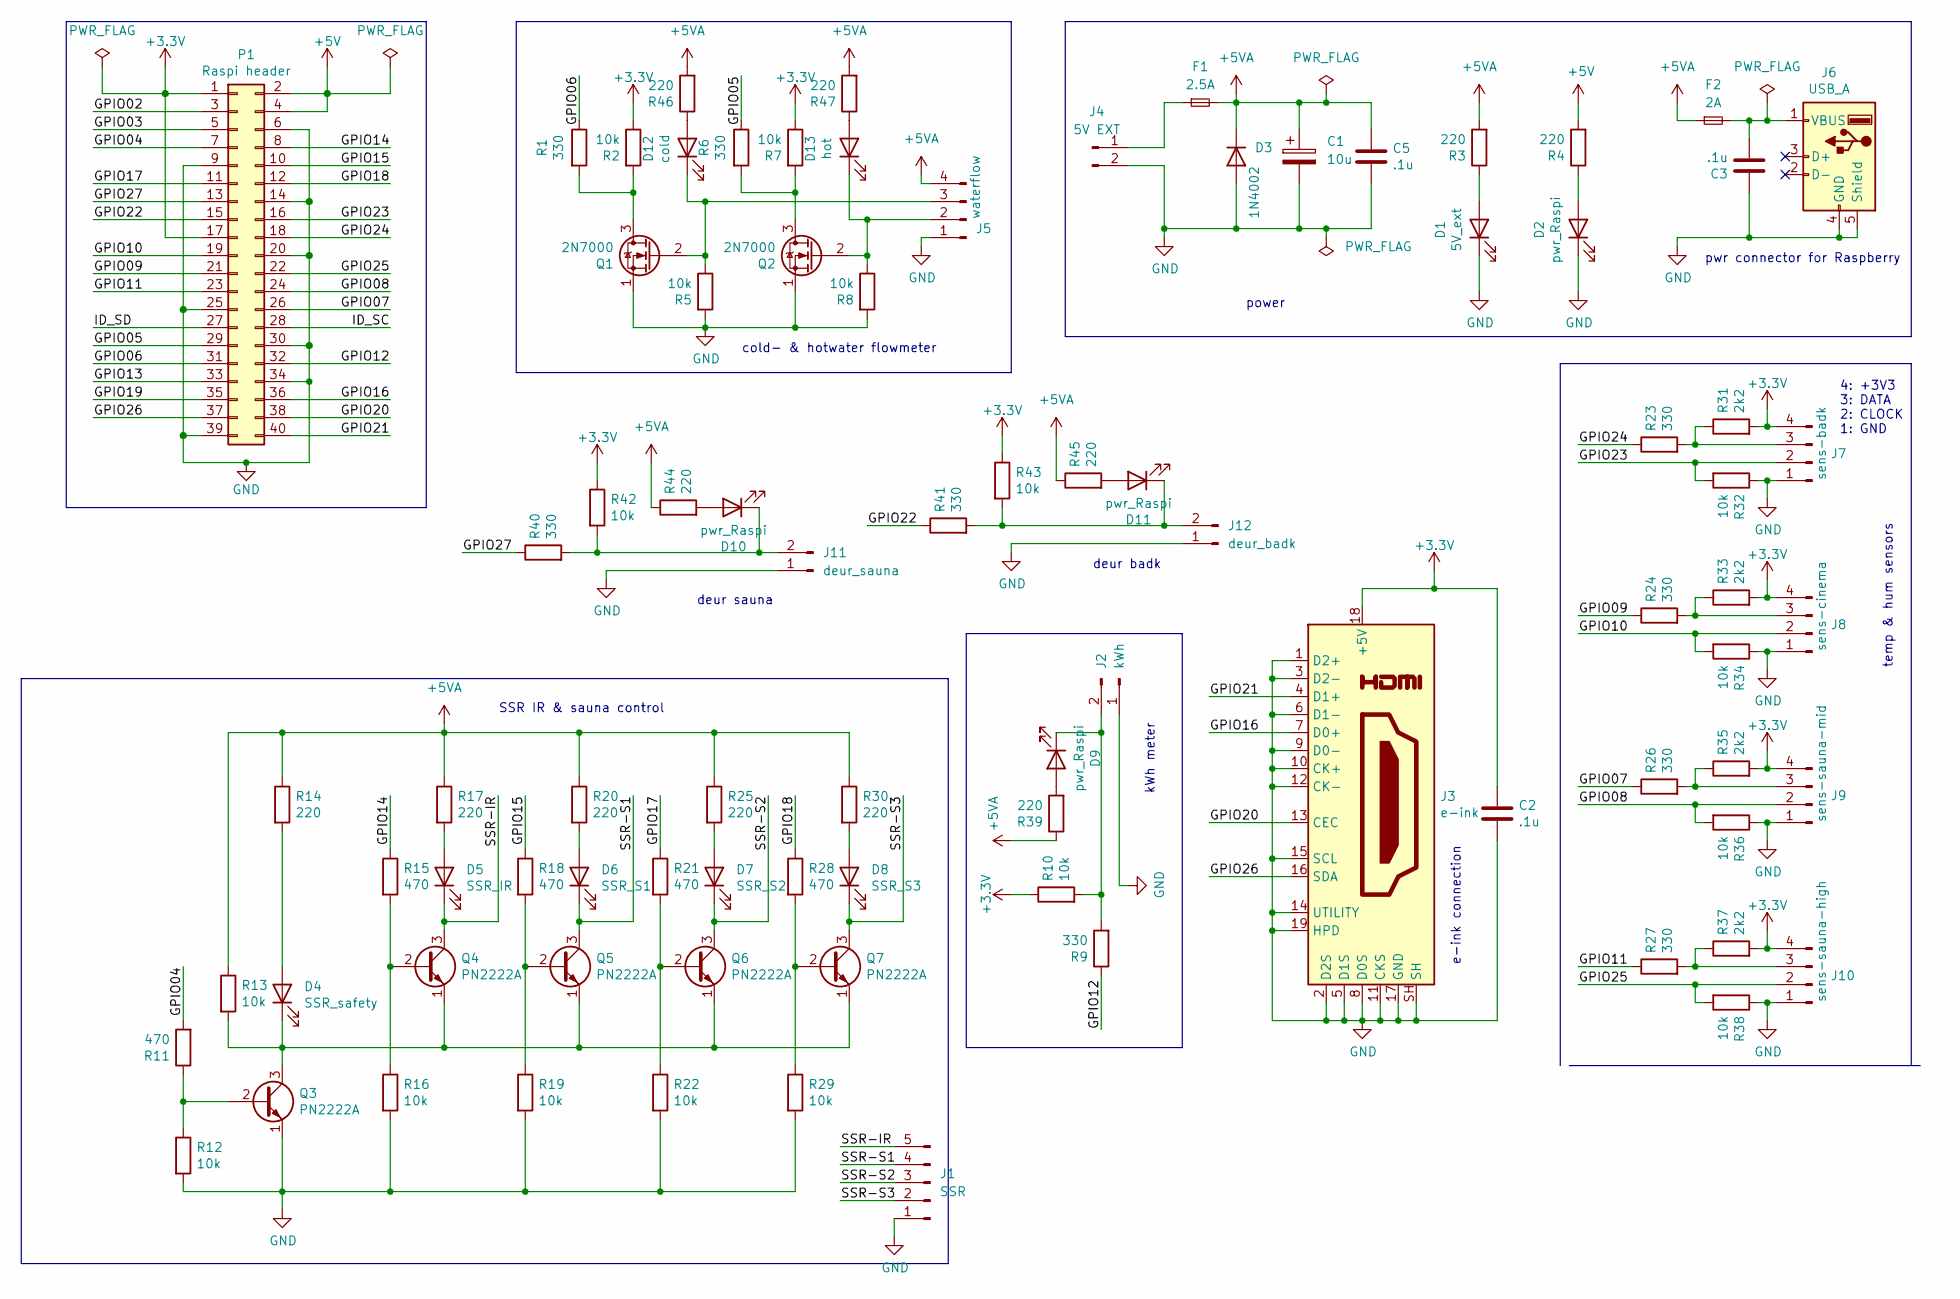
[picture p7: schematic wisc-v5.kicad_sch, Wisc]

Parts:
C1: 10u; CP_Radial_D5.0mm_P2.50mm
C2, C3, C5: .1u; C_Disc_D5.0mm_W2.5mm_P5.00mm
D1: 5V_ext; LED_D3.0mm
D2, D9, D10, D11: pwr_Raspi; LED_D3.0mm
D3: 1N4002; D_DO-41_SOD81_P10.16mm_Horizontal
D4: SSR_safety; LED_D3.0mm
D5: SSR_IR; LED_D3.0mm
D6: SSR_S1; LED_D3.0mm
D7: SSR_S2; LED_D3.0mm
D8: SSR_S3; LED_D3.0mm
D12: cold; LED_D3.0mm
D13: hot; LED_D3.0mm
F1: 2.5A; Fuseholder_Cylinder-5x20mm_Schurter_0031_8201_Horizontal_Op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
F2: 2A; Fuseholder_Cylinder-5x20mm_Schurter_0031_8201_Horizontal_Op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
J1: SSR; JST_XH_B5B-XH-A_1x05_P2.50mm_Vertical
J2: kWh; JST_XH_B2B-XH-A_1x02_P2.50mm_Vertical
J3: e-ink; 17466791
J4: 5V EXT; JST_XH_B2B-XH-A_1x02_P2.50mm_Vertical
J5: waterflow; JST_XH_B4B-XH-A_1x04_P2.50mm_Vertical
J6: USB_A; USB_A_Molex_67643_Horizontal
J7: sens-badk; JST_XH_B4B-XH-A_1x04_P2.50mm_Vertical
J8: sens-cinema; JST_XH_B4B-XH-A_1x04_P2.50mm_Vertical
J9: sens-sauna-mid; JST_XH_B4B-XH-A_1x04_P2.50mm_Vertical
J10: sens-sauna-high; JST_XH_B4B-XH-A_1x04_P2.50mm_Vertical
J11: deur_sauna; JST_XH_B2B-XH-A_1x02_P2.50mm_Vertical
J12: deur_badk; JST_XH_B2B-XH-A_1x02_P2.50mm_Vertical
P1: Raspi header; PinHeader_2x20_P2.54mm_Vertical
Q1, Q2: 2N7000; TO-92_Inline
Q3, Q4, Q5, Q6, Q7: PN2222A; TO-92_Inline
R1, R6, R9, R23, R24, R26, R27, R40, R41: 330; R_Axial_DIN0207_L6.3mm_D2.5mm_P10.16mm_Horizontal
R2, R5, R7, R8, R10, R12, R13, R16, R19, R22, R29, R32, R34, R36, R38, R42, R43: 10k; R_Axial_DIN0207_L6.3mm_D2.5mm_P10.16mm_Horizontal
R3, R4, R14, R17, R20, R25, R30, R39, R44, R45, R46, R47: 220; R_Axial_DIN0207_L6.3mm_D2.5mm_P10.16mm_Horizontal
R11, R15, R18, R21, R28: 470; R_Axial_DIN0207_L6.3mm_D2.5mm_P10.16mm_Horizontal
R31, R33, R35, R37: 2k2; R_Axial_DIN0207_L6.3mm_D2.5mm_P10.16mm_Horizontal

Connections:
+3V3: C2.1, J3.18 (+5V), J7.4, J8.4, J9.4, J10.4, P1.1, P1.17, R2.1, R7.1, R10.1, R31.2, R33.2, R35.2, R37.2, R42.1, R43.1
+5V: P1.2, P1.4, R4.2
+5VA: C1.1, C5.1, D3.1 (K), F1.2, F2.1, J5.4, R3.2, R13.1, R14.1, R17.1, R20.1, R25.1, R30.1, R39.1, R44.1, R45.1, R46.2, R47.2
/GPIO02: P1.3
/GPIO03: P1.5
/GPIO04: P1.7, R11.2
/GPIO05: P1.29, R6.1
/GPIO06: P1.31, R1.1
/GPIO07: P1.26, R26.1
/GPIO08: J9.2, P1.24, R36.2
/GPIO09: P1.21, R24.1
/GPIO10: J8.2, P1.19, R34.2
/GPIO11: P1.23, R27.1
/GPIO12: P1.32, R9.1
/GPIO13: P1.33
/GPIO14: P1.8, R15.1
/GPIO15: P1.10, R18.1
/GPIO16: J3.7 (D0+), P1.36
/GPIO17: P1.11, R21.1
/GPIO18: P1.12, R28.1
/GPIO19: P1.35
/GPIO20: J3.13 (CEC), P1.38
/GPIO21: J3.4 (D1+), P1.40
/GPIO22: P1.15, R41.1
/GPIO23: J7.2, P1.16, R32.2
/GPIO24: P1.18, R23.1
/GPIO25: J10.2, P1.22, R38.2
/GPIO26: J3.16 (SDA), P1.37
/GPIO27: P1.13, R40.1
/ID_SC: P1.28
/ID_SD: P1.27
/SSR-IR: D5.1 (K), J1.5, Q4.3 (C)
/SSR-S1: D6.1 (K), J1.4, Q5.3 (C)
/SSR-S2: D7.1 (K), J1.3, Q6.3 (C)
/SSR-S3: D8.1 (K), J1.2, Q7.3 (C)
GND: C1.2, C2.2, C3.1, C5.2, D1.1 (K), D2.1 (K), D3.2 (A), J1.1, J2.1, J3.1 (D2+), J3.2 (D2S), J3.3 (D2-), J3.5 (D1S), J3.6 (D1-), J3.8 (D0S), J3.9 (D0-), J3.10 (CK+), J3.11 (CKS), J3.12 (CK-), J3.14 (UTILITY), J3.15 (SCL), J3.17 (GND), J3.19 (HPD), J3.SH, J4.2, J5.1, J6.4 (GND), J6.5 (Shield), J7.1, J8.1, J9.1, J10.1, J11.1, J12.1, P1.6, P1.9, P1.14, P1.20, P1.25, P1.30, P1.34, P1.39, Q1.1 (S), Q2.1 (S), Q3.1 (E), R5.2, R8.2, R12.2, R16.2, R19.2, R22.2, R29.2, R32.1, R34.1, R36.1, R38.1
unnamed: C3.2, F2.2, J6.1 (VBUS)
unnamed: D1.2 (A), R3.1
unnamed: D2.2 (A), R4.1
unnamed: D4.1 (K), Q3.3 (C), Q4.1 (E), Q5.1 (E), Q6.1 (E), Q7.1 (E), R13.2
unnamed: D4.2 (A), R14.2
unnamed: D5.2 (A), R17.2
unnamed: D6.2 (A), R20.2
unnamed: D7.2 (A), R25.2
unnamed: D8.2 (A), R30.2
unnamed: D9.1 (K), J2.2, R9.2, R10.2
unnamed: D9.2 (A), R39.2
unnamed: D10.1 (K), J11.2, R40.2, R42.2
unnamed: D10.2 (A), R44.2
unnamed: D11.1 (K), J12.2, R41.2, R43.2
unnamed: D11.2 (A), R45.2
unnamed: D12.1 (K), J5.3, Q1.2 (G), R5.1
unnamed: D12.2 (A), R46.1
unnamed: D13.1 (K), J5.2, Q2.2 (G), R8.1
unnamed: D13.2 (A), R47.1
unnamed: F1.1, J4.1
unnamed: J7.3, R23.2, R31.1
unnamed: J8.3, R24.2, R33.1
unnamed: J9.3, R26.2, R35.1
unnamed: J10.3, R27.2, R37.1
unnamed: Q1.3 (D), R1.2, R2.2
unnamed: Q2.3 (D), R6.2, R7.2
unnamed: Q3.2 (B), R11.1, R12.1
unnamed: Q4.2 (B), R15.2, R16.1
unnamed: Q5.2 (B), R18.2, R19.1
unnamed: Q6.2 (B), R21.2, R22.1
unnamed: Q7.2 (B), R28.2, R29.1

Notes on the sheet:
power
e-ink connection
deur badk
pwr connector for Raspberry
deur sauna
kWh meter
SSR IR & sauna control
temp & hum sensors
4: +3V3 3: DATA 2: CLOCK 1: GND
cold- & hotwater flowmeter

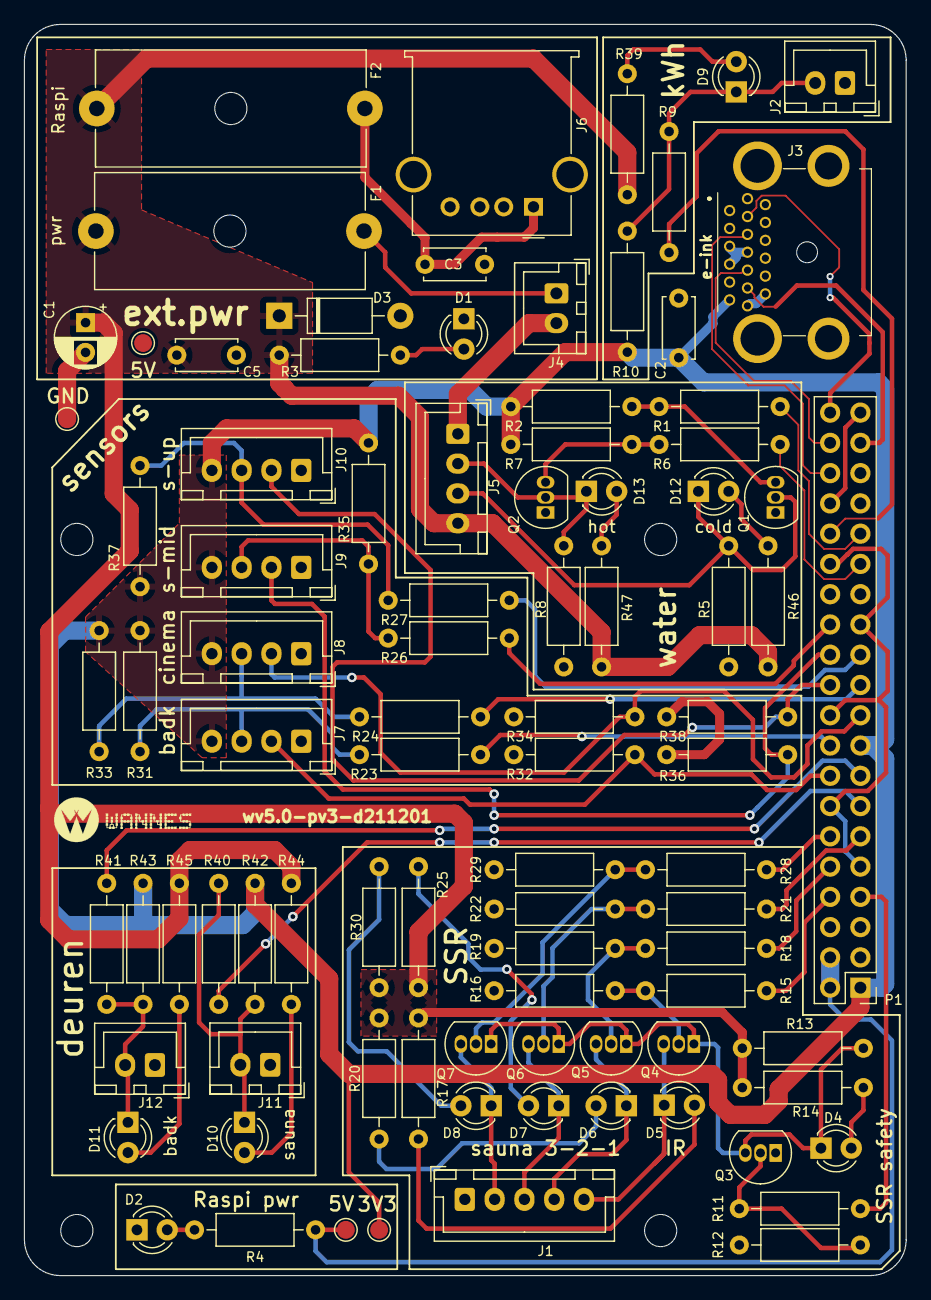
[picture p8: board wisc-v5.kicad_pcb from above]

Board: 2 copper layers, 74.0 x 105.0 mm, 90 parts (0 on the bottom side), 61 nets.

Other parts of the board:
MK1, MK2, MK3, MK4: M2.5; MountingHole_2.7mm_M2.5

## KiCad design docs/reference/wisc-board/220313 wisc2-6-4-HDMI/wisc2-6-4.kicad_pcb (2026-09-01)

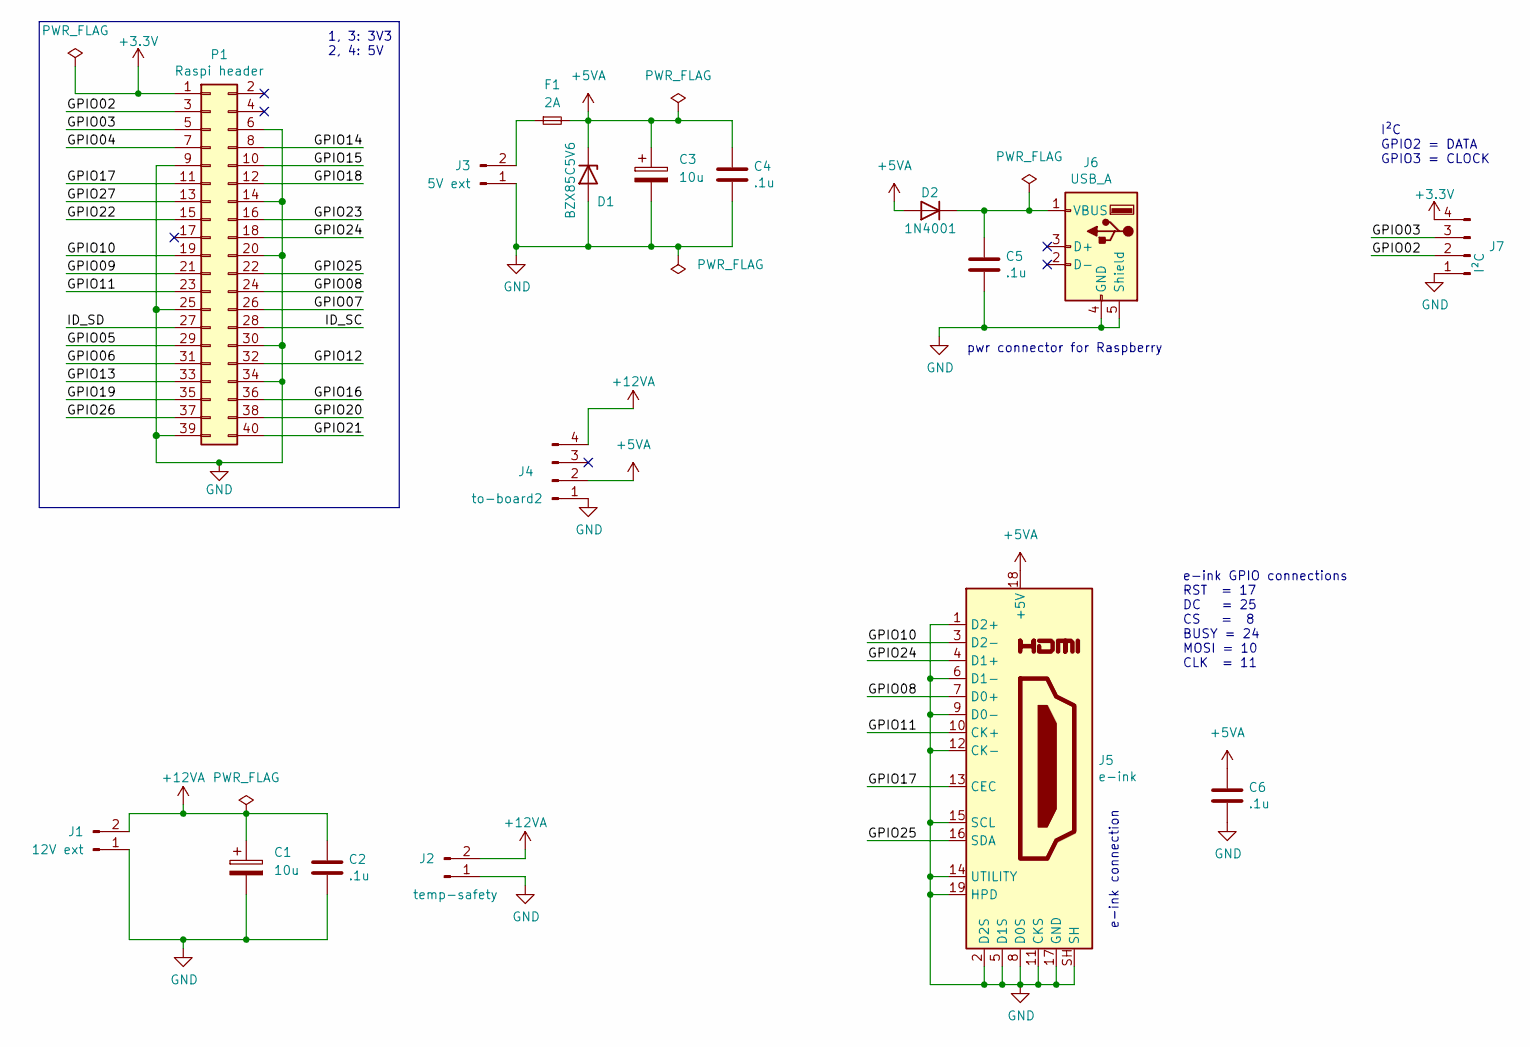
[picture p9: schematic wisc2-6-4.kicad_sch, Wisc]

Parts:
C1, C3: 10u; CP_Radial_D5.0mm_P2.50mm
C2, C4, C5, C6: .1u; C_Disc_D5.0mm_W2.5mm_P5.00mm
D1: BZX85C5V6; D_DO-41_SOD81_P7.62mm_Horizontal
D2: 1N4001; D_DO-41_SOD81_P7.62mm_Horizontal
F1: 2A; Fuseholder_Cylinder-5x20mm_Schurter_0031_8201_Horizontal_Op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
J1: 12V ext; JST_XH_B2B-XH-A_1x02_P2.50mm_Vertical
J2: temp-safety; JST_XH_B2B-XH-A_1x02_P2.50mm_Vertical
J3: 5V ext; JST_XH_B2B-XH-A_1x02_P2.50mm_Vertical
J4: to-board2; JST_XH_B4B-XH-A_1x04_P2.50mm_Vertical
J5: e-ink; 17466791
J6: USB_A; USB_A_Molex_67643_Horizontal
J7: I²C; JST_XH_B4B-XH-A_1x04_P2.50mm_Vertical
P1: Raspi header; PinHeader_2x20_P2.54mm_Vertical

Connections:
+3V3: J7.4, P1.1
+5VA: C3.1, C4.1, C6.1, D1.1 (K), D2.2 (A), F1.2, J4.2, J5.18 (+5V); also elsewhere on the board
+12VA: C1.1, C2.1, J1.2, J2.2, J4.4; also elsewhere on the board
/GPIO02: J7.2, P1.3
/GPIO03: J7.3, P1.5
/GPIO04: P1.7
/GPIO05: P1.29
/GPIO06: P1.31
/GPIO07: P1.26
/GPIO08: J5.7 (D0+), P1.24
/GPIO09: P1.21
/GPIO10: J5.3 (D2-), P1.19
/GPIO11: J5.10 (CK+), P1.23
/GPIO12: P1.32
/GPIO13: P1.33
/GPIO14: P1.8
/GPIO15: P1.10
/GPIO16: P1.36
/GPIO17: J5.13 (CEC), P1.11
/GPIO18: P1.12
/GPIO19: P1.35
/GPIO20: P1.38
/GPIO21: P1.40
/GPIO22: P1.15
/GPIO23: P1.16
/GPIO24: J5.4 (D1+), P1.18
/GPIO25: J5.16 (SDA), P1.22
/GPIO26: P1.37
/GPIO27: P1.13
/ID_SC: P1.28
/ID_SD: P1.27
GND: C1.2, C2.2, C3.2, C4.2, C5.2, C6.2, D1.2 (A), J1.1, J2.1, J3.1, J4.1, J5.1 (D2+), J5.2 (D2S), J5.5 (D1S), J5.6 (D1-), J5.8 (D0S), J5.9 (D0-), J5.11 (CKS), J5.12 (CK-), J5.14 (UTILITY), J5.15 (SCL), J5.17 (GND), J5.19 (HPD), J5.SH, J6.4 (GND), J6.5 (Shield), J7.1, P1.6, P1.9, P1.14, P1.20, P1.25, P1.30, P1.34, P1.39; also elsewhere on the board
unnamed: C5.1, D2.1 (K), J6.1 (VBUS)
unnamed: F1.1, J3.2

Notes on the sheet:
pwr connector for Raspberry
e-ink GPIO connections RST = 17 DC = 25 CS = 8 BUSY = 24 MOSI = 10 CLK = 11
I²C GPIO2 = DATA GPIO3 = CLOCK
e-ink connection
1, 3: 3V3 2, 4: 5V

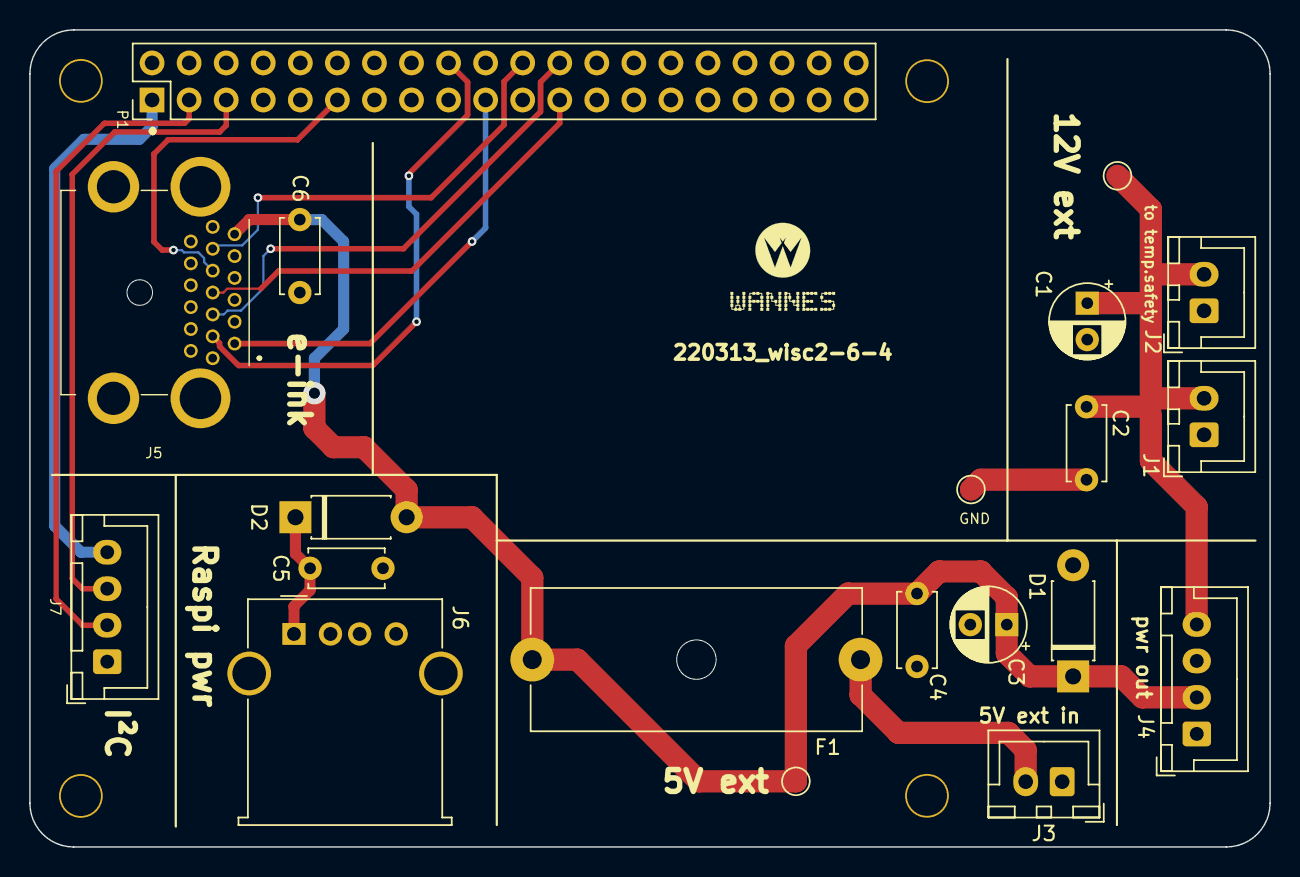
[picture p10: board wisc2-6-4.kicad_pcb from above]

Board: 2 copper layers, 85.0 x 56.0 mm, 24 parts (0 on the bottom side), 14 nets.

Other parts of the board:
5VA, 12V: TestPoint_Pad_D1.5mm
GND: TestPoint_Pad_D1.5mm
H1, H2, H3, H4: 3mm_Mounting_Hole; NPTH_3mm_ID

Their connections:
+5VA: 5VA.1; also elsewhere on the board
+12VA: 12V.1; also elsewhere on the board
GND: GND.1; also elsewhere on the board

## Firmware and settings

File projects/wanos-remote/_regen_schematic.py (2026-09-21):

# --- file: projects/wanos-remote/_regen_schematic.py ---
"""Generate wanos-remote.kicad_sch from docs/remotepcb.md locks."""
from __future__ import annotations

import uuid
from pathlib import Path

ROOT = Path(__file__).resolve().parent
OUT = ROOT / "wanos-remote.kicad_sch"
LOCAL_SYM = ROOT / "wanos-remote.kicad_sym"
KICAD_SYM = Path(r"C:\Program Files\KiCad\10.0\share\kicad\symbols")
SHEET_UUID = "2ab6cac6-33d4-4a9a-8065-7c5b426b4bb1"
PROJ = "wanos-remote"

PIN = {
    "Conn_01x03": {1: (-5.08, 2.54), 2: (-5.08, 0.0), 3: (-5.08, -2.54)},
    "Conn_01x08": {
        1: (-5.08, 7.62),
        2: (-5.08, 5.08),
        3: (-5.08, 2.54),
        4: (-5.08, 0.0),
        5: (-5.08, -2.54),
        6: (-5.08, -5.08),
        7: (-5.08, -7.62),
        8: (-5.08, -10.16),
    },
    "R": {1: (0.0, 3.81), 2: (0.0, -3.81)},
    "C": {1: (0.0, 3.81), 2: (0.0, -3.81)},
    "LED": {1: (-3.81, 0.0), 2: (3.81, 0.0)},
    "D_TVS": {1: (-3.81, 0.0), 2: (3.81, 0.0)},
    "SW": {1: (-5.08, 0.0), 2: (5.08, 0.0)},
}


def uid() -> str:
    return str(uuid.uuid4())


def rot_local(x: float, y: float, rot: int) -> tuple[float, float]:
    r = rot % 360
    if r == 0:
        return x, y
    if r == 90:
        return -y, x
    if r == 180:
        return -x, -y
    if r == 270:
        return y, -x
    raise ValueError(rot)


def pin_xy(ax: float, ay: float, rot: int, kind: str, pin: int) -> tuple[float, float]:
    lx, ly = PIN[kind][pin]
    rx, ry = rot_local(lx, ly, rot)
    return ax + rx, ay - ry


def extract_symbol(text: str, name: str) -> str:
    needle = f'(symbol "{name}"'
    start = text.find(needle)
    if start < 0:
        raise RuntimeError(f"missing {name}")
    i = start + len(needle)
    depth = 1
    while i < len(text) and depth:
        if text[i] == "(":
            depth += 1
        elif text[i] == ")":
            depth -= 1
        i += 1
    return text[start:i]


def load_libs() -> str:
    texts = {
        "Connector_Generic": (KICAD_SYM / "Connector_Generic.kicad_sym").read_text(
            encoding="utf-8"
        ),
        "Device": (KICAD_SYM / "Device.kicad_sym").read_text(encoding="utf-8"),
        "power": (KICAD_SYM / "power.kicad_sym").read_text(encoding="utf-8"),
        "Switch": (KICAD_SYM / "Switch.kicad_sym").read_text(encoding="utf-8"),
        "Regulator_Linear": (KICAD_SYM / "Regulator_Linear.kicad_sym").read_text(
            encoding="utf-8"
        ),
        "Interface_Expansion": (KICAD_SYM / "Interface_Expansion.kicad_sym").read_text(
            encoding="utf-8"
        ),
        "local": LOCAL_SYM.read_text(encoding="utf-8"),
    }
    # (lib_key, bare_name_in_file, embedded_lib_id)
    specs = [
        ("Connector_Generic", "Conn_01x03", "Connector_Generic:Conn_01x03"),
        ("Connector_Generic", "Conn_01x08", "Connector_Generic:Conn_01x08"),
        ("Device", "R", "Device:R"),
        ("Device", "C", "Device:C"),
        ("Device", "LED", "Device:LED"),
        ("Device", "D_TVS", "Device:D_TVS"),
        ("Switch", "SW_Push", "Switch:SW_Push"),
        ("power", "+3V3", "power:+3V3"),
        ("power", "GND", "power:GND"),
        ("Regulator_Linear", "AP2204K-3.3", "Regulator_Linear:AP2204K-3.3"),
        ("Interface_Expansion", "MCP23017x-x-SO", "Interface_Expansion:MCP23017x-x-SO"),
        ("local", "DS2482-800", "DS2482-800"),
        ("local", "TLP281-4", "TLP281-4"),
    ]
    parts: list[str] = []
    for key, bare, lib_id in specs:
        sym = extract_symbol(texts[key], bare)
        if bare != lib_id:
            sym = sym.replace(f'(symbol "{bare}"', f'(symbol "{lib_id}"', 1)
        parts.append(sym)
    return "\n\t\t".join(parts)


def prop(name: str, value: str, x: float, y: float, hide: bool = False) -> str:
    hid = "\n\t\t\t(hide yes)" if hide else ""
    return f"""\t\t(property "{name}" "{value}"
\t\t\t(at {x:g} {y:g} 0)
\t\t\t(show_name no)
\t\t\t(do_not_autoplace no){hid}
\t\t\t(effects
\t\t\t\t(font
\t\t\t\t\t(size 1.27 1.27)
\t\t\t\t)
\t\t\t)
\t\t)"""


def place(
    lib_id: str,
    ref: str,
    value: str,
    x: float,
    y: float,
    rot: int,
    footprint: str,
    pins: list[str],
    unit: int = 1,
) -> str:
    pin_blk = "\n".join(
        f"""\t\t(pin "{p}"
\t\t\t(uuid "{uid()}")
\t\t)"""
        for p in pins
    )
    return f"""\t(symbol
\t\t(lib_id "{lib_id}")
\t\t(at {x:g} {y:g} {rot})
\t\t(unit {unit})
\t\t(body_style 1)
\t\t(exclude_from_sim no)
\t\t(in_bom yes)
\t\t(on_board yes)
\t\t(in_pos_files yes)
\t\t(dnp no)
\t\t(uuid "{uid()}")
{prop("Reference", ref if unit == 1 else f"{ref}", x, y - 5.08)}
{prop("Value", value, x, y + 5.08)}
{prop("Footprint", footprint, x, y, hide=True)}
{prop("Datasheet", "", x, y, hide=True)}
{prop("Description", "", x, y, hide=True)}
{pin_blk}
\t\t(instances
\t\t\t(project "{PROJ}"
\t\t\t\t(path "/{SHEET_UUID}"
\t\t\t\t\t(reference "{ref}")
\t\t\t\t\t(unit {unit})
\t\t\t\t)
\t\t\t)
\t\t)
\t)"""


def place_pwr(lib_id: str, value: str, ref: str, x: float, y: float) -> str:
    return f"""\t(symbol
\t\t(lib_id "{lib_id}")
\t\t(at {x:g} {y:g} 0)
\t\t(unit 1)
\t\t(body_style 1)
\t\t(exclude_from_sim no)
\t\t(in_bom yes)
\t\t(on_board yes)
\t\t(in_pos_files yes)
\t\t(dnp no)
\t\t(uuid "{uid()}")
{prop("Reference", ref, x, y + 3.81, hide=True)}
{prop("Value", value, x, y - 3.81)}
{prop("Footprint", "", x, y, hide=True)}
{prop("Datasheet", "", x, y, hide=True)}
{prop("Description", "", x, y, hide=True)}
\t\t(pin "1"
\t\t\t(uuid "{uid()}")
\t\t)
\t\t(instances
\t\t\t(project "{PROJ}"
\t\t\t\t(path "/{SHEET_UUID}"
\t\t\t\t\t(reference "{ref}")
\t\t\t\t\t(unit 1)
\t\t\t\t)
\t\t\t)
\t\t)
\t)"""


def wire(x1: float, y1: float, x2: float, y2: float) -> str:
    return f"""\t(wire
\t\t(pts
\t\t\t(xy {x1:g} {y1:g})
\t\t\t(xy {x2:g} {y2:g})
\t\t)
\t\t(stroke
\t\t\t(width 0)
\t\t\t(type default)
\t\t)
\t\t(uuid "{uid()}")
\t)"""


def label(name: str, x: float, y: float, rot: int = 0) -> str:
    return f"""\t(global_label "{name}"
\t\t(shape input)
\t\t(at {x:g} {y:g} {rot})
\t\t(effects
\t\t\t(font
\t\t\t\t(size 1.27 1.27)
\t\t\t)
\t\t\t(justify left)
\t\t)
\t\t(uuid "{uid()}")
\t\t(property "Intersheetrefs" "${{INTERSHEET_REFS}}"
\t\t\t(at {x:g} {y:g} 0)
\t\t\t(show_name no)
\t\t\t(do_not_autoplace no)
\t\t\t(effects
\t\t\t\t(font
\t\t\t\t\t(size 1.27 1.27)
\t\t\t\t)
\t\t\t\t(hide yes)
\t\t\t)
\t\t)
\t)"""


def nc(x: float, y: float) -> str:
    return f"""\t(no_connect
\t\t(at {x:g} {y:g})
\t\t(uuid "{uid()}")
\t)"""


def note(body: str, x: float, y: float) -> str:
    esc = body.replace("\\", "\\\\").replace('"', '\\"')
    return f"""\t(text "{esc}"
\t\t(exclude_from_sim no)
\t\t(at {x:g} {y:g} 0)
\t\t(effects
\t\t\t(font
\t\t\t\t(size 1.27 1.27)
\t\t\t)
\t\t\t(justify left bottom)
\t\t)
\t\t(uuid "{uid()}")
\t)"""


def main() -> None:
    o: list[str] = []
    pn = 1

    def gnd(x: float, y: float) -> None:
        nonlocal pn
        o.append(place_pwr("power:GND", "GND", f"#PWR{pn}", x, y))
        pn += 1

    def v3(x: float, y: float) -> None:
        nonlocal pn
        o.append(place_pwr("power:+3V3", "+3V3", f"#PWR{pn}", x, y))
        pn += 1

    fp_r = "Resistor_SMD:R_0603_1608Metric"
    fp_c = "Capacitor_SMD:C_0805_2012Metric"
    fp_led = "LED_SMD:LED_0603_1608Metric"
    fp_tvs = "Diode_SMD:D_SMB"
    fp_esd = "Diode_SMD:D_SOD-323"
    fp_j3 = "Connector_JST:JST_XH_B3B-XH-A_1x03_P2.50mm_Vertical"
    fp_rj = "Connector_RJ:RJ45_Amphenol_54602-x08_Horizontal"
    fp_sw = "Button_Switch_SMD:SW_SPST_PTS645"
    fp_mcp = "Package_SO:SOIC-28W_7.5x17.9mm_P1.27mm"
    fp_ds = "Package_SO:TSSOP-16_4.4x5mm_P0.65mm"
    fp_ldo = "Package_TO_SOT_SMD:SOT-23-5"
    fp_tlp = "Package_SO:SOIC-16_3.9x9.9mm_P1.27mm"

    o.append(
        note(
            "wanos-remote v0.1 — docs/remotepcb.md\\n"
            "MCP 0x22 GPA0-3 pulses; DS2482 0x18 IO0-3; no INT; VIN SMBJ12A",
            25,
            195,
        )
    )

    # === J1 RJ45 ===
    # T568B: 1=SCL_J 2=GND 3=SDA_J 6=GND 5=VIN 4=GND 7=GND 8=GND
    jx, jy = 35, 160
    o.append(
        place(
            "Connector_Generic:Conn_01x08",
            "J1",
            "RJ45",
            jx,
            jy,
            0,
            fp_rj,
            [str(i) for i in range(1, 9)],
        )
    )
    jack = {
        1: "I2C_SCL_J",
        2: "GND",
        3: "I2C_SDA_J",
        4: "GND",
        5: "VIN",
        6: "GND",
        7: "GND",
        8: "GND",
    }
    for p, net in jack.items():
        px, py = pin_xy(jx, jy, 0, "Conn_01x08", p)
        lx = px - 15.24
        o.append(wire(px, py, lx, py))
        if net == "GND":
            gnd(lx, py)
        else:
            o.append(label(net, lx, py, 180))
    o.append(note("J1 T568B: 1 SCL 2 GND 3 SDA 6 GND | 5 VIN 4 GND | 7-8 GND", 20, 175))

    # D10 SMBJ12A VIN-GND
    o.append(place("Device:D_TVS", "D10", "SMBJ12A", 70, 175, 90, fp_tvs, ["1", "2"]))
    o.append(label("VIN", 70, 185, 90))
    gnd(70, 165)

    # R17 S0_RAIL
    o.append(place("Device:R", "R17", "10R", 85, 160, 0, fp_r, ["1", "2"]))
    o.append(label("VIN", 85, 168, 90))
    o.append(label("S0_RAIL", 85, 152, 270))
    o.append(place("Device:C", "C5", "10u", 95, 155, 0, fp_c, ["1", "2"]))
    o.append(label("S0_RAIL", 95, 163, 90))
    gnd(95, 147)
    o.append(place("Device:C", "C6", "100n", 105, 155, 0, fp_c, ["1", "2"]))
    o.append(label("S0_RAIL", 105, 163, 90))
    gnd(105, 147)

    # Power LED
    o.append(place("Device:R", "R18", "6k8", 120, 170, 0, fp_r, ["1", "2"]))
    o.append(label("S0_RAIL", 120, 178, 90))
    o.append(label("LED_PWR", 120, 162, 270))
    o.append(place("Device:LED", "D9", "PWR", 120, 150, 0, fp_led, ["1", "2"]))
    o.append(label("LED_PWR", 125, 150, 0))
    gnd(115, 150)

    # LDO U4
    o.append(
        place(
            "Regulator_Linear:AP2204K-3.3",
            "U4",
            "AP2204K-3.3",
            150,
            165,
            0,
            fp_ldo,
            ["1", "2", "3", "4", "5"],
        )
    )
    o.append(label("VIN", 138, 167.54, 180))
    o.append(label("VIN", 138, 165, 180))  # EN
    o.append(label("+3V3", 162, 167.54, 0))
    gnd(150, 155)
    o.append(nc(157, 165))
    o.append(place("Device:C", "C7", "100u", 135, 185, 0, fp_c, ["1", "2"]))
    o.append(label("VIN", 135, 193, 90))
    gnd(135, 177)
    o.append(place("Device:C", "C8", "100n", 145, 185, 0, fp_c, ["1", "2"]))
    o.append(label("VIN", 145, 193, 90))
    gnd(145, 177)
    o.append(place("Device:C", "C15", "2u2", 160, 185, 0, fp_c, ["1", "2"]))
    o.append(label("+3V3", 160, 193, 90))
    gnd(160, 177)
    o.append(place("Device:C", "C9", "47u", 170, 185, 0, fp_c, ["1", "2"]))
    o.append(label("+3V3", 170, 193, 90))
    gnd(170, 177)
    o.append(place("Device:C", "C13", "100n", 180, 185, 0, fp_c, ["1", "2"]))
    o.append(label("+3V3", 180, 193, 90))
    gnd(180, 177)
    v3(190, 190)

    # I2C series R19/R20: jack <-> chip
    o.append(place("Device:R", "R19", "22R", 70, 140, 90, fp_r, ["1", "2"]))
    o.append(label("I2C_SDA_J", 70, 150, 90))
    o.append(label("I2C_SDA", 70, 130, 270))
    o.append(place("Device:R", "R20", "22R", 85, 140, 90, fp_r, ["1", "2"]))
    o.append(label("I2C_SCL_J", 85, 150, 90))
    o.append(label("I2C_SCL", 85, 130, 270))

    # === 4 pulse channels ===
    tlp_pins = [
        ["1", "2", "9", "10"],
        ["3", "4", "11", "12"],
        ["5", "6", "13", "14"],
        ["7", "8", "15", "16"],
    ]
    for ch in range(1, 5):
        y = 115 - (ch - 1) * 30
        # JST J2-J5
        o.append(
            place(
                "Connector_Generic:Conn_01x03",
                f"J{ch + 1}",
                f"PULSE{ch}",
                30,
                y,
                0,
                fp_j3,
                ["1", "2", "3"],
            )
        )
        a = pin_xy(30, y, 0, "Conn_01x03", 1)
        s = pin_xy(30, y, 0, "Conn_01x03", 2)
        g_ = pin_xy(30, y, 0, "Conn_01x03", 3)
        o.append(wire(a[0], a[1], a[0] - 12.7, a[1]))
        o.append(label("S0_RAIL", a[0] - 12.7, a[1], 180))
        o.append(wire(s[0], s[1], s[0] - 12.7, s[1]))
        o.append(label(f"SIG{ch}", s[0] - 12.7, s[1], 180))
        o.append(wire(g_[0], g_[1], g_[0] - 7.62, g_[1]))
        gnd(g_[0] - 7.62, g_[1])

        o.append(place("Device:R", f"R{8 + ch}", "4k7", 55, y + 7.62, 0, fp_r, ["1", "2"]))
        o.append(label("S0_RAIL", 55, y + 15, 90))
        o.append(label(f"OPTO_A{ch}", 55, y, 270))

        o.append(
            place(
                "TLP281-4",
                "U1",
                "TLP281-4",
                75,
                y,
                0,
                fp_tlp,
                tlp_pins[ch - 1],
                unit=ch,
            )
        )
        # Labels for opto (positions approximate; ERC may need nudge in UI)
        o.append(label(f"OPTO_A{ch}", 62, y + 2.54, 0))
        o.append(label(f"SIG{ch}", 62, y - 2.54, 0))
        o.append(label(f"OPTO_C{ch}", 88, y + 2.54, 0))
        gnd(88, y - 2.54)

        o.append(place("Device:R", f"R{ch}", "470R", 105, y + 2.54, 90, fp_r, ["1", "2"]))
        o.append(label(f"OPTO_C{ch}", 105, y + 12, 90))
        o.append(label(f"PULSE_CH{ch}", 105, y - 6, 270))

        o.append(place("Device:R", f"R{4 + ch}", "10k", 120, y + 10, 0, fp_r, ["1", "2"]))
        o.append(label("+3V3", 120, y + 18, 90))
        o.append(label(f"PULSE_CH{ch}", 120, y + 4, 270))
        o.append(place("Device:C", f"C{ch}", "100n", 130, y + 4, 0, fp_c, ["1", "2"]))
        o.append(label(f"PULSE_CH{ch}", 130, y + 12, 90))
        gnd(130, y - 4)
        o.append(place("Device:D_TVS", f"D{ch}", "ESD5B5.0", 140, y + 4, 90, fp_esd, ["1", "2"]))
        o.append(label(f"PULSE_CH{ch}", 140, y + 12, 90))
        gnd(140, y - 4)

        o.append(place("Device:LED", f"D{4 + ch}", "ACT", 155, y + 10, 0, fp_led, ["1", "2"]))
        o.append(label("LED_ACT", 148, y + 10, 180))
        o.append(place("Device:R", f"R{12 + ch}", "1k0", 170, y + 10, 90, fp_r, ["1", "2"]))
        o.append(label(f"PULSE_CH{ch}", 170, y + 2, 270))
        # LED cathode path: LED K -> R -> PULSE (anode on LED_ACT)
        o.append(label(f"ACT_K{ch}", 160, y + 10, 0))
        o.append(label(f"ACT_K{ch}", 170, y + 18, 90))

    o.append(place("Switch:SW_Push", "SW1", "TEST", 190, 40, 0, fp_sw, ["1", "2"]))
    o.append(label("+3V3", 178, 40, 180))
    o.append(label("LED_ACT", 202, 40, 0))

    # === MCP U3 ===
    o.append(
        place(
            "Interface_Expansion:MCP23017x-x-SO",
            "U3",
            "MCP23017A",
            230,
            95,
            0,
            fp_mcp,
            [str(i) for i in range(1, 29)],
        )
    )
    o.append(
        note(
            "U3 MCP23017A 0x22\\nGPA0-3=PULSE_CH1-4\\nA0=GND A1=+3V3 A2=GND\\n"
            "~RESET=+3V3 INTA/INTB NC\\nunused GPIO NC (FW drive LOW)",
            210,
            130,
        )
    )
    o.append(label("I2C_SCL", 210, 115, 180))
    o.append(label("I2C_SDA", 210, 112, 180))
    o.append(label("+3V3", 210, 92, 180))  # RESET
    o.append(nc(212, 100))
    o.append(nc(212, 97))
    gnd(210, 80)  # A0
    o.append(label("+3V3", 210, 77, 180))  # A1
    gnd(210, 74)  # A2
    o.append(label("+3V3", 230, 125, 90))
    gnd(230, 65)
    o.append(label("PULSE_CH1", 250, 115, 0))
    o.append(label("PULSE_CH2", 250, 112, 0))
    o.append(label("PULSE_CH3", 250, 109, 0))
    o.append(label("PULSE_CH4", 250, 106, 0))
    for yy in range(60, 105, 3):
        o.append(nc(248, float(yy)))
    o.append(place("Device:C", "C12", "100n", 260, 125, 0, fp_c, ["1", "2"]))
    o.append(label("+3V3", 260, 133, 90))
    gnd(260, 117)
    o.append(place("Device:C", "C10", "10u", 270, 125, 0, fp_c, ["1", "2"]))
    o.append(label("+3V3", 270, 133, 90))
    gnd(270, 117)

    # === DS2482 U2 ===
    o.append(
        place(
            "DS2482-800",
            "U2",
            "DS2482-800",
            320,
            100,
            0,
            fp_ds,
            [str(i) for i in range(1, 17)],
        )
    )
    o.append(
        note(
            "U2 DS2482-800 0x18\\nIO0-3 temps IO4-7 NC\\nAD0-2=GND",
            300,
            130,
        )
    )
    o.append(label("I2C_SDA", 295, 108, 180))
    o.append(label("I2C_SCL", 295, 105, 180))
    o.append(label("+3V3", 320, 120, 90))
    gnd(320, 80)
    o.append(label("OW0", 345, 110, 0))
    o.append(label("OW1", 345, 107, 0))
    o.append(label("OW2", 345, 104, 0))
    o.append(label("OW3", 345, 101, 0))
    for yy in (95, 92, 89, 86):
        o.append(nc(343, float(yy)))
    gnd(295, 95)
    gnd(295, 92)
    gnd(295, 89)
    o.append(nc(295, 86))
    o.append(place("Device:C", "C11", "100n", 340, 125, 0, fp_c, ["1", "2"]))
    o.append(label("+3V3", 340, 133, 90))
    gnd(340, 117)
    o.append(place("Device:C", "C14", "100n", 350, 125, 0, fp_c, ["1", "2"]))
    o.append(label("+3V3", 350, 133, 90))
    gnd(350, 117)

    for i in range(4):
        y = 55 - i * 18
        o.append(place("Device:R", f"R{21 + i}", "2k2", 300, y, 0, fp_r, ["1", "2"]))
        o.append(label("+3V3", 300, y + 8, 90))
        o.append(label(f"OW{i}", 300, y - 8, 270))
        o.append(
            place(
                "Connector_Generic:Conn_01x03",
                f"J{6 + i}",
                f"TEMP{i + 1}",
                330,
                y,
                0,
                fp_j3,
                ["1", "2", "3"],
            )
        )
        t1 = pin_xy(330, y, 0, "Conn_01x03", 1)
        t2 = pin_xy(330, y, 0, "Conn_01x03", 2)
        t3 = pin_xy(330, y, 0, "Conn_01x03", 3)
        o.append(wire(t1[0], t1[1], t1[0] - 10, t1[1]))
        o.append(label("+3V3", t1[0] - 10, t1[1], 180))
        o.append(wire(t2[0], t2[1], t2[0] - 10, t2[1]))
        o.append(label(f"OW{i}", t2[0] - 10, t2[1], 180))
        o.append(wire(t3[0], t3[1], t3[0] - 7, t3[1]))
        gnd(t3[0] - 7, t3[1])

    sch = f"""(kicad_sch
\t(version 20250610)
\t(generator "wanos-remote-_regen_schematic")
\t(generator_version "1.0")
\t(uuid "{SHEET_UUID}")
\t(paper "A3")
\t(title_block
\t\t(title "wanos-remote")
\t\t(date "2026-09-21")
\t\t(rev "0.1")
\t\t(company "wanos")
\t\t(comment 1 "4x opto pulse + 4x DS18B20 / DS2482-800")
\t\t(comment 2 "docs/remotepcb.md")
\t)
\t(lib_symbols
\t\t{load_libs()}
\t)
{chr(10).join(o)}
\t(sheet_instances
\t\t(path "/"
\t\t\t(page "1")
\t\t)
\t)
\t(embedded_fonts no)
)
"""
    OUT.write_text(sch, encoding="utf-8")
    print(f"Wrote {OUT} ({OUT.stat().st_size} bytes)")


if __name__ == "__main__":
    main()

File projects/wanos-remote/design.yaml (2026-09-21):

# --- file: projects/wanos-remote/design.yaml ---
# Design intent — wanos-remote (draft 2026-09-21)

name: wanos-remote
revision: wanos-remote-v0.1
description: >
  Universal plant remote — 4x opto-isolated pulse inputs + 4x DS18B20 via DS2482-800,
  Cat5 uplink to main TCA9548A (ch5 water / ch6 kWh). 40x60 mm target.
kicadVersion: "10.0"

spec: docs/remotepcb.md
bomSeed: projects/wanos-board/components.xlsx  # filter board=remote
mainCarrier: projects/wanos-board/
datasheets: docs/reference/datasheets/

rails:
  - name: VIN
    voltage: 12.0
    notes: From main +12V over Cat5; SMBJ12A local; min 11.5 V at board
  - name: S0_RAIL
    voltage: 12.0
    notes: VIN via 10R + bulk; opto LEDs + YF VDD + power LED
  - name: LOGIC_3V3
    voltage: 3.3
    notes: AP2204K-3.3 from VIN
  - name: GND
    voltage: 0

blocks:
  - id: uplink
    description: RJ45 J1 — I2C + VIN + GND (no INT); pair map remotepcb.md §5
  - id: power
    description: D10 SMBJ12A; R17/C5/C6 S0_RAIL; U4 AP2204; power LED D9
  - id: pulse
    description: U1 TLP281-4 + J2-J5; MCP U3 GPA0-3; activity LEDs + SW1
  - id: onewire
    description: U2 DS2482-800 @ 0x18; J6-J9; IO4-7 NC

i2c:
  mcp23017a: "0x22"
  ds2482_800: "0x18"

constraints:
  boardSizeMm: [40, 60]
  layers: 2
  thicknessMm: 1.6
  surfaceFinish: ENIG
  tooling: Konnect + KiCad 10
  regenerate: python projects/wanos-remote/_regen_schematic.py

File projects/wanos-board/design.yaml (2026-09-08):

# --- file: projects/wanos-board/design.yaml ---
# Design intent — wanos-pcb-v1 (R1 + R2 locked 2026-09-01)

name: wanos-board
revision: wanos-pcb-v1.0
description: Raspberry Pi 4 carrier — expanders, SSR drives, SHT31 mux plant, HDMI-SPI e-ink, 85x56 mm
kicadVersion: "10.0"

wanosRepo: https://github.com/gitwannes/wanos
spec: docs/board-spec.md
fieldWiring: docs/field-wiring.md
externalPlant: docs/external-plant.md
grounding: docs/grounding.md
gpioMap: docs/gpio-interface.md
bomSeed: projects/wanos-board/components.xlsx
datasheets: docs/reference/datasheets/

wiscReference: docs/reference/wisc-board/

targetPi: Raspberry Pi 4
mechanicalReference: docs/reference/wisc-board/wisc-v2-6-4-hdmi.md

rails:
  - name: PI_5V
    voltage: 5.0
    notes: J17 screw terminal -> +5VA -> J40 pins 2/4; J41 DNP
  - name: LOGIC_3V3
    voltage: 3.3
    notes: From Pi
  - name: SSR_12V
    voltage: 12.0
    notes: J14 +12V after external safety; monitored U4 on pi_power
  - name: GND
    voltage: 0

blocks:
  - id: pi_power
    description: J17 + J14 screw terminals; 5V conditioning, D3 TVS, FB1, J40; status D23/D24; U4 12V monitor; J41 DNP
    doc: docs/gpio-interface.md
  - id: io_expanders
    description: PCA9554 x2 + J4 water + J8 buttons; legacy J2/J3/J6/J7 stubs until Pulse_Inputs cutover
    doc: docs/io-expander-map.md
  - id: pulse_inputs
    description: Greenfield door reed J2/J3 (+3V3 front-end) + kWh SDM72 J6/J7 (+5VA front-end)
    doc: docs/field-wiring.md
  - id: water_meters
    description: "REMOVED as sheet - water lives on io_expanders (J4)"
    doc: docs/field-wiring.md
  - id: sht31_plant
    description: TCA9548A mux — 5x SHT31 @ 0x44 on ch0-4 (J9-J12, J18); ch5-7 NC; ~4-5m Cat5
    doc: docs/field-wiring.md
  - id: ssr_drivers
    description: Pi GPIO -> PN2222A x4 -> J13 5-pin; safety BCM4 on-board
    doc: docs/external-plant.md
  - id: eink_hdmi_spi
    description: Molex 208658-1052 J1 — SPI per hdmi-spi-eink.md
    doc: docs/hdmi-spi-eink.md
  - id: lcd_i2c
    description: 1x 4-pin I2C J16 (2 LCDs paralleled; root bus, not muxed)
    doc: docs/field-wiring.md

constraints:
  boardSizeMm: [85, 56]
  layers: 2
  thicknessMm: 1.6
  surfaceFinish: ENIG
  minTrackWidthMm: 0.25
  minClearanceMm: 0.2
  tooling: Konnect + KiCad 10
  silkscreenFont: https://www.fontspace.com/printed-circuit-board-7-font-f15777
  silkscreenRevision: wanos-pcb-v1.0
  jlcpcbAssembly: full PCBA including J40; LCSC C6990958 HDMI

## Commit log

2026-08-31 add initial PCB requirements and info add license
    [JLCPCB_BOM_Template.xls, components.xlsx]
2026-09-01 add WISC reference boards update Kicad MCP connection setup
    [BOM 211206.xlsx, wisc-v5.kicad_pcb, wisc-v5.kicad_sch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]
2026-09-02 Cursor-generated Kicad files
    [components.xlsx, connectors.kicad_sch, hdmi_spi.kicad_sch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]
2026-09-02 pi_power & 12V_monitor schematics OK added datasheets doc update
    [components.xlsx, connectors.kicad_sch, hdmi_spi.kicad_sch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]
2026-09-04 SSR, power, IO_expander schemas update
    [connectors.kicad_sch, hdmi_spi.kicad_sch, io_expanders.kicad_sch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]
2026-09-04 1st draft: water meters schematic
    [connectors.kicad_sch, io_expanders.kicad_sch, wanos-board.kicad_sch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]
2026-09-04 add RJ45 & TVS
    [connectors.kicad_sch, water_meters.kicad_sch]
2026-09-04 watermeters schematic 2nd pass
    [connectors.kicad_sch, water_meters.kicad_sch]
2026-09-04 adjusted water schema add datasheets
    [water_meters.kicad_sch]
2026-09-04 water meters schematic complete
2026-09-05 I2C schema edit
    [i2c_plant.kicad_sch]
2026-09-06 regenerate I2C sheet with 8x mux & additional SHT31
    [i2c_plant.kicad_sch]
2026-09-08 schema updates
    [connectors.kicad_sch, i2c_plant.kicad_sch, io_expanders.kicad_sch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]
2026-09-20 remote PCB draft
2026-09-21 remote pcb design
2026-09-21 1st draft PCB KiCad
    [components.xlsx, wanos-remote.kicad_pcb, wanos-remote.kicad_sch]
2026-09-21 ready for remote board to manually check
